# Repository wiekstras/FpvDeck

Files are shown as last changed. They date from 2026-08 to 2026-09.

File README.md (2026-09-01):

<p align="center">
  FpvDeck — radio, video, flight computer
</p>

<p align="center">
  
  
  
</p>

# FpvDeck

FpvDeck is a custom FPV handheld computer and radio built around a RadioMaster
T8L donor controller. It keeps ELRS control independent while adding low-latency
analog video, a large HD color display, modern RGB overlays, local flight data,
capacitive multi-touch, and modular applications in one field-ready device.

The desktop product shell works today without hardware, and a minimal real-video
Prototype 0 now has selected orderable reference hardware and V4L2 software support.
The final RF, video-decoder,
power, battery-measurement, and enclosure designs remain engineering prototypes;
this repository calls that distinction out rather than presenting renders as
finished hardware.

## Preview

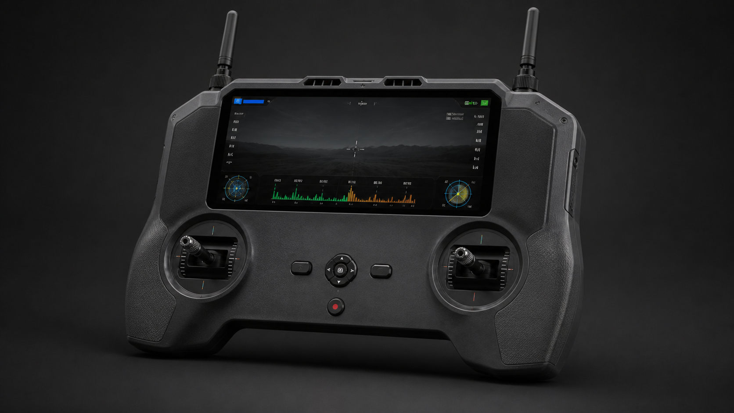
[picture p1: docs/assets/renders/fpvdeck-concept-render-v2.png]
FpvDeck concept with a large integrated display and pinch-grip geometry


> **CONCEPT RENDER — NOT FINAL DESIGN OR CAD.** Dimensions, component fit,
> thermal behavior, antenna placement, and T8L geometry are unverified. The
> larger high-mounted screen and pinch-grip clearance express product direction.

| Desktop product shell | FPV view: source pixels + independent RGB overlay |
| --- | --- |
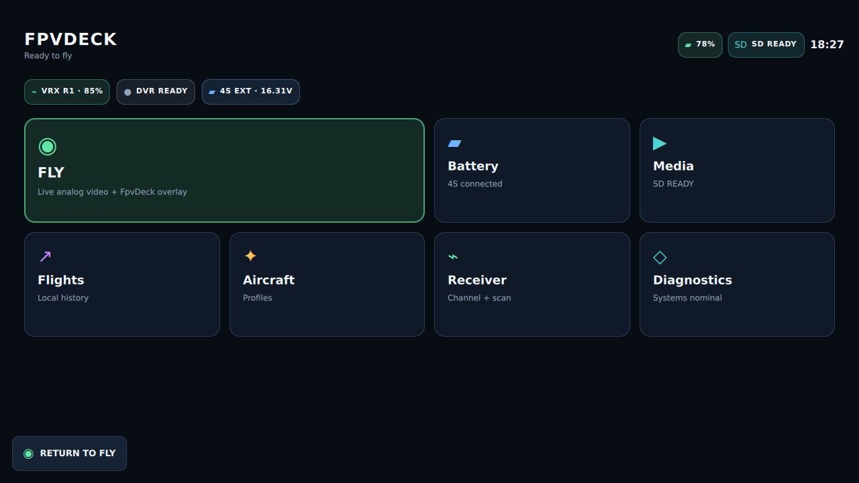
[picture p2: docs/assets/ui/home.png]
FpvDeck home
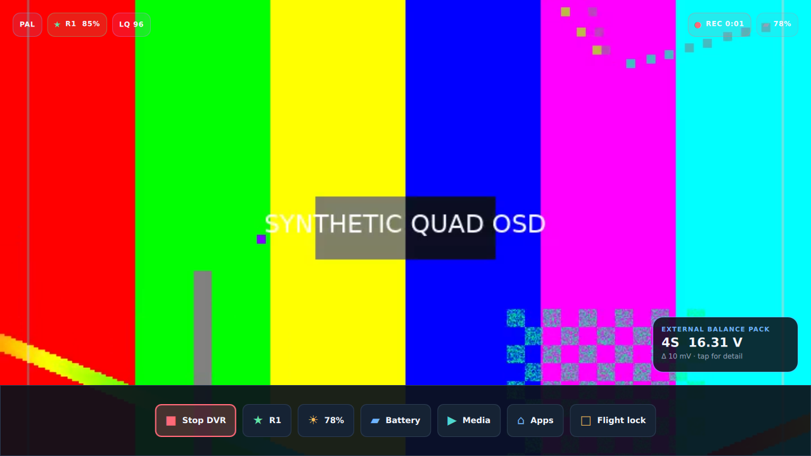
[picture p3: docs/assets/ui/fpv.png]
FpvDeck FPV app
|  |  |
| Balance checker simulation | Diagnostics and backend status |
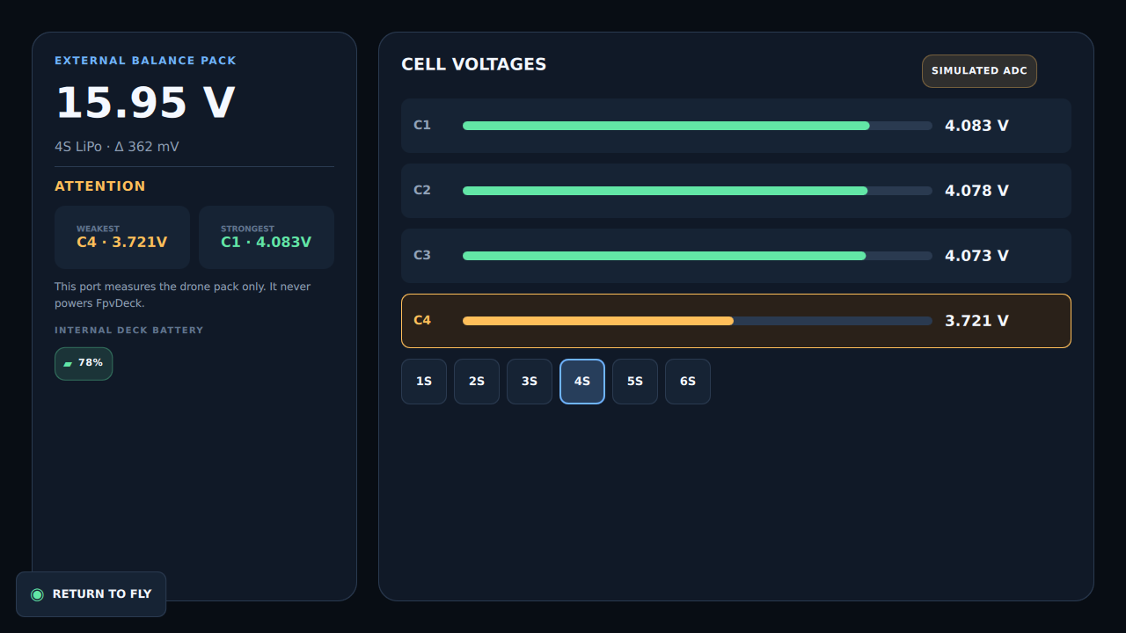
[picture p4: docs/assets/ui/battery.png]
FpvDeck balance checker
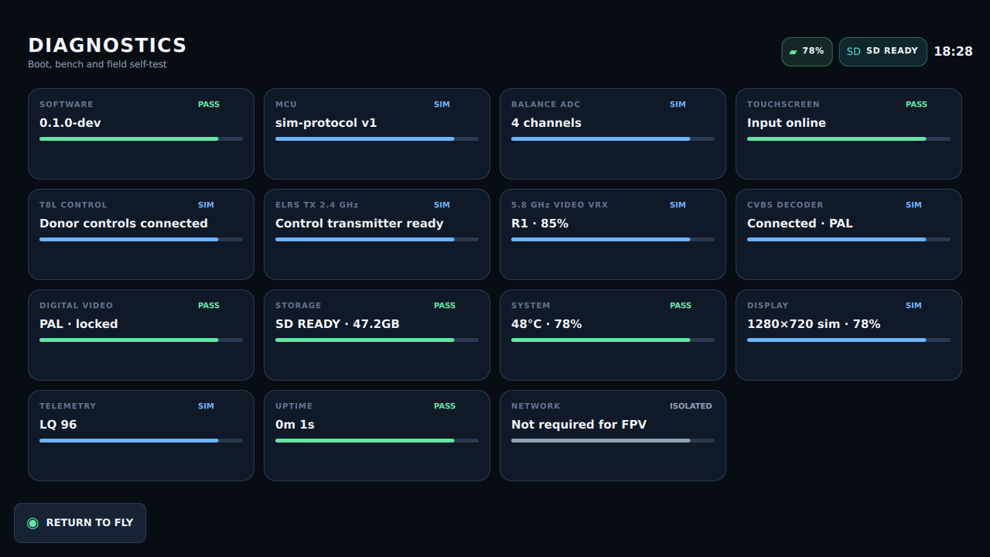
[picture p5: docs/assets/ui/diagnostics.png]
FpvDeck diagnostics
|  |  |

All screenshots are generated by the real application with deterministic test
data. [Media browser](docs/assets/ui/media.png),
[touch playback](docs/assets/ui/media-playback.png),
[receiver controls](docs/assets/ui/receiver.png), and
[flight history](docs/assets/ui/flights.png) are also reproducible.

## Features

- T8L gimbals, switches, ELRS control electronics, and RF path reused where safe
- analog FPV reception with the Betaflight OSD preserved in the received image
- GPU-composited full-color widgets, menus, notifications, and applications
- inexpensive official 5-inch Touch Display 2 for Prototype 0; larger 6.25-inch
  DSI panel remains the pinch-grip-oriented latency-bench direction
- touch-first shell with large targets, FPV auto-hide controls, and flight lock
- pre-overlay DVR architecture and optional composited recording branch
- protected external 1S–6S balance checking; 8S remains under evaluation
- local SQLite flight, battery, aircraft, and recording data
- removable-card media workflow, controller diagnostics, and fault simulation
- real/simulated backend boundary for every hardware-dependent service
- independent real-time MCU for measurement, controls, power, and watchdog duties

## Radio & Video

**Radio control:** the donor RadioMaster T8L supplies its built-in 2.4 GHz ELRS
transmitter, associated ELRS RF path/antenna, Hall gimbals, useful switches and
the controller electronics required to operate them.

**FPV video:** FpvDeck adds a separate 5.8 GHz analog VRX. That receiver converts
5.8 GHz RF to CVBS; a second, distinct video-decoder stage converts CVBS to a
digital stream for the SBC. The T8L and ELRS transmitter do not receive video.

## Architecture

FpvDeck system architecture

The flight-control path never depends on Linux. Analog video flows from the
aircraft through diversity VRX and a field-rate decoder; the Linux compositor
adds FpvDeck graphics without altering the embedded Betaflight OSD. Editable
[overall](docs/assets/diagrams/overall-system.mmd),
[video](docs/assets/diagrams/video-pipeline.mmd),
[power](docs/assets/diagrams/power-architecture.mmd), and
[software](docs/assets/diagrams/software-architecture.mmd) diagram sources live
with the documentation.

## Applications

| Application | Current state |
| --- | --- |
| FPV | ✅ touch controls/flight lock; 🧪 file video, signal faults, DVR, telemetry and battery overlay |
| Balance Checker | 🧪 1S–6S simulation and battery math implemented; 📐 protected ADC frontend in design |
| Media | ✅ touch browser/playback UI; 🧪 removable-card lifecycle and recordings |
| Flights | ✅ SQLite schema, migrations, deterministic history, and persistence |
| Batteries | 🧪 application shell/showcase data; 🚧 persistent inventory workflow pending |
| Aircraft | 🧪 application shell; 🚧 persistent profile workflow pending |
| DVR | ✅ live-capture pre-overlay recorder plumbing; 🧪 file-source state/faults; 🚧 target codec and power-loss validation pending |
| Receiver | ✅ channel/favorite/scan UI; 🧪 RF state and scan results |
| Diagnostics | ✅ detailed UI and simulated faults; 🧪 host self-test CLI; 📐 physical HIL pending |
| Settings | ✅ physical-input-friendly application shell; 🚧 durable settings pending |

## Simulator

FpvDeck is deliberately useful before physical hardware exists. On a supported
Linux development machine, install the packages in [BUILD.md](docs/BUILD.md),
then run:

```sh
./scripts/demo       # deterministic showcase home
./scripts/dev        # normal development session
./scripts/check      # build and run the complete automated test suite
```

The generated PAL/NTSC-style source contains synthetic “quad OSD” pixels. FpvDeck
widgets are rendered above it as a separate layer. Mouse clicks act as touch.
Use arrows/Enter for focus navigation, `M` for the application menu, `R` for DVR,
`B` for the battery widget, `L` for signal loss, `F10` for fault injection, and
`Esc` to return. The real product
will retain physical control paths for critical actions.

Rebuild the committed previews with `./scripts/screenshot-demo`.

## Prototype 0: real Air65 video

The next milestone uses the owned Air65 as a real analog source. The deliberately
pragmatic chain is RC832 Mini → Gembird UVG-002 → Raspberry Pi 5 → official
5-inch capacitive Touch Display 2. It proves RF reception, V4L2 ingestion, touch,
overlay, apps and DVR before spending final-product money or waiting for a custom PCB.

- **[Buy the short reference list tonight](hardware/PROTOTYPE_0_BUY_TONIGHT.md)**
- [Assemble and launch Prototype 0](docs/PROTOTYPE_0_SETUP.md)
- [Exact wiring](hardware/prototype-0/WIRING.md)
- [Air65 bench test](docs/AIR65_TESTING.md)

On Pi hardware, `./scripts/fpvdeck-video-list` enumerates capture formats,
`./scripts/test-video` validates raw V4L2 independently, and
`./scripts/prototype0` launches real capture with safe simulated-service fallback.

## Hardware

| Subsystem | Prototype direction | Status |
| --- | --- | --- |
| T8L / ELRS | preserve donor control/RF path; characterize read-only interfaces | ❓ teardown measurements required |
| Compute | Raspberry Pi CM4 for bench; i.MX 8M Plus production lead | 📐 selected direction, not validated |
| Display | Waveshare 6.25inch DSI LCD (B), SKU 35000; 720×1560, IPS, 5-point touch | 📐 selected for bench, measurements pending |
| Analog VRX | dedicated Skyzone SteadyView X 5.8 GHz RF-to-CVBS module lead | 📐 specs/EU stock verified; purchase waits for full chain gate |
| CVBS decoder | separate ADV728x-M CVBS-to-CSI evaluation path; TW9992 production investigation | 📐 EVM stock and SMA-to-CM4 bridge unresolved |
| Controller | STM32G0B1CBT6 lead over versioned COBS/CRC protocol | ✅ host-tested command core; 📐 target HAL pending |
| Balance ADC | ADS8688A + matched 31 kΩ/10 kΩ dividers | 🧪 error model; 📐 physical validation required |
| Power | donor's two 18650 cells, managed shutdown, modular rails | ❓ series/parallel and charger topology need measurement |
| Test PCB Rev A | MCU, ADC, protected-input intent, probes, module headers | 🚧 placed/unrouted; **not released for fabrication** |
| Prototype 0 | Pi 5 2 GB + 5-inch Touch Display 2 + RC832 Mini + UVG-002 | ✅ selected/orderable; 🚧 physical test awaits parts |

No PCB or battery frontend in this repository is approved for fabrication or pack
connection. Unknown interfaces are labeled **UNKNOWN** or **NEEDS MEASUREMENT**.

## Project status

Legend: ✅ implemented · 🚧 in development · 🧪 simulated · 📐 hardware design ·
❓ research/unconfirmed

- ✅ desktop Qt 6/QML application, service interfaces, SQLite migrations, and CI
- ✅ V4L2 device discovery/backend selection and a complete Prototype 0 order/setup path
- 🧪 video, balance battery, telemetry, touch/input, media/storage, DVR, and faults
- 📐 low-latency bench chain and Test PCB Rev A; board routing/review gates remain
- ❓ T8L internal pinout/mechanics and final display/enclosure geometry

This is pre-release engineering work, not a product ready for flight-critical
reliance. Performance targets in the documents are gates, not measured claims.

## Development

The monorepo keeps firmware, Qt/C++ software, protocols, KiCad projects, research,
and tests together. Start with [CONTRIBUTING.md](CONTRIBUTING.md) and
[DEVELOPMENT.md](docs/DEVELOPMENT.md). Important decisions are recorded in
[ENGINEERING_LOG.md](ENGINEERING_LOG.md), while incomplete work remains in
[TODO.md](TODO.md). The compatibility-gated [EU order list](hardware/ORDER_LIST_EU.md)
and [buy-now list](hardware/BUY_NOW.md) separate safe bench purchases from the
unresolved video chain and unreleased bare PCB.

## Documentation

- [Complete documentation index](docs/README.md)
- [Prototype 0 order list](hardware/PROTOTYPE_0_BUY_TONIGHT.md) · [setup](docs/PROTOTYPE_0_SETUP.md) · [wiring](hardware/prototype-0/WIRING.md)
- [System architecture](docs/ARCHITECTURE.md) · [hardware architecture](docs/HARDWARE_ARCHITECTURE.md)
- [Video pipeline](docs/VIDEO_PIPELINE.md) · [latency budget and measurement](docs/LATENCY.md)
- [T8L integration](docs/T8L_INTEGRATION.md) · [safe reverse engineering](docs/REVERSE_ENGINEERING.md)
- [Power](docs/POWER.md) · [battery measurement](docs/BATTERY_MEASUREMENT.md)
- [Software](docs/SOFTWARE_ARCHITECTURE.md) · [app API](docs/APP_API.md) · [MCU protocol](docs/MCU_PROTOCOL.md)
- [Touch UX](docs/TOUCH_UX.md) · [simulator](docs/SIMULATOR.md) · [testing](docs/TESTING.md)
- [Performance targets and benchmark](docs/PERFORMANCE.md)
- [Test PCB bring-up](docs/TEST_PCB_BRINGUP.md) · [EU order list](hardware/ORDER_LIST_EU.md) · [buy now](hardware/BUY_NOW.md) · [procurement gates](hardware/PROCUREMENT_PLAN.md)
- [Component decisions](hardware/research/COMPONENT_SELECTION.md) · [Test PCB BOM](hardware/bom/TEST_PCB_REV_A.md) · [risk register](docs/RISK_REGISTER.md)

## Roadmap

1. **v0.1 simulator + Prototype 0:** show real Air65 analog video with FpvDeck's
   overlay on the capacitive touchscreen, then complete bounded DVR tests.
2. **v0.2 latency bench:** measure VRX → decoder → compositor → display latency and RF,
   ADC, power, display, and shutdown behavior.
3. **v0.3 controller PCB:** protected measurement, MCU, controls, sequencing,
   connectors, debug, and manufacturing self-test.
4. **v0.4 integrated prototype:** measured compute carrier and enclosure revision.
5. **v1.0:** field-validated, documented, serviceable hardware.

See the maintained [roadmap](docs/ROADMAP.md) and [TODO](TODO.md) for acceptance
criteria rather than release-date promises.

## License

The existing repository license is [MIT](LICENSE). Hardware release licensing
will be clarified before fabrication files are published as production-ready.

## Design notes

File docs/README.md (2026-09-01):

# FpvDeck documentation

FpvDeck has two independent RF paths: the donor T8L supplies 2.4 GHz ELRS radio
control, while FpvDeck adds its own 5.8 GHz analog video receiver. The external
balance port measures an aircraft battery only; it never powers the deck.

## Start here

- [Prototype 0: parts arrived, now build it](PROTOTYPE_0_SETUP.md)
- [Buy Prototype 0 tonight](../hardware/PROTOTYPE_0_BUY_TONIGHT.md)
- [Prototype 0 architecture and wiring](../hardware/prototype-0/README.md)
- [Air65 real-video testing](AIR65_TESTING.md)
- [System architecture](ARCHITECTURE.md)
- [Hardware architecture](HARDWARE_ARCHITECTURE.md)
- [Software architecture](SOFTWARE_ARCHITECTURE.md)
- [Roadmap](ROADMAP.md), [risk register](RISK_REGISTER.md), and
  [repository TODO](../TODO.md)

## Video, display, and latency

- [Video pipeline](VIDEO_PIPELINE.md)
- [Latency budget and measurement](LATENCY.md)
- [Performance targets](PERFORMANCE.md)
- [Touch interaction design](TOUCH_UX.md)

## Donor, power, and measurement

- [T8L integration boundary](T8L_INTEGRATION.md)
- [Safe T8L reverse engineering](REVERSE_ENGINEERING.md)
- [Power architecture](POWER.md)
- [External battery measurement](BATTERY_MEASUREMENT.md)
- [Balance ground-fault analysis](BALANCE_GROUND_FAULT_ANALYSIS.md)

## Software and testing

- [Application/service API](APP_API.md)
- [Data model](DATA_MODEL.md)
- [MCU protocol](MCU_PROTOCOL.md)
- [Simulator](SIMULATOR.md)
- [Build](BUILD.md), [development](DEVELOPMENT.md), and [testing](TESTING.md)

## Hardware prototypes

- [Prototype stages](PROTOTYPES.md)
- [Test PCB bring-up](TEST_PCB_BRINGUP.md)
- [Test PCB Rev A project](../hardware/pcb/test-board-rev-a/README.md)
- [EU order list](../hardware/ORDER_LIST_EU.md) and
  [procurement gates](../hardware/PROCUREMENT_PLAN.md)
- [Component research](../hardware/research/COMPONENT_SELECTION.md)

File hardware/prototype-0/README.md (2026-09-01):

# Prototype 0 — Bench FpvDeck

Prototype 0 is the fastest real hardware vertical slice. It proves the radio,
analog video, Linux capture, RGB compositor, touch UI and recording workflow on
a desk. It is explicitly a **functionality test**, not a latency benchmark.

```text
                  RADIO CONTROL

RadioMaster T8L
      │
      └── 2.4 GHz ELRS ───────────────────────→ Air65

                       VIDEO

Air65 analog camera + Betaflight OSD
      │
      └── onboard 5.8 GHz analog VTX
                       │
                       ▼
                  RC832 Mini VRX
                       │  CVBS (yellow RCA)
                       ▼
                 Gembird UVG-002
                       │  USB / V4L2
                       ▼
                 Raspberry Pi 5
                       │
                FpvDeck software
                   ↙          ↘
              FPV video      RGB UI
                   ↘          ↙
              5-inch Touch Display 2
```

## Reference hardware

- Raspberry Pi 5 2 GB + official 27 W supply + Active Cooler
- Raspberry Pi Touch Display 2, 5 inch, SC1975
- RC832 Mini 56-channel receiver kit from Rotorama
- Gembird UVG-002, UTV007/UTVF007 chipset family
- separate protected 12 V receiver supply

See [Buy Tonight](../PROTOTYPE_0_BUY_TONIGHT.md), [Wiring](WIRING.md), and the
[complete setup guide](../../docs/PROTOTYPE_0_SETUP.md).

## Exit criteria

- T8L remains bound and controls the Air65; props remain removed on the bench.
- The receiver shows the Air65 feed and embedded Betaflight OSD.
- Linux exposes UVG-002 through V4L2 (`usbtv` for UTV007 or `uvcvideo` for
  UTVF007) and reports a usable PAL or NTSC-derived stream.
- FpvDeck renders full-colour overlays over live video without app failure.
- Touch, menus, signal loss/reconnect and a short DVR recording work.
- Capture latency is recorded as a baseline, not accepted as a final target.

## Later stages

| Stage | Purpose |
|---|---|
| Prototype 0 | Functionality: real RF video, touch, apps and recording |
| Prototype 1 | Latency: direct decoder and display-path measurements |
| Prototype 2 | Modular custom controller/balance/power PCB |
| Prototype 3 | Integrated, mechanically validated FpvDeck |

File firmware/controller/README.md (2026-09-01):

# FPVDeck controller firmware

This directory contains the allocation-free, host-tested wire protocol and a
hardware-abstraction-backed Test PCB command dispatcher. It is not yet a flashable
board target because Rev A routing and clock/power configuration are not released.
Clock, GPIO, USB, ADC, watchdog, power, and boot configuration will be generated
only after the exact MCU/package and Rev A schematic are frozen from datasheets.

Firmware responsibilities: independent watchdog, debounced navigation inputs,
ADS70xx/ADS8688 sampling, temperatures/fan, power button and shutdown state
machine, rail-good monitoring, buzzer/LED/haptics, device identity, heartbeat,
and failure-safe outputs. Flight-control gimbal data remains on the T8L board.

The host tests exercise ADC/tap reads, self-test masks, output commands and unknown
command handling without an STM32 HAL. Board-specific STM32Cube startup, USB CDC,
ADS8688A SPI and watchdog code is the next layer once the schematic pin review is
closed; keeping it out now avoids generating unsafe pin assignments from a draft.

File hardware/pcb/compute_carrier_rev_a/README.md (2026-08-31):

# Compute carrier Rev A KiCad project

Project container only. CSI/DSI/USB/CM4 connectivity will be copied from verified
manufacturer design files and reviewed against the selected stackup before any
schematic or PCB is marked fabrication-ready.

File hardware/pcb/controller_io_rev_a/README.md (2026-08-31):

# Controller-I/O Rev A KiCad project

The KiCad project container exists, but schematic/PCB capture is intentionally
blocked on ADC EVM results, T8L measurements, MCU pin budget, power fault analysis,
and verified manufacturer footprints. An empty project is safer than invented
connectivity. See `TODO.md` and `docs/PROTOTYPES.md` for the release gates.

Planned sheets: power entry/sequencing, MCU/debug, protected balance frontend,
controls, thermal/fan/buzzer, modular T8L/VRX/compute interfaces, and test points.

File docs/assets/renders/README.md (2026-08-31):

# FpvDeck renders

`fpvdeck-concept-render-v2.png` is a **CONCEPT RENDER**, not final design, CAD,
or evidence that the illustrated layout fits the T8L. It communicates the current
product direction: a larger high-mounted display, separated gimbals, and clear
pinch-grip finger envelopes. Version 1 is retained as design history.

Final mechanical renders require measured, datum-controlled inputs for:

- T8L external shell, seams, wall thickness, and grip geometry
- gimbal centers, outer envelopes, stick travel, stick height, and fasteners
- PCB outline, component heights, mounting points, and cable exits
- switch/button positions, travel, keepouts, and wiring
- ELRS antenna location, feed routing, and RF keepout
- 18650 compartment, contacts, latch, and insulation
- display active area, glass, PCB, FFC, backlight, and mounting stack
- VRX, decoder, compute module/carrier, cooling, and shielding volumes
- USB-C, removable storage, balance connector, debug, and antenna connectors
- enclosure bosses, wall/impact requirements, seals, and disassembly paths
- center of mass, neck-strap balance, palm support, and thumb/pinch user trials

Generated concepts must never be used as a dimensional reference or PCB-layout
input. See [mechanical requirements](../../MECHANICAL_REQUIREMENTS.md).

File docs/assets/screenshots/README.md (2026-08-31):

# Physical and bench screenshots

Reserved for measured bench setups, HIL fixtures, PCB bring-up, and physical
prototype evidence. Include revision, date, test conditions, and source/license.
Simulator product captures belong in `../ui/`; generated product concepts belong
in `../renders/`.

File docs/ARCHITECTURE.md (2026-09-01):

# System architecture

Overall FpvDeck system

FpvDeck keeps the safety-critical control radio independent of Linux. The T8L
donor remains able to generate and transmit ELRS control even when the compute
side is powered down, booting, overloaded, or crashed.

```text
                         CONTROL PLANE (independent)
 T8L gimbals/switches ──> T8L controller ──> ELRS 2.4 GHz ──> aircraft
                                  │ optional, read-only status/telemetry later
                                  ▼
                         MCU hardware controller
                                  │ COBS + CRC protocol
                                  ▼
 FPV camera -> FC OSD -> 5.8 GHz VTX -- RF --> dedicated 5.8 GHz VRX -> CVBS
                                                    -> CVBS decoder -> CSI-2 -> Linux SoM
                                                                    │
                     ┌──────────────────────────────────────────────┤
                     │ VideoService: bounded live path              │
                     │ Recorder branch: pre-overlay encode          │
                     │ Qt Quick/DRM compositor: color UI overlay     │
                     └──────────────────────────────────────────────┤
                                                                    ▼
                                                               MIPI DSI LCD
```

The received Betaflight OSD is pixels in Layer 1. FPVDeck never tries to recreate
or insert that analog OSD. Layer 2 contains glanceable system widgets; Layer 3
contains transient menus/apps. Secondary service failure must not block Layer 1.

## Prototype architecture

The T8L/ELRS path is control only. FpvDeck's dedicated VRX performs RF-to-CVBS;
the decoder performs CVBS-to-digital conversion; neither function is supplied by
the donor radio.

The simulator is the pre-hardware product showcase. Prototype 0 is the deliberately
simple Pi 5 + 5-inch Touch Display 2 + RC832 Mini + UVG-002 functionality bench;
it exists to show real Air65 video before latency optimization. Prototype 1 is a CM4
latency bench with the selected 720×1560 DSI touch module, ADV7282A-M evaluation
hardware, standalone SteadyView X VRX, STM32G0 development board, and protected
ADC evaluation hardware. Each module remains replaceable, and the analog-video
modules remain procurement-gated until the decoder-to-CM4 bridge is reviewed.

Prototype 2 is a Controller-I/O PCB: MCU, protected battery measurement, controls,
power button/sequencing logic, fans/temperature, debug, and module connectors.
Prototype 3 integrates only interfaces whose layout, thermal, EMC, and latency
behavior has been proven on the bench, including a compute carrier as justified.

## Performance gates

| Metric | Initial target | Release method |
| --- | ---: | --- |
| CVBS connector to visible photons | p95 ≤45 ms; stretch ≤33 ms | LED/photodiode fixture, ≥1,000 transitions |
| Live video continuity under app crash | no missing live frames attributable to app | fault injection + capture counter |
| UI | 60 Hz when live path has headroom | frame timing trace |
| Video | every source field represented at 50/59.94 Hz | V4L2/DRM sequence correlation |
| DVR start acknowledgement | <500 ms | monotonic event log |
| Channel switch/relock | <500 ms target, measured by mode | RF generator/VTX fixture |
| Warm boot to live video | <8 s target | power-cycle fixture; live path may precede full shell |
| Normal shutdown | database/storage clean after 1,000 cycles | automated power controller |
| FPV runtime | ≥1.25 h target; 1.5 h stretch at typical brightness | measured two-cell pack test |

Targets are engineering gates, not current measured results.

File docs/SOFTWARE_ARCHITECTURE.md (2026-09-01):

# Software architecture

FpvDeck software architecture

FPVDeck is a single-purpose Qt 6 application launched directly into a DRM/KMS
session. There is no desktop environment. Systemd owns process lifetime and a
small supervisor restarts noncritical workers independently.

```text
QML apps/widgets
   │ stable QObject APIs, queued signals, immutable snapshots
AppManager ──────────────────────────────────────────────┐
   │                                                     │
Video Battery Telemetry Input DVR Radio Storage Media Interaction System Database
   │                                                     │
real backend / simulated backend / replay backend        │
   └──────────── isolated drivers and worker processes ──┘
```

VideoService and the compositor are the protected core. Network, history,
battery UI, and settings can restart without taking down capture. DVR receives a
tee and cannot exert backpressure. UI effects are disabled under missed-frame or
temperature pressure.

Qt/QML was chosen over Flutter, Electron/web, and a bespoke OpenGL shell. Qt has
mature embedded KMS/Wayland-less deployment, C++/V4L2 integration, a retained
GPU scene graph, physical focus navigation, and SQLite. Electron is rejected for
runtime/boot/memory cost; Flutter's Linux embedded/video interop adds ecosystem
risk; bespoke rendering would spend effort recreating accessibility, text, and
layout infrastructure.

The repository currently implements Battery, Video, Radio/VRX, DVR, Telemetry, Input,
Storage, Media, Interaction, System, and Database services. Hardware-dependent
state has a deterministic simulator path. The QML pages consume these QObject
contracts and do not open serial ports, mount cards, or sample ADCs themselves.
Diagnostics reports T8L/ELRS control, dedicated 5.8 GHz VRX, CVBS decoder and
digital-video health independently. `RadioService` owns receiver channel, RSSI,
favorites and scan state; `VideoService` owns source standard, decoder/capture
lock state and backend selection (`simulated`, `file`, or `v4l2`). The Prototype 0
QCamera session feeds the same VideoOutput used by file playback; its recorder
tee receives camera frames before the QML overlay. This prevents an RF channel change from masquerading as a
decoder API and leaves room for separate real backends.

InteractionService owns transient FPV controls, flight-lock navigation policy,
and touch-debug state. A lock rejection is explicit and testable. StorageService
models the removable-card lifecycle independently from MediaService playback;
this prevents a media view from inventing mount behavior. SystemService owns
deck power/thermal/connectivity state used by Home and Diagnostics.

The current implementation is one process for desktop iteration. The embedded
architecture will move capture/recording and noncritical workers across bounded
IPC boundaries where failure isolation or privilege separation is justified.
That split must preserve the service contracts rather than exposing driver APIs
to QML.

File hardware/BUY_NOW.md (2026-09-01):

# Buy now — EU bench kit

> **Prototype 1 archive — do not use this list for tonight's functional bench.**
> The current short, complete Prototype 0 purchase decision is
> [PROTOTYPE_0_BUY_TONIGHT.md](PROTOTYPE_0_BUY_TONIGHT.md). The CM4/direct-decoder
> items below remain later latency-bench research.

Checked 2026-09-01. Prices and stock are snapshots, not quotations; open every
linked product page and verify exact MPN, VAT destination, stock, and connector
contents at checkout. This list intentionally excludes the analog-video chain
until its decoder-to-CM4 bridge is credible.

## Already provided by the donor — do not buy again

- RadioMaster T8L and its 2.4 GHz ExpressLRS transmitter/RF path;
- two Hall gimbals and usable T8L switches/buttons;
- T8L control electronics;
- dual-18650 compartment/arrangement, pending electrical verification.

The T8L provides **no 5.8 GHz analog VRX, CVBS decoder, HD display, removable
media reader, or external-battery measurement frontend**.

## Purchase-cleared independent bench items

| Qty | Exact item | EU source snapshot | Purpose |
| ---: | --- | --- | --- |
| 1 | Raspberry Pi `CM4104032`, CM4 4 GB/32 GB eMMC/WLAN | [BerryBase, €127.10 incl. VAT](https://www.berrybase.de/en/raspberry-pi-compute-module-4-4gb-ram-32gb-flash-wlan-bt) ([Farnell alternative, €138.23 incl. VAT](https://nl.farnell.com/en-NL/raspberry-pi/cm4104032/rpi-module-4-4gb-ram-32gb-emmc/dp/3563490?gross_price=true)) | Linux/video/UI evaluation |
| 1 | Raspberry Pi Compute Module 4 IO Board | [BerryBase, €35.90 incl. VAT](https://www.berrybase.de/en/raspberry-pi-compute-module-4-io-board) ([Rasppishop alternative, €35.90 incl. VAT](https://www.rasppishop.de/CM4-IO-Board)) | documented CSI/DSI/USB carrier |
| 1 | Waveshare `6.25inch DSI LCD (B)`, SKU 35000 | [OpenELAB Germany, €74.95 incl. VAT](https://openelab.de/products/waveshare-6-25inch-dsi-lcd-b-capacitive-touch-display) ([manufacturer direct, about €52 before import/VAT](https://www.waveshare.com/product/luckfox/6.25inch-dsi-lcd-b.htm)) | selected 720×1560 five-touch bench display |
| 1 | Waveshare `19134` CM4 DSI adapter | [BerryBase listing on CM4IO page, €2.50 incl. VAT](https://www.berrybase.de/en/raspberry-pi-compute-module-4-io-board) | 22-pin CM4IO to display FFC adaptation; verify included cables first |
| 1 | Mean Well `GST36E12-P1J`, 12 V/3 A | [Reichelt, €14.95 incl. VAT](https://www.reichelt.de/de/de/shop/produkt/steckernetzteil_36_w_12_v_3_a-171106) ([Farnell alternative, €18.23 ex VAT](https://de.farnell.com/en-DE/mean-well/gst36e12-p1j/adaptor-ac-dc-12v-3a/dp/2815899)) | isolated CM4IO bench supply; lab supply remains preferred for fault work |
| 1 | ST `NUCLEO-G0B1RE` | [Mouser, €16.80 snapshot](https://www.mouser.es/es/ProductDetail/STMicroelectronics/NUCLEO-G0B1RE?qs=pUKx8fyJudAJjwoMOxyZhg%3D%3D) ([ST product page](https://www.st.com/en/evaluation-tools/nucleo-g0b1re.html)) | firmware/USB/SPI bring-up without Test PCB |
| 1 | ST `STLINK-V3SET` | [Mouser Germany, €39.10 snapshot](https://www.mouser.de/de/ProductDetail/STMicroelectronics/STLINK-V3SET?qs=qSfuJ%252Bfl%2Fd5d4WYsOW6M6w%3D%3D) ([V3MINIE smaller alternative](https://www.mouser.de/de/ProductDetail/STMicroelectronics/STLINK-V3MINIE?qs=MyNHzdoqoQKcLQe5Jawcgw%3D%3D)) | external SWD/debugger; Nucleo's onboard probe covers the first firmware step |
| 1 | Transcend `TS-RDF5K` USB-A SD/microSD reader | [Reichelt, €7.95 incl. VAT](https://www.reichelt.de/de/de/shop/produkt/card_reader_extern_usb_3_2_gen_1_schwarz_rdf5-147618) ([white TS-RDF5W alternative](https://www.reichelt.de/de/de/shop/produkt/card_reader_extern_usb_3_0_weiss_rdf5-147619)) | removable goggle/DVR media on CM4IO USB; not internal eMMC storage |
| 1 | SanDisk `SDSQQNR-128G-GN6IA` High Endurance 128 GB | [MediaMarkt, €33.99 incl. VAT](https://www.mediamarkt.de/de/product/_sandisk-high-endurance-2551316.html) ([current EU offer index](https://geizhals.de/sandisk-high-endurance-r100-w60-microsdxc-128gb-kit-sdsqqnr-128g-gn6ia-a2041130.html)) | repeatable removable-media/DVR endurance testing |

Nominal purchase-cleared subtotal: **€353.24 incl. VAT where shown**, excluding
shipping and assuming the lower-priced debugger/card/display sources above. Add a
10% cable/adapter contingency: **€388.56**. This is not the whole Prototype 1.

## Buy small samples, not a board build

- 2× JST `B7B-XH-A(LF)(SN)` from [Mouser Germany](https://www.mouser.de/ProductDetail/JST-Commercial/B7B-XH-ALFSN?qs=cdbOS8ANM9DLeRSemn13Pg%3D%3D) for exact footprint/fit inspection.
- 1–2× ADS8688AIDBT only if useful for stocking consolidation; the package cannot
  be meaningfully evaluated on a solderless breadboard. [Mouser Europe showed
  €25.08 and stock](https://eu.mouser.com/en/ProductDetail/Texas-Instruments/ADS8688AIDBT?qs=xufs61hA5MZv%2F46DP%252BYoHw%3D%3D).
- mating XH housings/contacts only for a keyed simulator harness; never construct
  a lead capable of backfeeding a real pack.

## Explicitly not purchase-cleared

- SteadyView X 5.8 GHz VRX: product stage is credible, but the complete
  VRX→decoder→CM4 chain has not passed its gate;
- `EVAL-ADV7282AMEBZ`: restricted distributor availability and no reviewed
  SMA-to-CM4IO CSI bridge;
- Test PCB bare boards, stencil, or full component quantities;
- another ELRS transmitter module, extra 18650s, charger/power board, or T8L
  internal harnesses.

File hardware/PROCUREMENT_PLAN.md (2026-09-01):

# Prototype procurement plan

> Prototype 0 now overrides this older Prototype 1 purchasing sequence. Order the
> [short reference chain](PROTOTYPE_0_BUY_TONIGHT.md), prove real Air65 video, and
> leave every direct-decoder/custom-PCB item below paused until evidence is logged.

## Order now

These items unlock independent work even if the custom PCB changes:

- Raspberry Pi CM4 eMMC module and official CM4 IO Board;
- Waveshare 6.25inch DSI LCD (B), exact SKU 35000;
- NUCLEO-G0B1RE, STLINK-V3MINIE and 3.3 V USB-UART;
- JST XH connector samples and non-conductive bench hardware;
- high-endurance removable microSD;
- exact Test PCB semiconductors/passives in small spare quantities if shipping
  consolidation makes sense. These parts remain useful for breadboard/EVM work.

Immediate exit tests: display/touch boots in landscape, CM4 runs simulator,
firmware protocol runs on Nucleo, removable media mounts reliably, and all item
labels match their order records.

## Verify stock and interface before order

- Analog Devices `EVAL-ADV7282AMEBZ` or exact Pi-tested `EVAL-ADV7282MEBZ`.
  Obtain the exact user guide, board revision and seller stock confirmation.
  These boards expose MIPI lanes on SMA; price and design a controlled-impedance
  SMA-to-CM4IO CSI fixture before committing to the EVM purchase.
- ADS8688EVM-PDK. It is valuable but expensive; skip if unavailable or if Rev A
  board release is close.
- Skyzone SteadyView X 5.8 GHz kit. Its RF-to-CVBS stage is documented, but it may
  move from `WAIT` only when the decoder-to-CM4 bridge is reviewed. Current EU
  kits include a patch and an omni antenna; no separate initial antenna order.

## Order after Test PCB passes release review

- Test PCB Rev A bare boards, quantity 5;
- board-specific stencils and assembly tooling;
- exact SWD header/cable after its 1:1 footprint check;
- full quantities from `TEST_PCB_REV_A.csv`;
- a second ADC/MCU as immediate rework stock.

## Order after Test PCB bring-up passes

- components for a revised routed controller/power board;
- candidate 2S charger and 5 V buck-boost EVMs;
- protected cell fixture parts and thermal hardware;
- enclosure prototype materials tied to measured CAD.

## Wait

- final 18650 cells/pack, charging USB-C PD solution and production power PCB;
- custom integrated VRX RF circuitry;
- CM4 production carrier high-speed connectors;
- final enclosure, machined parts and final-length flex cables;
- T8L internal wiring harnesses based on unconfirmed pinouts.

The purpose of `WAIT` is to prevent sunk cost, not to stall bench work. Display,
compute, Nucleo, media and measurement equipment can be tested independently.

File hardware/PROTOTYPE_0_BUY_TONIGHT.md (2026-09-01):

# Prototype 0 — buy tonight

> **PROTOTYPE 0 STATUS: READY TO ORDER**<br>
> Procurement snapshot: **2026-09-01**, delivery country: Netherlands. Re-open
> every product page immediately before checkout because price and stock change.

Already owned:

- ✓ RadioMaster T8L — 2.4 GHz ELRS control donor
- ✓ BetaFPV Air65 analog — real 5.8 GHz video source

Required additional hardware and bring-up tools: **approximately €246.47 including VAT**<br>
Shipping estimate (BerryBase + Kiwi + Rotorama + Informatique): **€23–€35**<br>
Expected total tonight: **approximately €269–€282**<br>
Optional additions: **€3.30**, or **€70.80** if the owned Air65 has neither
a usable battery nor a charger

If a suitable multimeter and fine-wire cutter/stripper are already owned,
subtract **€20.00** from the hardware total. A computer with a microSD writer
and a small flat-blade terminal screwdriver are also required for assembly.

This list buys a functionality prototype, not the final low-latency or mechanical
architecture. The reference chain is:

`Air65 → 5.8 GHz → RC832 Mini → CVBS → UVG-002/V4L2 → Pi 5 → RGB overlay → Touch Display 2`

## Buy tonight

### 1. Compute

**Item:** Raspberry Pi 5, 2 GB<br>
**Exact product:** Raspberry Pi 5 2GB<br>
**Manufacturer:** Raspberry Pi Ltd<br>
**Model / MPN:** SC1642; seller SKU RPI5-2GB<br>
**Quantity:** 1<br>
**Purpose:** Runs capture, Qt/QML compositor, apps and DVR.<br>
**Primary EU seller:** BerryBase, Germany<br>
**DIRECT PRODUCT LINK:** <https://www.berrybase.de/raspberry-pi-5-2gb-ram><br>
**Current price:** €68.90 including German VAT<br>
**Stock status:** 100+ shown; 1–3 working days<br>
**Alternative EU seller:** Kiwi Electronics, Netherlands<br>
**Alternative direct link:** <https://www.kiwi-electronics.com/en/raspberry-pi-boards-363/raspberry-pi-5-2gb-20129><br>
**Alternative status:** exact board, but shown out of stock at this snapshot<br>
**Compatibility:** CONFIRMED with the selected display and USB 2.0 capture.<br>
**Why this exact item:** 2 GB is well above the current ~285 MiB simulator RSS,<br>
while Pi 5 gives useful headroom for software deinterlacing/compositing.<br>
**Required tonight:** YES<br>

### 2. Pi power

**Item:** Official 27 W USB-C supply, EU/white<br>
**Exact product:** Raspberry Pi 27W USB-C Power Supply, white EU<br>
**Manufacturer:** Raspberry Pi Ltd<br>
**Model / MPN:** SC1407<br>
**Quantity:** 1<br>
**Purpose:** Stable 5.1 V/5 A power for Pi, display and capture device.<br>
**Primary EU seller:** Kiwi Electronics, Netherlands<br>
**DIRECT PRODUCT LINK:** <https://www.kiwi-electronics.com/nl/raspberry-pi-27w-usb-c-power-supply-wit-eu-11581><br>
**Current price:** €10.89 excluding NL VAT, approximately €13.18 including VAT<br>
**Stock status:** 250+ shown; same-day dispatch before cutoff<br>
**Alternative EU seller:** BerryBase (seller SKU RPI5NT5AW; confirm EU plug at checkout)<br>
**Alternative direct link:** <https://www.berrybase.de/en/raspberry-pi-27w-usb-c-power-supply-netzteil-weiss><br>
**Compatibility:** CONFIRMED 5.1 V/5 A Pi 5 supply. It does **not** power the VRX.<br>
**Why this exact item:** Avoids Pi undervoltage during USB capture and recording.<br>
**Required tonight:** YES<br>

### 3. Cooling

**Item:** Official Raspberry Pi 5 Active Cooler<br>
**Exact product:** Raspberry Pi Active Cooler<br>
**Manufacturer:** Raspberry Pi Ltd<br>
**Model / MPN:** SC1148<br>
**Quantity:** 1<br>
**Purpose:** Prevents thermal throttling during capture/compositing/DVR.<br>
**Primary EU seller:** BerryBase<br>
**DIRECT PRODUCT LINK:** <https://www.berrybase.de/en/raspberry-pi-active-cooler-luefter-fuer-raspberry-pi-5?c=298><br>
**Current price:** €5.90 including VAT<br>
**Stock status:** 100+ shown; 1–3 working days<br>
**Alternative EU seller:** Kiwi Electronics<br>
**Alternative direct link:** <https://www.kiwi-electronics.com/nl/merk-raspberry-pi/raspberry-pi-active-cooler-11585><br>
**Alternative price/stock:** €4.49 excluding NL VAT; 250+ shown<br>
**Compatibility:** CONFIRMED for Pi 5.<br>
**Why this exact item:** Supported fan control and no enclosure fit uncertainty.<br>
**Required tonight:** YES<br>

### 4. System storage

**Item:** 64 GB microSD card<br>
**Exact product:** SanDisk Ultra microSDXC A1 140 MB/s Class 10 + adapter<br>
**Manufacturer:** Western Digital / SanDisk<br>
**Model / MPN:** SDSQUAB-064G-GN6MA; seller product 619659200541<br>
**Quantity:** 1<br>
**Purpose:** Raspberry Pi OS, FpvDeck and short DVR tests.<br>
**Primary EU seller:** BerryBase<br>
**DIRECT PRODUCT LINK:** <https://www.berrybase.de/sandisk-ultra-microsdhc-a1-140mb-s-class-10-speicherkarte-adapter-64gb><br>
**Current price:** €19.50 including VAT<br>
**Stock status:** 58 shown; 1–3 working days<br>
**Alternative EU seller:** Kiwi Electronics (pre-imaged Raspberry Pi-branded A2 card)<br>
**Alternative direct link:** <https://www.kiwi-electronics.com/nl/64gb-microsd-met-raspberry-pi-os-7377><br>
**Alternative price/stock:** €32.99 excluding NL VAT; 26 shown<br>
**Compatibility:** CONFIRMED boot storage; not claimed as long-term DVR endurance media.<br>
**Why this exact item:** Cheapest credible 64 GB boot volume; replace with High<br>
Endurance media after recording behavior is proven.<br>
**Required tonight:** YES<br>

### 5. Touchscreen

**Item:** 5-inch capacitive DSI touchscreen<br>
**Exact product:** Raspberry Pi Touch Display 2, 5 inch<br>
**Manufacturer:** Raspberry Pi Ltd<br>
**Model / MPN:** SC1975; Kiwi KW-3549<br>
**Quantity:** 1<br>
**Purpose:** Real landscape touch UX at 1280×720 logical orientation.<br>
**Primary EU seller:** Kiwi Electronics, Netherlands<br>
**DIRECT PRODUCT LINK:** <https://www.kiwi-electronics.com/nl/raspberry-pi-touch-display-2-5-inch-20517><br>
**Current price:** €36.49 excluding NL VAT, approximately €44.15 including 21% VAT<br>
**Stock status:** 10 shown; same-day dispatch before cutoff<br>
**Alternative EU seller:** Welectron, Germany<br>
**Alternative direct link:** <https://www.welectron.com/Official-Raspberry-Pi-Touch-Display-2-5-Portrait><br>
**Alternative price/stock:** €43.90 including 19% VAT; 50+ shown<br>
**Compatibility:** CONFIRMED. The box includes the Pi 5 22-to-15-way FFC, GPIO<br>
power lead and mounting screws; DSI carries video and touch.<br>
**Why this exact item:** Cheap for a documented five-point capacitive DSI display,<br>
with no HDMI bridge or separate USB touch cable. It is Prototype 0 hardware, not
the final large outdoor display.<br>
**Required tonight:** YES<br>

### 6. Analog video receiver

**Item:** 5.8 GHz analog FPV receiver kit<br>
**Exact product:** RC832 Mini receiver 4.9–5.8 GHz<br>
**Manufacturer:** UNKNOWN OEM; Rotorama is the identified EU vendor<br>
**Model / MPN:** RC832 Mini, Rotorama product 27309-1<br>
**Quantity:** 1<br>
**Purpose:** Receives Air65 5.8 GHz RF and outputs CVBS.<br>
**Primary EU seller:** Rotorama s.r.o., Czech Republic<br>
**DIRECT PRODUCT LINK:** <https://www.rotorama.com/product/rc832-mini-5ghz><br>
**Current price:** €55.49; checkout determines local VAT<br>
**Stock status:** In Stock; vendor states 2–3 working days within the EU and<br>
€6.49 GLS shipping to Holland<br>
**Alternative EU seller:** Fruugo NL marketplace, RC832S kit<br>
**Alternative direct link:** <https://www.fruugo.nl/fpv-rc832-rc832s-receiver-58g-48ch-600mw-aerial-photography-58ghz-av-receiver-system-with-av-and/p-464528452-976977969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><br>
**Alternative price/stock:** €57.63 + €12.99, in stock; marketplace/longer-chain<br>
fallback only<br>
**Compatibility:** CONFIRMED at signal level: 56 channels include standard A/B/E/F/R,<br>
PAL/NTSC 1.0 Vp-p into 75 Ω, 3.5 mm AV out, 12 V/130 mA, RP-SMA. The Rotorama
kit includes receiver, linear antenna, power cable and video cable.<br>
**Why this exact item:** It is the least-complex documented EU-stock receiver<br>
that arrives with the otherwise easy-to-miss antenna and proprietary AV lead.<br>
**Required tonight:** YES<br>

### 7. Composite USB capture

**Item:** Linux-supported PAL/NTSC composite capture<br>
**Exact product:** Gembird USB Audio/Video Grabber<br>
**Manufacturer:** Gembird Europe B.V.<br>
**Model / MPN:** UVG-002 / EAN 8716309079983<br>
**Quantity:** 1<br>
**Purpose:** Converts receiver CVBS to a V4L2 stream for the Pi.<br>
**Primary EU seller:** Informatique, Netherlands<br>
**DIRECT PRODUCT LINK:** <https://www.informatique.nl/490730/gembird-usb-audio-video-grabber.html><br>
**Current price:** €12.95 including NL VAT; €4.50 shipping shown<br>
**Stock status:** In stock in its warehouse; before-22:00 orders stated to ship today<br>
**Alternative EU seller:** bol.com Netherlands, sold by Kabeldirect.nl<br>
**Alternative direct link:** <https://www.bol.com/nl/nl/p/gembird-uvg-002-usb-videograbber-geschikt-voor-windows/9200000036282031/><br>
**Alternative price/stock:** €19.70 including NL VAT and delivery; in stock,<br>
next-business-day delivery stated at this snapshot<br>
**Compatibility:** CONFIRMED interfaces: yellow RCA composite input, USB-A 2.0,<br>
PAL 720×576/25 and NTSC 720×480/30. **SUPPORTED FAMILY, RECEIPT-GATED UNIT:**
Gembird documents UTV007 or UTVF007 silicon. UTV007 uses Linux's `usbtv` V4L2
driver; deployed UTVF007 units enumerate as UVC `534d:0021` and use `uvcvideo`.
Both routes expose V4L2 on Raspberry Pi, but the received USB ID, driver, format
and weak-signal behavior remain mandatory receipt tests because Gembird does not
guarantee which chipset is in a box. Return the unit if neither documented path
appears—never bind a driver to an unknown ID.<br>
**Why this exact item:** It is a named, returnable Dutch-stock €13 product with a<br>
manufacturer-declared chipset family, not an anonymous capture stick. It meets
Prototype 0's speed/cost goal; capture latency, deinterlacing and UTVF007's known
weak-signal squelch behavior still need measurement.<br>
**Required tonight:** YES<br>

### 8. Receiver power

**Item:** Protected regulated 12 V wall supply<br>
**Exact product:** PCEnergy 12 V DC 1 A plug-in PSU, 5.5×2.1 mm P1J<br>
**Manufacturer:** P+C Schwick / PCEnergy<br>
**Model / MPN:** PCE12-12-1-WM<br>
**Quantity:** 1<br>
**Purpose:** Dedicated supply for the 12 V/130 mA receiver.<br>
**Primary EU seller:** BerryBase<br>
**DIRECT PRODUCT LINK:** <https://www.berrybase.de/en/steckernetzteil-12v-dc-1a-12w-hohlstecker-5-5x2-1mm?c=393><br>
**Current price:** €5.90 including VAT<br>
**Stock status:** 53+ shown; 1–3 working days<br>
**Alternative EU seller:** BerryBase Goobay 64977 exact-output alternative<br>
**Alternative direct link:** <https://www.berrybase.de/schaltnetzteil-12v-dc-1a-1000ma-12w-mit-hohlstecker-5-5-x-2-1-mm><br>
**Alternative price/stock:** €9.50; manufacturer stock, 5–10 days<br>
**Compatibility:** Voltage/current CONFIRMED; exact receiver barrel dimensions<br>
are **NEEDS MEASUREMENT** and the one-page receiver manual omits polarity. Use
item 9 and the receiver's factory red/black power lead. Its wire purpose and
barrel continuity must agree before first power; never trial-fit an unverified
barrel supply into the receiver.<br>
**Why this exact item:** Protected, certified low-voltage supply with ample margin.<br>
**Required tonight:** YES<br>

### 9. Safe power breakout

**Item:** 5.5×2.1 mm female barrel to screw terminals<br>
**Exact product:** Goobay DC coupling, terminal block, 2-pin<br>
**Manufacturer:** Wentronic / Goobay<br>
**Model / MPN:** 76743<br>
**Quantity:** 1<br>
**Purpose:** Exposes the known centre-positive wall supply on marked screw<br>
terminals for the receiver's modified supplied power lead.<br>
**Primary EU seller:** BerryBase<br>
**DIRECT PRODUCT LINK:** <https://www.berrybase.de/en/dc-kupplung-fuer-hohlstecker-5-5x2-1mm-schraubmontage-terminal-block-2-pin><br>
**Current price:** €0.50 including VAT<br>
**Stock status:** 46+ shown; 1–3 working days<br>
**Alternative EU seller:** Kiwi Electronics, Netherlands (`PC-GP2.1-TB`)<br>
**Alternative direct link:** <https://www.kiwi-electronics.com/nl/terminal-block-naar-2-1mm-dc-barrel-jack-female-747><br>
**Alternative price/stock:** €1.29 excluding NL VAT; 24 shown in stock<br>
**Compatibility:** CONFIRMED positive-inside/negative-outside marking; receiver<br>
cable polarity must still be continuity-checked before power.<br>
**Why this exact item:** Makes the unknown receiver jack dimension irrelevant.<br>
**Required tonight:** YES<br>

### 10. Electrical safety meter

**Item:** Digital multimeter with continuity and DC-voltage modes<br>
**Exact product:** UNI-T UT131B palm-size digital multimeter<br>
**Manufacturer:** UNI-Trend Technology<br>
**Model / MPN:** UT131B<br>
**Quantity:** 1<br>
**Purpose:** Maps the supplied RC832 barrel lead and verifies the assembled 12 V<br>
supply polarity before first power.<br>
**Primary EU seller:** BerryBase, Germany<br>
**DIRECT PRODUCT LINK:** <https://www.berrybase.de/en/uni-t-ut131b-digitales-multimeter-palm-size-mit-batteriepruefung><br>
**Current price:** €14.50 including VAT<br>
**Stock status:** Available at the procurement snapshot; recheck at checkout<br>
**Alternative EU seller:** Reichelt, Germany<br>
**Alternative direct link:** <https://www.reichelt.com/nl/nl/shop/product/multimeter_digitaal_2000_counts_palm_size-224311><br>
**Compatibility:** CONFIRMED functions required: continuity and low-voltage DC.<br>
**Why this exact item:** The Mini manual omits polarity; a meter is cheaper than<br>
risking the receiver and remains useful throughout hardware bring-up.<br>
**Required tonight:** YES, unless an equivalent working meter is already owned<br>

### 11. Cable cutter / stripper

**Item:** Small wire cutter and stripper<br>
**Exact product:** PCWork PCW04A 2-in-1 side cutter / wire stripper<br>
**Manufacturer:** P+C Schwick / PCWork<br>
**Model / MPN:** PCW04A / EAN 4260766895340<br>
**Quantity:** 1<br>
**Purpose:** Removes the undocumented red connector from the **supplied RC832<br>
power accessory lead** and strips its two conductors for the terminal block.<br>
**Primary EU seller:** BerryBase, Germany<br>
**DIRECT PRODUCT LINK:** <https://www.berrybase.de/en/pcwork-pcw04a-2in1-side-cutter-wire-stripper><br>
**Current price:** €5.50 including VAT<br>
**Stock status:** Available; 1–3 working days shown at the snapshot<br>
**Alternative EU seller:** Any local electronics/hardware shop<br>
**Alternative direct link:** Not applicable; use an already-owned cutter/stripper<br>
that is suitable for small stranded wire.<br>
**Compatibility:** Seller specifies a 0.8–2.6 mm cable-diameter range. The<br>
received lead is a mandatory fit check; use an already-owned fine-wire stripper
instead if it falls outside the tool's range, and never nick conductor strands.<br>
**Why this exact item:** It shares the BerryBase shipment and avoids buying an<br>
unverified connector. The modification affects only the replaceable receiver
accessory cable—never the receiver or RadioMaster T8L.<br>
**Required tonight:** YES, unless equivalent tools are already owned<br>

## Conditional tool

If the computer used to flash the card has no SD slot, add the Goobay 38656 USB
microSD reader (€3.30, shown available):
<https://www.berrybase.de/en/microsd-card-reader-with-usb-2.0-port-black/>.

## Air65 power pre-check

The Air65 aircraft is already owned, but a bare Air65 does not itself guarantee
that a charged flight battery and charger are on hand. Before checkout, confirm
you have **at least one serviceable BT2.0 1S LiHV pack and a charger explicitly
supporting 4.35 V LiHV**. If not, add:

- **Battery:** BetaFPV LAVA 1S 260 mAh 80C LiHV, BT2.0, five-pack,
  manufacturer order number `BET-LAVA-1S-260MAH-80C`; €24.90 including German
  VAT, more than 10 available at FPV24:
  <https://www.fpv24.com/en/betafpv/betafpv-lipo-akku-lava-bt20-260mah-1s-80c-5-stueck>.
- **Charger:** VIFLY WhoopStor V3, model/order number
  `VFL-WHOOPSTOR-3-WHITE`; €45.90 including German VAT, more than 10 available
  at FPV24:
  <https://www.fpv24.com/en/vifly/vifly-whoopstor-v3-6-port-1s-lihv-lipo-battery-charger-discharger>.
  It accepts BT2.0 and supports 4.35 V LiHV. Its power adapter is **not included**;
  use a suitable existing USB-C PD supply or other input meeting the documented
  9–20 V USB-C / 6–26 V DC input and power requirements.

These are **Required tonight: NO** when your existing Air65 battery/charging
setup is already complete. Never charge LiHV packs in ordinary 4.20 V LiPo mode
unless deliberately accepting an undercharge, and never select LiHV mode for a
non-LiHV pack.

## Checkout split

- **BerryBase:** items 1, 3, 4, 8, 9, 10 and 11; add the conditional card reader
  only if needed.
- **Kiwi Electronics:** items 2 and 5.
- **Rotorama:** item 6; its included antenna, power lead and AV lead are required.
- **Informatique:** item 7.

Do not substitute a generic AV lead, receiver antenna or USB capture device at
checkout. Those substitutions reopen compatibility checks. Recheck stock, price,
plug type and delivery country on every final cart page.

## Intentionally not ordered

- No second ELRS transmitter: the T8L already supplies radio control.
- No premium/final touchscreen, CM4, decoder EVM or custom PCB.
- No diversity VRX yet; first prove the whole application path.
- No balance-check hardware; it stays simulated in Prototype 0.
- No enclosure or integrated T8L power modification.

When these arrive, continue with [Prototype 0 setup](../docs/PROTOTYPE_0_SETUP.md).

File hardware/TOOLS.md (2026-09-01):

# Bench and bring-up tools

This list distinguishes required capabilities from optional premium brands. Use
existing suitable instruments rather than buying duplicates.

## Required before Test PCB power-up

- current-limited 0–15 V laboratory supply with readable voltage/current;
- CAT-rated DMM with millivolt resolution, resistance and diode modes;
- ST-LINK: `STLINK-V3SET` is the robust purchase lead; the Nucleo onboard ST-LINK
  is sufficient for early firmware work;
- 3.3 V USB-UART adapter with selectable I/O voltage;
- ESD mat/wrist strap, magnification, fine soldering/rework tools;
- 1:1 printer/caliper for footprint fit verification;
- inline fuse leads, shrouded 4 mm leads, nonconductive base and standoffs.

## Required before analog-video integration

- 100 MHz or faster oscilloscope with a true 75 Ω termination/feed-through;
- short, known 75 Ω coax and connector adapters;
- continuity tester for the supplied SteadyView 3.5 mm video cable;
- PAL/NTSC VTX or calibrated composite generator;
- high-speed camera initially, then the documented LED/photodiode latency fixture.

## Strongly recommended

- eight-channel 24 MS/s or faster logic analyzer for SPI/UART/I²C timing;
- isolated/differential measurement capability for switching-power and pack work;
- thermal camera or contact thermocouples;
- programmable or multi-channel isolated source for cumulative-tap injection.

An earthed oscilloscope ground must never be clipped to an unreviewed LiPo node.
Initial balance tests use an isolated current-limited simulator—not a real pack.
See [ground-fault analysis](../docs/BALANCE_GROUND_FAULT_ANALYSIS.md).

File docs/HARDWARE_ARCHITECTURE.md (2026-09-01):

# Hardware architecture

## Current selections

| Function | Prototype 1 | Production-oriented lead | Status |
| --- | --- | --- | --- |
| Compute | Raspberry Pi CM4, 4 GB/32 GB eMMC, no wireless preferred | i.MX 8M Plus industrial SoM | Prototype selected; production shortlist |
| CVBS decode | EVAL-ADV7282AMEBZ candidate; older EVAL-ADV7282MEBZ is Pi-tested baseline | Renesas TW9992 | NRND prototype path; exact EVM stock and SMA-to-CSI fixture open |
| VRX | Skyzone SteadyView X standalone ground-station kit | modular dual-VRX bay; integrated RF later | RF-to-CVBS lead; purchase waits for complete chain gate |
| Display | Waveshare 6.25inch DSI LCD (B), SKU 35000 | 5.5–6.25-inch high-brightness DSI panel | Prototype selected; five-touch required; latency/outdoor/pinch-grip gates open |
| Controller MCU | NUCLEO-G0B1RE then STM32G0B1CBT6 | STM32G0B1CB/CE class | Test-board package selected from current ST pinout |
| Battery ADC | ADS8688A EVM/direct Test PCB | ADS8688A unless measurements reject it | Test-board selected with calibrated matched divider |
| Main battery | bench supplies, then protected two-cell 18650 fixture | serviceable two-cell pack matching verified donor topology | Series/parallel topology **UNKNOWN**; charger not frozen |
| Charger | BQ25792 evaluation | BQ25792-class 1–4S buck-boost/NVDC | Lead; not schematic-approved |
| 5 V rail | TPS55288 evaluation | TPS55288-class buck-boost | Lead; load/EMI validation open |

CM4 is preferred over CM5 for Prototype 1 because CM4's documented H.264 encoder
and established ADV728x capture path reduce two critical risks. CM5 remains a CPU
performance benchmark, not the baseline DVR platform.

The 6.25-inch screen is mounted landscape above the gimbal finger envelopes. Its
159.18 mm cover-lens width is confirmed; T8L placement and pinch-grip clearance are
not. A non-powered ergonomic buck is an enclosure gate.

## Physical partitioning

- ELRS antenna and T8L RF circuitry stay in the original low-noise region.
- 5.8 GHz receive antennas belong above/away from the display, CM4, USB, switching
  nodes, and the 2.4 GHz antenna. One directional and one omnidirectional antenna
  is a useful field configuration; connectors must be keyed/labeled for 50 ohm RF.
- The VRX and CVBS input use a shielded/ground-referenced zone with a dedicated,
  filtered rail. CVBS should not cross switch nodes or MIPI pairs.
- CSI/DSI and USB stay over continuous ground and use manufacturer impedance/
  length guidance. Do not route a split in the return plane below them.
- Battery tap protection and ADC live at the balance connector, away from the RF
  and switcher hot loops. Digital isolation is not assumed necessary at 8S, but
  fault current limiting and ground strategy are mandatory.
- Antennas, heatsinks, shield cans, FFC bends, and connector extraction volumes
  are first-class mechanical keepouts.

## Interfaces

The MCU-to-Linux baseline is USB CDC for Prototype 1 because it provides framing
separation, standard host support, and power-domain visibility. A debug UART is
retained. SPI is reserved as a future performance option, not needed for human-
rate controls/sensors. The VRX interface is initially 75-ohm CVBS plus its native
control mechanism; no undocumented module-bay pins are assumed.

Test PCB Rev A keeps DSI, CSI and RF off-board. Display connects directly to the
CM4IO DSI port, ADV728x evaluation hardware to CSI through a reviewed interposer,
and VRX through 75-ohm coax. The decoder EVM's MIPI SMA ports require a dedicated
controlled-impedance bridge fixture; they are not connected through Test PCB Rev A.
J4/J5 express only the intended CVBS handoff: pin 2 ground and pin 3 video; all
other pins are NC. They provide no module power, RSSI, enable, or undocumented
control signals. The board is still unrouted, so this is net intent only.

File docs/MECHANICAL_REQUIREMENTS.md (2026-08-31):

# Mechanical measurement checklist

Do not begin enclosure CAD from public outer dimensions alone. Capture each value
with a photo, datum definition, instrument, and uncertainty.

## Control ergonomics

- **REQUIREMENT:** the enclosure must support both thumb and pinch grip. The
  index-finger envelope around each stick must remain clear through full gimbal
  travel; the display bezel, switches, and center controls must not intrude.
- **REQUIREMENT:** provide stable lower palm support and enough rear finger
  purchase that a pilot can pinch the sticks without holding the radio by the
  stick fingers.
- **REQUIREMENT:** prioritize a larger, high-mounted display over minimizing
  enclosure height. Display size remains provisional until candidate panels and
  T8L geometry are physically measured.
- **NEEDS MEASUREMENT:** validate gimbal spacing, stick height, index-finger
  clearance, grip angle, center of mass, and strap balance with representative
  thumb and pinch pilots before enclosure CAD is frozen.

## Measurement checklist

- T8L shell exterior, seam, grips, trigger/switch travel, lanyard point, screw/boss
  positions, wall thickness samples, and hand clearance.
- Main PCB outline, thickness, component maxima both sides, holes, USB, battery
  contacts, antennas and keepouts, cable exits, and service access.
- Both gimbal envelopes, fasteners, stick axes/travel, plugged connectors, cable
  sweep, trim/control modules, and switch threaded/soldered mounting.
- Battery cell bays, contact compression, polarity keys, door/latch, and insulation.
- Candidate display active/outer/glass/PCB dimensions, FFC exit/bend, mounting,
  optical stack, bezel, glare treatment, and landscape scan orientation.
- VRX, decoder, compute, Controller-I/O, antennas/connectors, heatsink/air volume,
  buttons, speaker/buzzer, USB-C, balance port and dust caps.
- Assembled center of mass, finger reach, neck-strap load, screen sight line, antenna
  clearance, drop impact paths, and service/disassembly sequence.

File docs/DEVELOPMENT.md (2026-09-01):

# Development

FPVDeck is an appliance UI, not a desktop shell. Hardware backends are selected
behind service interfaces; screens consume stable QObject properties and never
open devices directly.

## Video backends

- `simulated`: generated source used when no explicit input is provided.
- `file`: explicit `--video PATH`, used by deterministic tests and demos.
- `v4l2`: explicit `--video-device /dev/videoN`; optional `--video-standard
  PAL|NTSC` keeps diagnostics aligned with the forced capture norm. Qt's Linux
  camera backend owns capture and publishes frames to the existing FPV compositor.

Use `./scripts/fpvdeck-video-list` and `./scripts/test-video` before debugging
the full UI. A missing device produces an explicit `lost` service state rather
than terminating the application. `./scripts/prototype0` provides friendly
auto-detection and simulator fallback for bench work.

## Keyboard input backend

- Arrows: cycle the current screen's large actionable controls; Enter activates
  the focused control. This is a desktop stand-in for the dedicated navigation
  cluster, not a connection to any gimbal or flight switch.
- Escape: close overlay or return to FPV.
- `M`: application menu.
- `R`: DVR start/stop.
- `B`: battery overlay.
- `L`: video signal loss/recovery.
- `F10`: development-only simulator control panel.

Critical flight controls will never be translated into UI navigation. A future
MCU input event includes its control class, and InputService will accept menu
events only from a physically separate navigation allowlist.

## Definition of done

A change is not complete because it compiles. Relevant automated tests must pass,
the simulator path must remain usable, failure behavior must be considered, and
hardware claims must carry a source or a `NEEDS MEASUREMENT` marker.

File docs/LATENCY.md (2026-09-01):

# Latency budget and validation

Latency is a release gate for FpvDeck. Values in this document are either
targets or estimates until a physical chain has been measured. They are not
product claims.

## Prototype 0 functionality path

```text
Air65 -> RC832 Mini CVBS -> Gembird UVG-002 -> V4L2/QCamera
      -> Qt compositor -> Raspberry Pi Touch Display 2
```

This deliberately uses USB capture to obtain real video quickly. USB transfer,
capture buffering, Qt camera buffering, deinterlacing and display scanout may add
multiple fields/frames. No unmeasured number is assigned to those stages. The
bench procedure records FPS, dropped frames, recovery behavior and a first
glass-to-glass distribution. A poor result does not invalidate Prototype 0; it
confirms why Prototype 1 replaces this path.

The received UVG-002 may use either the `usbtv` or UVC/`uvcvideo` path. Those
paths can buffer and handle loss differently, so the USB ID/driver is part of
every recorded latency result.

| Development stage | Purpose | Video path acceptance |
|---|---|---|
| Prototype 0 | Functionality | real PAL/NTSC video + overlay + touch + DVR; latency measured but not gated |
| Prototype 1 | Latency | direct CVBS decoder path must meet the working p95 gate |
| Prototype 2 | Custom hardware | reproduce validated modular behavior on reviewed PCB hardware |
| Prototype 3 | Integrated product | end-to-end field, thermal, RF and reliability validation |

## Selected Prototype 1 latency path

```text
camera -> FC analog OSD -> VTX/RF -> SteadyView X CVBS
       -> ADV7282A-M evaluation hardware (I2P enabled)
       -> one-lane CSI-2 -> V4L2/DMABUF -> Qt scene graph compositor
       -> DRM/KMS -> Waveshare 6.25inch DSI LCD (B)
```

The decoder and display are evaluation choices, not production freezes.
Raspberry Pi documents ADV728x-M support through the Linux `adv7180` driver and
states that the CSI receiver does not support interlaced input. The `-M` CSI
variant with the line-based I2P block is therefore mandatory for this path.
Analog Devices describes I2P as line based; it avoids a full-frame
motion-adaptive deinterlacer but still needs physical latency verification.

The evaluation board is not a cable-ready Pi accessory. ADI routes its CSI clock
and data pairs to SMA connectors for a MIPI analyzer. The CM4 experiment therefore
needs a reviewed controlled-impedance SMA-to-CSI fixture plus I²C/power wiring;
Test PCB Rev A's generic decoder header is not that high-speed fixture.

The live branch must use V4L2 buffers exported as DMABUFs and imported by a
custom Qt Quick scene-graph video item. CPU copies, a `QVideoSink` image-copy
loop, HDMI capture, USB EasyCAP devices, and GStreamer elements with implicit
queues are excluded from the release path unless measurements overturn this
decision. The recorder receives a tee from capture and may drop recording
frames; it must never back-pressure the display branch.

## Working budget

The table deliberately gives ranges because analog cameras, VRX fusion,
decoder lock, scanout phase, and panel electronics vary. `FpvDeck added` starts
at VRX CVBS output and ends at emitted display light.

| Stage | Working estimate | Status / validation need |
| --- | ---: | --- |
| FPV camera exposure/readout | 4–20 ms | aircraft dependent; measure fixture source |
| FC analog OSD insertion | <1 ms target | generally line-domain; verify reference FC |
| VTX + RF propagation | <1 ms target | propagation is negligible; VTX processing varies |
| Diversity/fusion VRX | 0–5 ms target | **NEEDS MEASUREMENT** in diversity and mix modes |
| ADV728x I2P + CSI launch | below one field target | line-based, exact value **NEEDS MEASUREMENT** |
| CSI/V4L2 buffer availability | 16.7–40 ms phase dependent | NTSC/PAL field/frame boundary behavior must be traced |
| DMABUF import / handoff | <2 ms p95 | benchmark on target kernel and CM4 |
| compositor wait + scanout phase | 0–16.7 ms at 60 Hz | cap queued frames and present newest complete field |
| display electronics + pixel response | 8–25 ms provisional | module processing and landscape scan **UNKNOWN** |

Initial engineering targets:

- VRX-CVBS-to-display-photon: **45 ms p95 target**, **33 ms stretch goal**.
- Full camera-glass-to-display-glass: expected roughly **45–110 ms** depending
  on the aircraft camera and asynchronous phase; establish a measured
  distribution before advertising a number.
- Signal recovery to useful image: **<250 ms p95 target** after a stable CVBS
  signal returns.
- UI touch-to-visible-feedback: **<100 ms p95**, without increasing video queue
  depth or frame misses.

PAL fields arrive every 20 ms; NTSC fields arrive approximately every 16.67 ms.
Both standards must be tested. A result obtained with a static test pattern or
one scanout phase is insufficient.

## Queue and scheduling rules

1. Capture uses the smallest stable V4L2 buffer set; start with three buffers
   and test two. A newly completed field replaces stale unpresented content.
2. No unbounded queue is permitted between decoder and display.
3. The Qt render thread performs only texture import and overlay composition.
   Database, thumbnails, network, and file I/O stay off it.
4. Overlay animation is disabled or simplified if it changes video frame-time
   p99 by more than 1 ms or causes missed presentations.
5. DVR encoding has bounded input queues. On overload, recording reports an
   error/drop while live display continues.
6. Linux services may restart independently. T8L/ELRS control never depends on
   Linux, capture, touch, or display.

## Measurement fixture

Use an electronically timed fixture, with a high-speed camera as a useful
cross-check rather than the only clock.

### Preferred method

1. Drive a fast LED in view of the FPV camera from a microcontroller GPIO.
2. Split or buffer the same GPIO edge into logic-analyzer channel A.
3. Affix a reverse-biased photodiode over a high-contrast patch on the FpvDeck
   display and feed its conditioned output to channel B.
4. Alternate black/white source states using a pseudo-random interval so display
   scanning cannot phase-lock to the stimulus.
5. Capture at least 1,000 transitions for PAL and NTSC, with DVR off/on and UI
   animations off/on.
6. Report minimum, median, p95, p99, maximum, standard deviation, and lost or
   duplicated-field count. Retain raw traces and software/kernel versions.

The source LED transition to display photodiode transition measures complete
glass-to-glass behavior. To isolate FpvDeck-added delay, also inject a generated
CVBS pattern whose electrical transition is recorded on channel A. A dual-head
photodiode placed over source and display can be used when electrical access is
impractical.

### High-speed-camera cross-check

Record the source LED and display in the same frame at at least 1,000 fps. Count
frames across many transitions and account for rolling shutter. This method is
good at revealing scan direction, tearing, deinterlacing artifacts, and spatial
latency variation, but its quantization and shutter timing are weaker than the
electronic fixture.

## Test matrix

| Variable | Required cases |
| --- | --- |
| Standard | PAL, NTSC |
| Signal | strong, weak/noisy, loss and recovery, rolling/nonstandard sync |
| VRX | diversity, mix/fusion, each antenna input independently |
| Recording | off, pre-overlay, composited, both requested |
| UI | clean FPV, controls visible, notification/animation load |
| Thermal | cold start, steady-state warm, thermal-warning boundary |
| Display | portrait-native panel mounted landscape; both image rotations |
| Storage | normal, slow card, nearly full, removed during recording |

Landscape scan direction is important: the selected panel is portrait-native.
Measure the top, center, and bottom of the landscape image because the perceived
delay and tearing location can vary by a significant fraction of a 60 Hz frame.

## Instrumentation to implement

- timestamp decoder/CSI buffer completion with `CLOCK_MONOTONIC_RAW`;
- timestamp DMABUF import, scene-graph render start/end, and page-flip events;
- expose queue depth, dropped/stale fields, frame-time p50/p95/p99, and decoder
  lock transitions in Diagnostics;
- store a benchmark manifest containing hardware revision, kernel, device-tree
  overlay, application commit, display, decoder, VRX mode, and video standard;
- add `tools/video-latency-report` once real trace format is established.

## Decision gates

- Do not select a USB or HDMI capture path because it is convenient; accept one
  only if its p95 measured latency and recovery meet the same gate.
- Do not freeze the Waveshare module for enclosure tooling until scan behavior,
  brightness, touch, thermal load, and p95 latency are measured.
- Do not claim dual DVR streams are practical until encoder load and display
  frame-time remain inside limits during power-loss and slow-storage tests.

Primary-source links and exact module candidates are maintained in
[VIDEO_DECODER_COMPARISON.md](../hardware/research/VIDEO_DECODER_COMPARISON.md),
[DISPLAY_COMPARISON.md](../hardware/research/DISPLAY_COMPARISON.md), and
[SBC_COMPARISON.md](../hardware/research/SBC_COMPARISON.md).

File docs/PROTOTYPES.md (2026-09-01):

# Prototype stages and exit criteria

## Pre-hardware simulator

**BOM:** normal Linux/macOS computer, Qt 6, FFmpeg. **Connections:** none.
**Tests:** C++/C units, SQLite migration, QML runtime, simulated fault scenarios.
**Risk:** desktop multimedia behavior does not prove target zero-copy behavior.
**Exit:** all core apps navigate without hardware, overlays remain independent of
video, persistent flight records work, simulator faults are repeatable, CI green.

## Prototype 0 — bench functionality

**BOM:** Raspberry Pi 5 2 GB, official 5-inch Touch Display 2, dedicated
RC832 Mini 5.8 GHz RF-to-CVBS receiver, Gembird UVG-002 CVBS-to-V4L2 capture,
separate approved Pi/VRX wall supplies and the owned T8L/Air65.

**Connections:** supplied DSI/GPIO display cables; receiver-supplied antenna,
power and AV leads; yellow RCA composite to UVG-002; USB-A to Pi. No T8L
teardown or shared power.

**Tests:** real Air65 video/embedded OSD; Qt RGB overlay; touch; PAL/NTSC capture;
loss/recovery; short DVR; diagnostics; T8L-to-Air65 control continuity.

**Risk:** the USB capture path may have poor latency and buffering. That is
acceptable only for this functionality milestone.

**Exit:** live Air65 image with embedded OSD plus independent FpvDeck overlay is
stable on the touchscreen; apps remain responsive through signal loss; capture
format/FPS/drops and baseline latency are recorded.

See [Buy Tonight](../hardware/PROTOTYPE_0_BUY_TONIGHT.md) and
[setup](PROTOTYPE_0_SETUP.md).

## Prototype 1 — latency bench

**BOM:** CM4/IO carrier, selected 6.25-inch DSI touch display, dedicated 5.8 GHz
SteadyView X RF-to-CVBS ground station, separate ADV7282A-M CVBS-to-CSI evaluation
board, STM32G0 devboard, ADC evaluation hardware, isolated bench
supplies, RF dummy/attenuation/test equipment, logic analyzer and scope.

**Connections:** documented module cables only. The decoder EVM's SMA CSI output
needs a reviewed controlled-impedance CM4IO bridge before purchase/use. Separate
current-limited supplies remain in use until grounds/load behavior are validated.
No unknown T8L connection.

**Tests:** PAL/NTSC lock/recovery; photodiode latency; DMABUF queue; DVR stress;
VRX sensitivity/mode latency; DSI scan; conducted noise; ADC precision/faults;
MCU protocol/reconnect; T8L coexistence.

**Exit:** p95 latency path meets gate or a documented redesign is chosen; 8-hour
video/DVR soak; 1,000 signal reconnects; power budget measured; Prototype 1 wiring
and purchase BOM frozen.

## Prototype 2 — custom modular hardware

**BOM:** custom PCB with STM32G0, selected ADC/protected frontend, controls,
temperature/fan, power state logic, USB CDC/debug, modular VRX/T8L/compute headers.

**Tests:** ERC/footprint audit before order; boundary scan where possible; current-
limited bring-up; precision source calibration; arbitrary balance hot-plug faults;
HIL buttons/watchdog/shutdown; ESD pre-check; self-test coverage.

**Exit:** no unsafe fault current, calibration target met over temperature, 1,000
shutdown/brownout cycles, recovery/update method proven, all test points accessible.

## Prototype 3 — integrated FpvDeck

**BOM:** CM4 carrier, CSI/DSI, power, eMMC module, USB-C/data, decoder or decoder
module, debug/test connectors and shielding options. VRX remains modular.

**Tests:** impedance/layout review; rail sequencing; high-speed eye/compliance where
applicable; full latency/thermal/EMC repeat; RF degradation A/B; storage endurance.

**Exit:** 100-hour soak and thermal margin, no material RF loss, reproducible image,
all carrier interfaces pass manufacturing diagnostics.

Integrate only proven circuits, including the compute carrier when measurement
supports it. Complete DFM/DFT, enclosure/drop/ingress/ergonomic tests, compliance
pre-scan, service procedure, supply-chain audit and pilot build.

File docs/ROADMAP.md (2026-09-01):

# Roadmap

## M0 — desktop foundation (usable simulator)

Qt/QML touch shell, synthetic file video, color overlay, FPV controls/flight lock,
battery/media/storage/receiver/diagnostic faults, SQLite flight history, keyboard
inputs, binary protocol framing, and automated build/runtime tests are implemented.
Remaining: richer aircraft/battery CRUD, real file recording, pointer-driven QML
tests, macOS verification, and source reconnect/resolution tests.

## M0.5 — Prototype 0 real-video bench

The Raspberry Pi 5, official 5-inch capacitive display, RC832 Mini and
UVG-002 reference chain is selected and order-documented. V4L2 enumeration,
raw preview, hardware-mode launch, missing-device fallback, diagnostics and a
pre-overlay Qt recorder branch are implemented. Next: receive parts, continuity-
check the receiver power lead, show real Air65 video/OSD, capture frame/drop and
recovery evidence, and measure the deliberately unoptimized latency baseline.

## M1 — measured low-latency bench video

Acquire the selected decoder/VRX/display/CM4 hardware; build the latency fixture;
bring up V4L2; implement bounded DMABUF display; measure all modes; implement
hardware encode/segmented DVR; and freeze the Prototype 1 wiring/BOM.

## M2 — Test PCB / Controller-I/O Rev A

The placed/unrouted Test PCB project, exact-MPN BOM, ADC error model, bring-up
command core, host self-test, and staged procedure exist. Next: resolve protected
pack reference, complete native schematic/ERC and pin/footprint audit, route/DRC,
then release and perform HIL bring-up. The later controller board adds complete
controls, thermals, watchdog, and power sequencing after these circuits pass.

## M3 — compute carrier

CM4 carrier with proven CSI/DSI routing, storage, USB-C/data/debug, power partition,
and mechanical stack. Measure EMC impact on both RF links. Evaluate i.MX 8M Plus
production SoMs using the same decoder/display fixtures.

## M4 — integrated field prototype

Custom enclosure, serviceable pack, sunlight/thermal/rain ingress evaluation,
field flight logging, recovery image, manufacturing self-test, and multi-unit soak.

## M5 — production candidate

Supply-chain/lifecycle audit, compliance pre-scan, DFM/DFT, controlled release
files, reproducible OS/firmware builds, security/update policy, and pilot build.

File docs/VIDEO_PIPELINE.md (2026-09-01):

# Video pipeline

FpvDeck video pipeline

## Prototype 0 functional path

```text
Air65 analog VTX -> RC832 Mini RF-to-CVBS -> yellow RCA
  -> Gembird UVG-002 -> Linux V4L2/QCamera (usbtv or uvcvideo)
  -> Qt Quick VideoOutput + independent RGB QML overlay
  -> Raspberry Pi Touch Display 2
```

This is implemented as a selectable `v4l2` VideoService backend. Qt owns the
camera/capture session; the UI continues to consume the same service state as
file and simulated sources. A `QMediaRecorder` tee can write the pre-overlay
camera stream without routing recording frames back through the live UI. This
path is allowed to be slow and buffered: it is evidence for functionality, not
the release pipeline.

Gembird declares two possible chipsets under one MPN. UTV007 uses `usbtv`;
UTVF007 commonly exposes a UVC stream through `uvcvideo` but may squelch noisy
input. Device ID, driver, formats and loss behavior are receipt/bench gates.

`scripts/fpvdeck-video-list` enumerates exact nodes/formats, `scripts/test-video`
validates V4L2 without the application, and `scripts/prototype0` launches real
capture with an explicit fallback to synthetic video when hardware is absent.

## Prototype 1 latency path

```text
Aircraft camera -> Betaflight analog OSD -> 5.8 GHz analog VTX
  -> 5.8 GHz antenna
  -> dedicated SteadyView X analog VRX (RF receiver; not supplied by T8L)
  -> 1 Vpp / 75 Ω CVBS
  -> correctly terminated/protected analog input
  -> ADV7282A-M decoder evaluation path with low-delay line-based I2P
  -> one-lane CSI-2 YUV422
  -> CM4 Unicam/V4L2 capture
  -> DMABUF-backed live queue (depth 1; newest frame wins)
  -> Qt Quick scene graph / DRM-KMS compositor
  -> DSI scanout
```

These are two distinct hardware stages: SteadyView X demodulates 5.8 GHz RF into
composite video, while ADV7282A-M digitizes composite video. The decoder has no RF
receiver. The donor T8L's separate 2.4 GHz ELRS transmitter carries aircraft
control only.

The current EVM path is not purchase-cleared. `EVAL-ADV7282AMEBZ` exposes MIPI
clock/data on SMA connectors, and a reviewed controlled-impedance SMA-to-CM4IO
bridge is still required. This interface gap is tracked rather than represented
as an ordinary cable.

Raspberry Pi's camera documentation explicitly supports ADV728x-M through the
`adv7180` driver and explicitly does not support interlaced input. Therefore I2P
is not optional on this prototype. The Analog Devices I2P uses line interpolation
rather than field/frame storage; its artifacts are accepted in exchange for low
delay. A frame-based software deinterlacer is forbidden in the live path.

The Prototype 0 Qt camera/V4L2 path intentionally transits USB capture. The
Prototype 1 release candidate must instead use a dedicated low-queue V4L2/DMABUF
backend. It must not transit a USB capture
device, encode/decode round trip, GStreamer queue with unspecified depth, or a
desktop window manager.

## Queue policy

- Capture buffers: minimum driver-supported count proven stable; target 2.
- Application live queue: exactly one pending frame; overwrite stale frames.
- Compositor: direct fullscreen KMS/DRM session with no desktop compositor.
- Recorder: independent bounded queue. Recorder overload drops/flags recording
  frames and never back-pressures live video.
- Faults: hold last valid frame briefly, then show explicit `NO VIDEO`; never let
  a decoder's free-run blue/black output masquerade as a valid RF lock.

## DVR

V1 records pre-overlay YUV through the CM4 H.264 hardware encoder. Five-minute
segments and a journaled metadata transaction limit power-loss damage. Container
choice will be tested between fragmented MP4 and Matroska; normal MP4 requiring a
final `moov` write is not acceptable without fragmentation/recovery.

Composited recording is a later option. It requires an additional offscreen render
or writeback path and must be disabled automatically if it threatens the live
budget. Pre-overlay recording remains the canonical evidence stream.

## PAL/NTSC policy

Autodetect is accepted for general use; a user-forced standard is available for
problem sources. The service publishes detected/forced standard, lock state,
field rate, frame sequence, decoder error counters, and last-good-frame time.
PAL, NTSC-M, weak sync, nonstandard line length, unplug/replug, and standard
change are required bench cases.

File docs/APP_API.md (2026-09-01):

# Application and widget API

Applications receive service interfaces from AppManager; they do not instantiate
drivers. API objects are versioned at the C++ boundary when external plugins are
introduced. QML modules bundled with the system currently compile together.

## BatteryService snapshot

`connected`, `chemistry`, `cellCount`, `cellVoltages`, `packVoltage`, `delta`,
`weakestCell`, `weakestVoltage`, `strongestCell`, `strongestVoltage`, `health`,
`warning`, and event time. A future `batteryId` is nullable and may originate from manual choice,
QR, or NFC. FPV's BatteryWidget reads the same service as the full Battery app.

## VideoService snapshot

`standard`, `lockState`, `sourceFormat`, `frameSequence`, `lastFrameTime`, decoder
health and fault counters. RadioService separately owns the dedicated 5.8 GHz VRX
channel/RSSI/scan state. Neither service represents the T8L 2.4 GHz ELRS control
transmitter. Pixel buffers are never exposed to general QML plugins; only the
trusted video item owns them.

## RadioService snapshot

Represents only the dedicated FpvDeck 5.8 GHz analog VRX and publishes `channel`,
`rssi`, `favorite`, and `scanning`. It does not represent the T8L/ELRS control
link or the CVBS decoder. The simulator exposes channel/favorite/scan behavior
even though the selected SteadyView X host-control protocol remains **UNKNOWN**.

## InteractionService

Owns `controlsVisible`, `flightLocked`, `autoHideMs`, and last touch position.
Navigation is requested through the service; a locked request emits rejection
instead of silently navigating. UI pages do not independently implement flight
lock or auto-hide timers.

## StorageService and MediaService

Storage publishes removable-card presence, health, free space, and immutable
media metadata. Media owns open/play/pause/seek/skip state and aspect metadata.
Playback uses preserve-aspect rendering. A future real Storage backend owns mount
and safe-eject policy; Media never shells out or mounts a device.

## SystemService

Publishes internal deck battery/charging, independent T8L-control/ELRS-TX status,
MCU/ADC health, dedicated 5.8 GHz VRX status, CVBS-decoder status, temperatures,
brightness, uptime, and developer touch-debug state. External balance-pack values
never enter this service; that separation prevents UI or backend code from
confusing the measurement-only port with the internal energy source.

## Overlay provider contract

An app may register declarative widget metadata: stable ID, QML component URL,
minimum/maximum size, default anchor, required service capabilities, update-rate
limit, and safety priority. App widgets cannot create unbounded timers, access
devices, or cover reserved Betaflight OSD safe zones without explicit user action.

## Failure contract

Service values include `quality` (`valid`, `stale`, `unavailable`, `fault`) and a
monotonic timestamp in the real backend contract. Apps must render
stale/unavailable explicitly rather than
retaining a plausible old value. Calls are nonblocking; long operations return a
request ID and completion/error signal.

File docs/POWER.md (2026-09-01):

# Power architecture

FpvDeck power architecture

## Provisional topology

```text
USB-C receptacle + ESD/CC/PD
       -> charger/power path selected after donor cell topology is measured
       -> protected, serviceable two-cell 18650 pack
              ├─ fused/filtered T8L input (only after original topology verified)
              ├─ TPS55288-class 5.1 V high-current buck-boost -> CM4/display/USB
              ├─ quiet filtered VRX/video rails
              └─ always-on low-power MCU rail -> power button/load switches
```

The provisional diagram does not mean these rails exist in the T8L. The donor's
two-18650 topology and safe added-load budget remain unknown. On the modular bench,
CM4IO, the dedicated 5.8 GHz VRX, decoder EVM, and Test PCB use their separately
documented/current-limited supplies. External balance taps are measurement inputs
only and never power any FpvDeck rail.

BQ25792 is an active 1–4 cell, 5 A buck-boost charger with NVDC power path,
integrated FETs/ADC, I²C, 3.6–24 V input, and USB-PD-range OTG. It does not itself
remove the need for correct USB-C policy/protection, pack protection, thermistors,
fusing, cell matching, regulatory work, and safe mechanical cell retention. It
is only a valid lead after confirming whether the T8L's two cells are series or
parallel and whether its existing charging circuit stays in use.

TPS55288 is an active four-switch 2.7–36 V buck-boost with programmable current
limit and spread spectrum. Its 16 A figure is switch/inductor current, not a claim
that any board can deliver 16 A at 5 V. Inductor, MOSFETs, copper, thermal design,
stability, peak battery current, and EMI must be calculated and measured.

## First-pass power budget

| Load | Typical estimate | Peak estimate | Confidence |
| --- | ---: | ---: | --- |
| CM4 + eMMC | 3.5 W | 7 W | platform-dependent estimate |
| 5.5–6.25-inch display/backlight | 3.5 W | 7 W | envelope estimate; **NEEDS MEASUREMENT** |
| SteadyView X | 2.9 W | 3.5 W | 12 V × 240 mA published typical |
| decoder + carrier | 0.4 W | 0.8 W | estimate |
| T8L/ELRS | 0.7 W | 1.5 W | **NEEDS MEASUREMENT** |
| MCU/ADC/storage/misc. | 0.8 W | 2 W | estimate |
| **system before conversion loss** | **10.8 W** | **19.8 W** | not measured |

The required two-cell pack using 3 Ah, 3.6 V cells stores about 21.6 Wh nominal,
regardless of whether the cells are 2S1P or 1S2P. At 11–16 W input, before reserve,
age, cold-weather, and conversion losses, this suggests roughly 1.0–1.7 hours.
The initial runtime gate is therefore ≥1.25 h at typical FPV+DVR load, with a
1.5 h stretch goal. Lower screen brightness, a more efficient VRX rail, and
measured compute tuning matter. Adding cells is not assumed because the product
requirement specifies the T8L's two internal 18650 cells.

The exact pack topology, protection, charger, and power-path IC are **UNKNOWN**
until the donor is measured non-destructively. Bench Prototype 1 uses isolated,
current-limited supplies; it does not connect to or charge the T8L cells.

## Shutdown state machine

Short power press wakes the MCU and enables compute. A normal off request makes
the MCU send `ShutdownRequest`; Linux stops recording, commits SQLite, syncs and
unmounts writable data, then returns `ShutdownReady`. The MCU waits for rail-good/
heartbeat loss and removes the compute load while keeping charger/wake logic alive.

A ≥8 s hold is emergency forced-off. The MCU records the cause and removes power
even without Linux acknowledgement. The next boot runs filesystem/database checks
and presents a recovery notice. Brownout prediction requests an expedited shutdown;
DVR segmentation limits the unrecoverable interval.

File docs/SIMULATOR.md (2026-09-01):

# Simulator

The same FPVDeck executable runs simulated and real backends. Desktop development
currently instantiates simulated battery, dedicated 5.8 GHz Radio/VRX, separate
video/decoder, DVR, input, removable
storage, media playback, deck health, and system state.

`./scripts/demo` opens the deterministic showcase Home state. The Home, FPV,
Balance, Media, Flights, and Diagnostics routes can be selected at startup with
`--demo-state`; supported states are `home`, `fpv`, `fpv-controls`, `fpv-lock`,
`battery`, `media`, `media-playback`, `receiver`, `flights`, and `diagnostics`.
This seeds temporary/repeatable state when requested.
The normal `./scripts/dev` path retains the developer database and opens FPV.

The `F10` panel injects video lock, weak signal, vertical roll, signal loss,
black frames, PAL/NTSC selection, channel changes, balance lead events,
imbalance, under/overvoltage, deck battery drain/charging, storage insertion,
removal/corruption/full, T8L/ELRS/MCU/ADC/VRX/decoder disconnects, and temperature warnings. The
fault strip is deliberately visible only in development mode.

Mouse input is treated as a single touch point. Enable **Show touch points** in
Settings to display a transient pointer marker. Multi-touch and pinch are not
used for critical actions; the product requirement for pinch grip refers to
physical gimbal ergonomics, not a gesture dependency.

Synthetic input video is generated at 720×576 and 50 frames/s. It intentionally
contains white pseudo-OSD text inside the encoded pixels. Colored translucent UI
remains a separate QML layer. This verifies the composition model but does not
claim analog timing fidelity.

Representative repository screenshots are generated from the executable, rather
than drawn mockups:

```sh
./scripts/screenshot-demo
```

The command uses Xvfb so the Qt Multimedia video texture is included, writes eight
1280×720 captures to `docs/assets/ui/`, and uses an in-memory SQLite database.

Future simulation work still required: pointer-driven QML test automation,
decoder resolution-change assertions, real test-file recorder interruption and
recovery, and an analog-noise shader calibrated against captured receiver output.

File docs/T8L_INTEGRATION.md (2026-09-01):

# RadioMaster T8L integration

## Confirmed public facts

RadioMaster's current product page and 2026 manual specify a 165×120×70 mm,
204 g transmitter with X5 Hall gimbals, two 18650 cells, a 6.0–8.4 V operating
range, USB-C charge/update/simulator functions, SX1281-based 2.4 GHz ELRS, and up
to 100 mW RF power. The firmware is a special T8L edition configured by a USB
web UI rather than EdgeTX.

A published teardown identifies an ESP8285 and SX1281 and shows a single main
PCB, plugged gimbal/trim assemblies, some soldered switches, ceramic 2.4 GHz ELRS
antenna, separate PCB Wi-Fi antenna, and an unlabeled connector. This teardown is
useful orientation but not authority for a pinout.

Sources:

- <https://radiomasterrc.com/products/t8l-radio-controller>
- <https://radiomasterrc.com/pages/user-manuals>
- <https://oscarliang.com/radiomaster-t8l/>

## V1 reuse decision

Reuse the complete T8L mainboard, two Hall gimbals, useful controls, associated
2.4 GHz ELRS antenna/RF path, and its two-cell compartment. Existing charge/USB
behavior is reused only where measurement confirms it remains safe with the added
load. Mount the FPV computer as an electrically separate subsystem. Shared power
is allowed only after load, ground, charging, brownout, and conducted-noise tests.

The T8L contains **no FpvDeck analog-video subsystem**. It does not provide the
5.8 GHz VRX, CVBS decoder, compute, touchscreen, removable media, or external
balance checker. ELRS control and 5.8 GHz analog video are independent RF paths.

The Linux/MCU side does not sit in the stick-to-ELRS path. Read-only T8L status may
come first from USB HID/VCP if tests prove RF remains fully active and timing is
unaffected. Telemetry/CRSF tapping is deferred and optional.

## Unknowns

- PCB/gimbal/mount/connector dimensions: **NEEDS MEASUREMENT**.
- Two-cell electrical topology and protection: **NEEDS MEASUREMENT**.
- Unlabeled connector pinout/function: **UNKNOWN; DO NOT CONNECT**.
- Internal rail voltages and current margin: **NEEDS MEASUREMENT**.
- Whether USB simulator/VCP mode leaves RF active: **NEEDS MEASUREMENT**.
- Accessible CRSF UART/telemetry and voltage levels: **UNKNOWN**.
- T8L schematic/board files and RF layout stackup: **UNKNOWN**.

## Antenna/EMC rules

Keep the 2.4 GHz antenna in its original geometry and free-space boundary. Do not
place a display FPC, metal heatsink, battery, shield, or 5.8 GHz antenna inside
its near field without chamber/field comparison. Disable CM4 Wi-Fi by default;
if later enabled, use an external antenna isolated from ELRS and prove link margin.

Keep switcher hot loops, CSI/DSI, USB, and high-edge-rate clocks away from both
2.4 GHz ELRS transmit/control and 5.8 GHz analog receive paths. Filter VRX/decoder
rails, use shield footprints
where measurements justify them, and compare receiver noise floor with each
digital subsystem enabled/disabled.

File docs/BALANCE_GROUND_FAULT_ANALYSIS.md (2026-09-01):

# Balance-input ground fault analysis

## Status and boundary

**OPEN SAFETY GATE — NO REAL LIPO.** This document defines tests needed to decide
whether Test PCB Rev A's pack-negative reference concept is acceptable. It is not
an approval, certification, or substitute for a reviewed native schematic.

External balance taps are measurement inputs only. The external pack must never
power FpvDeck. F2 (`1206L010/60WR`) is a DNP experiment between `BNEG_RAW` and
local ground; TP33 and TP34 expose both sides. A wire or zero-ohm bridge is not an
allowed substitute.

R7 (1.00 kΩ) connects `BNEG_RAW` to the ADC's `BNEG_SENSE` input. It makes the
sense path explicit and limits input current, but it is not enough to approve a
ground fault. ADS8688A input bias through R7 creates a calibration term, so test
limits apply to both TP33/TP34 and the ADC code.

## Intended normal state

With no other external ground, the six divider paths draw a modeled 2.152796 mA
from a 6S pack at 4.2 V/cell. The F2 candidate creates a modeled 3.229 mV offset
at its 1.5 Ω typical initial resistance and 21.528 mV at the published 10 Ω
post-trip/reflow maximum. Physical ADC channel 0 measures B− using a
bipolar range. Production firmware **must** correct cumulative taps by subtracting
measured B−, but that correction is not implemented or hardware-validated yet;
raw and corrected values must both pass sanity checks before release.

## Fault matrix

| State | Hazard to test | Required response | Release evidence |
| --- | --- | --- | --- |
| Board unpowered, pack simulator present | current through unpowered ADC clamps | remain inside every absolute maximum; no phantom powering | measured pin/rail currents and thermal record |
| USB/SBC attached | alternate B− return through host ground | no uncontrolled current or bypass of F2 | isolated current measurement in every cable state |
| Earth-referenced scope attached | probe ground shorts intended protection | fixture must prevent unsafe attachment or test must be isolated | signed bench topology and differential-probe procedure |
| Grounded lab supply attached | supply negative creates a second return | no loop current above calculated normal current | current at F2 and every external cable |
| F2 open | measurements may look plausible with floating reference | pack immediately invalid/stale | UI and raw-code test log |
| F2 high resistance | growing common-mode error | warning before B− input/range limit | swept resistance versus correction/error |
| F2 tripped | hot component and stale data | fail safe; no automatic healthy state while hot | trip/cool-down waveform and temperature |
| Partial J1 insertion | B− or taps connect in arbitrary order | no damaging current; never report healthy pack | every insertion-order capture |
| Intermediate tap open | adjacent cells can alias | explicit open/invalid result | all six missing-tap cases |
| Adjacent taps shorted | cell reads zero while pack remains energized | invalid result; components within ratings | current and temperature record |
| Tap-to-local-ground short | pack energy may bypass divider | fixture-limited test only; protection contains fault | reviewed worst-case calculation before test |
| Reversed fixture | negative ADC input/connector stress | no real-battery test; simulator-limited only | limits and measured clamp current |
| MCU/firmware stalled | stale healthy voltage | watchdog expires and Linux marks service offline | HIL watchdog log |

## Required pre-test calculations

Before F2 is populated, record for each matrix row:

1. complete current path, including cable shields and instrument earth;
2. source voltage, source current limit and available energy;
3. maximum pin voltage/current for J1, R1–R6, RN1–RN6, U1 and F2;
4. expected TP33−TP34 polarity and magnitude;
5. abort current, temperature and time;
6. whether the test can leave F2 at its 10 Ω post-trip/reflow maximum;
7. instrument isolation category and probe placement.

Unknown values block that test; they are not filled with assumptions.

## Initial simulator-only procedure

Use six isolated series sources or an approved resistor ladder, limited to 5 mA
and physically unable to connect to a battery. Start with F2 DNP and verify no
alternate TP33–TP34 path. Populate F2 only for a reviewed test, configure physical
ADC channel 0 bipolar, then ramp cumulative taps while monitoring:

- TP33−TP34 with a differential measurement;
- total simulator current and current through F2;
- ADC channel 0 raw code and corrected tap values;
- F2, divider, ADC and connector temperature;
- all attached-cable states one at a time.

Stop immediately for unexpected current, positive B− sense polarity, unstable
correction, a component more than 10 °C above ambient during the low-energy test,
or any credible measurement after F2 is opened.

## Gate closure criteria

The protected reference gate closes only when the native schematic has passed
ERC and independent review, all exact footprints have been checked, worst-case
calculations cover the full 6S voltage and every grounded interface, simulator
tests pass, and a reviewer explicitly approves a real-pack procedure. Closing
this gate does not release the rest of the PCB; routing, DRC and the remaining
release checklist still apply.

## Primary sources

- [TI ADS8688A datasheet](https://www.ti.com/lit/ds/symlink/ads8688a.pdf)
- [Littelfuse 1206L PPTC datasheet](https://www.littelfuse.com/assetdocs/littelfuse-ptc-1206l-datasheet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)

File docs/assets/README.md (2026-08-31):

# Repository assets

- `branding/` contains editable identity and social-preview SVG sources.
- `diagrams/` contains rendered architecture SVGs beside editable Mermaid source.
- `renders/` contains explicitly labeled product concepts and their accuracy gate.
- `ui/` contains reproducible captures generated by the Qt/QML simulator.
- `screenshots/` is reserved for measured bench, HIL, and physical-prototype evidence.

Do not place generated build output, unlicensed footage, or vendor artwork here.

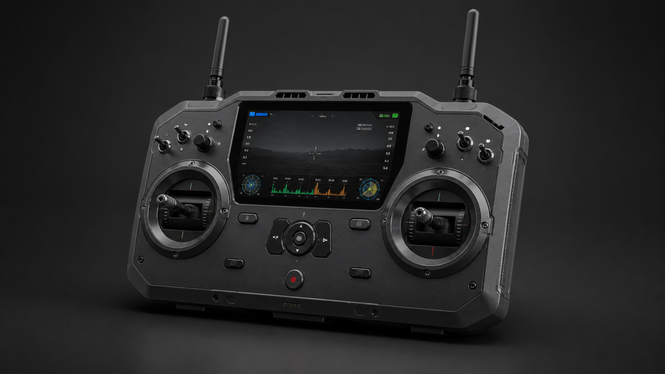
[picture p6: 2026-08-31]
docs/assets/renders/fpvdeck-concept-render-v1.png

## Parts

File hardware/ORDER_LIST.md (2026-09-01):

# First bench prototype order list

This legacy Prototype 1 list is retained for design context. **Do not use it for
tonight's order.** The current functionality bench uses the short
[Prototype 0 buy-tonight list](PROTOTYPE_0_BUY_TONIGHT.md). The compatibility-gated
[EU order list](ORDER_LIST_EU.md) and [buy-now list](BUY_NOW.md) resume only after
Prototype 0 produces real measurements. Recheck stock, VAT, and exact MPN at checkout.

## Already owned

- **1× RadioMaster T8L.** It supplies the independent 2.4 GHz ELRS control radio,
  its RF path, two Hall gimbals, useful controls/controller electronics, and the
  initial two-18650 arrangement subject to verification. It supplies **no analog
  VRX, decoder, display, media reader, or balance checker**.

## Compute — order now

- **1× Raspberry Pi CM4, `CM4104032` (4 GB / 32 GB eMMC)** — about US$85. This is
  the documented Prototype 1 CSI/DSI/H.264 platform. Any authentic CM4 eMMC model
  with at least 2 GB RAM is compatible if this exact RAM variant is unavailable.
- **1× official Raspberry Pi Compute Module 4 IO Board** — about US$45. It exposes
  both 22-pin CSI and DSI ports and avoids a custom high-speed carrier initially.
- **1× regulated CM4IO supply** — use the official barrel-jack requirements or a
  current-limited lab supply; budget US$15–25.
- **1× USB A-to-micro-B data cable** for eMMC flashing and **1× Ethernet cable**.

## Display — order now

- **1× Waveshare `6.25inch DSI LCD (B)`, SKU 35000** — US$59.99 list. It includes
  12 cm DSI cable, two 15-pin FPC cables, a PH2.0 four-wire 5 V lead and screws.
  This is the selected 720×1560, 500 cd/m², optical-bonded five-touch display.
  Do not buy discontinued SKU 28918.

## Video

- **1× Skyzone SteadyView X ground-station kit — WAIT FOR CHAIN GATE.** It provides
  the dedicated 5.8 GHz RF-to-CVBS stage: standalone 1 Vpp/75 Ω CVBS, two SMA
  antenna ports and 6.5–26 V input. The EU kits identified in 2026 include one
  RHCP patch and one omni antenna, so do not separately buy antennas initially.
- **1× Analog Devices `EVAL-ADV7282AMEBZ` — WAIT FOR STOCK + BRIDGE.** Budget
  US$250–350. It evaluates the ADV7282A-M, which ADI says
  is pin/software-compatible with ADV7282-M; Raspberry Pi tested its driver with
  the older `EVAL-ADV7282MEBZ`. Both silicon families are NRND and are prototype
  tools, not production selections. The EVM routes CSI D0± and CLK± to SMA ports,
  not a camera FFC. Obtain UG-1175 and the schematic before buying/building the
  separate controlled-impedance SMA-to-CM4IO fixture. If an exact older
  `EVAL-ADV7282MEBZ` is genuinely available, it is the closest Pi-tested baseline.
- **2× 75 Ω BNC/coax patch leads**, **1× BNC-to-RCA adapter**, and **1× 75 Ω
  feed-through terminator** — budget US$35. Match the actual EVM/VRX connectors.

Do not substitute a USB EasyCAP or HDMI capture device as the latency baseline.

## Controller / balance development — order now

- **1× ST `NUCLEO-G0B1RE`** — about US$25. This lets the protocol, ADC SPI and
  power-state firmware progress while the custom board is under review.
- **1× TI `ADS8688EVM-PDK`** if available and below the US$250 allowance. This is
  useful for validating register configuration and the input-impedance model, but
  it is optional if Test PCB Rev A is released promptly.
- **1× ST `STLINK-V3MINIE`** plus compatible SWD cable — about US$15–25.
- **1× JST `B7B-XH-A(LF)(SN)`** and several mating XH housings/crimp contacts for
  physical fit testing. Never make a male-to-male lead that could backfeed a pack.
- Precision bench source or battery simulator capable of 0–25.5 V at a 5 mA
  current limit. An ordinary bench supply plus resistor ladder is adequate for
  initial cumulative-tap tests; it does not replace independent-cell tests.

The decoder EVM and VRX are not unconditional purchases. The display, CM4, MCU,
and media reader remain useful without them, while the analog-video pair waits
for a reviewed EVM-SMA-to-CM4IO CSI bridge.

## Test PCB

- **Bare PCB: WAIT.** The current KiCad project is real and exportable but remains
  unrouted and release-gated. Do not upload its generated Gerbers to a fab.
- Components may be pre-ordered in small quantities if desired. Recommended spare
  quantities: 2× ADS8688A, 3× STM32G0B1, 10× Vishay matched arrays, 20× each
  precision resistor/filter capacitor, 2× every connector.
- Use the exact [Test PCB BOM](bom/TEST_PCB_REV_A.md), not a screenshot or this
  prose list, for purchasing.

## Power — bench only now

- 0–15 V laboratory supply with adjustable current limit and readable current.
- Inline 0.5 A fuse holder, 22 AWG silicone wire, 4 mm safety leads, and shrouded
  adapters. Budget US$30 excluding the supply.
- Do **not** buy final 18650 cells, charger PCB or T8L power adapters yet. The T8L
  input and final protected pack topology still require measurement and safety
  review.

## Debugging

- Required: multimeter with millivolt resolution, current-limited supply, SWD
  debugger and USB-UART adapter with selectable 3.3 V I/O.
- Strongly recommended: 8-channel logic analyzer at 24 MS/s or better, 100 MHz
  oscilloscope, differential probe for switching-power work, and thermometer or
  thermal camera.
- Latency fixture later: two fast photodiodes, transimpedance/front-end parts,
  high-brightness LED and microcontroller trigger board.

## Mechanical / temporary assembly

- M3 nylon standoffs, non-conductive baseplate, hook-and-loop straps, printed/foam
  display buck, short 75 Ω coax, and FFC strain relief — budget US$25–40.
- Do not attach the large display to the T8L until the pinch-grip finger envelope
  has been checked with a non-powered mock-up.

## Optional

- 128 GB SanDisk High Endurance microSD for removable-media/DVR tests — US$20.
- Saleae Logic 8 or equivalent known-good analyzer.
- TBS Fusion/rapidFIRE as an RF/latency A/B benchmark if already available; neither
  is required to start.

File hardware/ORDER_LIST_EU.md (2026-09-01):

# EU Prototype 1 order list

> **Later-stage list.** For the fastest Air65-to-touchscreen functionality build,
> use the selected [Prototype 0 buy-tonight list](PROTOTYPE_0_BUY_TONIGHT.md).
> Do not combine both lists or purchase a second compute/display stack now.

**Research snapshot:** 2026-09-01. **Architecture:** T8L supplies control/2.4 GHz
ELRS only; FpvDeck adds a separate 5.8 GHz analog VRX and a separate CVBS decoder.
The machine-readable companion is
[`bom/PROTOTYPE_SYSTEM_EU.csv`](bom/PROTOTYPE_SYSTEM_EU.csv).

Status meanings: `BUY NOW` is independently usable and interface-credible;
`BUY SOON` requires a named check that does not invalidate the rest of the kit;
`WAIT` has an unresolved compatibility, safety, lifecycle, or PCB release gate.

## Already owned

| Item | Source | Boundary |
| --- | --- | --- |
| RadioMaster T8L donor | user-owned | 2.4 GHz ELRS TX/RF, gimbals, useful controls, controller electronics, initial two-18650 arrangement pending measurement |

No additional ELRS transmitter is required. None of the video, display, compute,
removable-media, or balance-measurement hardware comes from the T8L.

## Compatibility chain

```text
Aircraft 5.8 GHz analog VTX
  → SteadyView X 5.8 GHz VRX
  → documented 1.0 Vp-p / 75 Ω CVBS output
  → ADV7282A-M decoder candidate
  → one-lane MIPI CSI-2 on EVM SMA connectors
  → UNDESIGNED controlled-impedance SMA-to-CM4IO bridge
  → Raspberry Pi CM4
  → DSI
  → Waveshare 6.25-inch capacitive touchscreen
```

The first two handoffs are documented. The CSI bridge is not. Therefore the VRX
and decoder are `WAIT`, not `BUY NOW`, despite current receiver stock.

## Compute, display, media and development

The purchase-cleared list, source alternatives, VAT notes and live-price snapshot
are maintained in [BUY_NOW.md](BUY_NOW.md). These items total about €353 before
shipping and contingency.

## Dedicated 5.8 GHz analog VRX — WAIT: chain gate

**Lead:** Skyzone SteadyView X 5.8G ground-station kit, quantity 1.

- **CONFIRMED:** standard 5.8 GHz analog reception; two SMA-K 50 Ω antenna ports;
  1.0 Vp-p typical/75 Ω CVBS; 6.5–26 V input; supplied XT60-to-barrel power lead,
  3.5 mm video cable, RHCP patch, and omni antenna.
- **EU primary:** [La Caméra Embarquée, France, €219 before tax shown, in stock](https://www.lacameraembarquee.fr/en/fpv-receivers/19734-skyzone-steadyview-x-58ghz-receiver-with-ips-screen.html).
- **EU alternative:** [Baltic Drones, Lithuania, €250.23 taxes included, in stock](https://balticdrones.eu/products/vrx-skyzone-steadyview-x-4-9-5-8g-ips).
- **Manufacturer reference:** [Skyzone, US$183 plus checkout shipping/tax](https://www.skyzonefpv.com/en-de/products/skyzone-stvx-steadyview-x-receiver).
- **UNKNOWN:** conductor map of the supplied 3.5 mm cable; Linux/SBC channel-control
  protocol; externally accessible calibrated RSSI; fusion latency.
- **Action:** continuity-map the supplied cable and verify terminated CVBS on an
  oscilloscope/display before any custom harness. Use its wheel for channel control
  until a published protocol exists.

The two supplied antennas are sufficient for first testing. Do not buy separate
antennas now; verify connector gender and polarization on receipt before spares.
The receiver's ELRS *backpack* is for VTX/VRX channel synchronization and is not a
replacement or duplicate of the T8L flight-control transmitter.

## CVBS decoder — WAIT: stock + bridge gate

**Candidate:** Analog Devices `EVAL-ADV7282AMEBZ`, quantity 1, allowance €250.

- [ADI evaluation-board page](https://www.analog.com/en/resources/evaluation-hardware-and-software/evaluation-boards-kits/eval-adv7282a-m.html)
  and [UG-1175](https://www.analog.com/media/en/technical-documentation/user-guides/eval-adv7282amebz-ug-1175.pdf)
  confirm the decoder role and EVM interfaces.
- [Mouser Germany](https://www.mouser.de/en/ProductDetail/Analog-Devices/EVAL-ADV7282AMEBZ?qs=1mbolxNpo8dXn4uu0WGlNw%3D%3D)
  reported restricted availability when directly checked; an earlier search cache
  showed €203.05/limited stock, so only the product page at checkout is authoritative.
- The EVM exposes CSI clock/data on SMA, not a Raspberry Pi camera FFC. A reviewed
  100 Ω differential bridge with continuous return, exact lane mapping, and CM4IO
  connector mapping is required. This is not an ordinary cable purchase.
- ADV7282A-M is NRND. It may be a latency prototype tool but is not the frozen
  production decoder. The older `EVAL-ADV7282MEBZ` is the closest Raspberry Pi
  driver-validation baseline if a genuine board can be borrowed.

## Test PCB and balance frontend — WAIT: board release

The exact orderable component set is
[`TEST_PCB_REV_A.csv`](bom/TEST_PCB_REV_A.csv). Its major parts include
STM32G0B1CBT6, ADS8688AIDBT, exact Vishay matched resistor arrays, JST
B7B-XH-A(LF)(SN), protected bench input, regulation, probes and connectors.

Do not order bare boards or the full BOM. The current board is unrouted, lacks a
native reviewed schematic/ERC result, and has an open pack-return safety gate.
`hardware/pcb/test-board-rev-a/READINESS.md` lists the release evidence.

## Power boundary

- **Bench:** Mean Well 12 V supply for CM4IO and a separate current-limited lab
  supply for Test PCB/fault work.
- **VRX:** use the receiver's documented 6.5–26 V input and supplied harness;
  Test PCB J4 does not power it.
- **Decoder:** use only the EVM's documented supply; J5 does not power it.
- **Future deck:** T8L two-18650 source is `NEEDS MEASUREMENT`; no charger,
  series/parallel topology, capacity, or safe added-load budget is assumed.
- **External balance port:** measurement only and never powers FpvDeck.

## Before checkout

1. Re-open every product page and save invoice/MPN/board revision.
2. Confirm CM4IO/display cable contents before ordering the adapter twice.
3. Keep SteadyView X and ADV7282 EVM out of the cart until the CSI bridge review.
4. Do not purchase another ELRS TX, generic EasyCAP, HDMI capture dongle, bare Test
   PCB, final battery/charger, or undocumented RF module.

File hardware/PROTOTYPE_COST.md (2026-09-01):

# Prototype cost model

Snapshot: 2026-09-01, EUR. Prices are unit planning values; VAT treatment is noted
where known and shipping is excluded. The model separates money that unlocks
useful work now from the unresolved analog-video chain.

| Group | Subtotal | Confidence / assumption |
| --- | ---: | --- |
| CM4 + CM4IO | €163.00 | German retail, VAT included |
| 6.25-inch touch + DSI adapter | €77.45 | German retail, VAT included; adapter may already be unnecessary |
| CM4IO 12 V supply | €14.95 | German retail, VAT included |
| Nucleo + external ST-LINK | €55.90 | Nucleo price locale/VAT verify; V3SET snapshot |
| USB removable-media reader + 128 GB endurance card | €41.94 | German retail, VAT included |
| **BUY NOW subtotal** | **€353.24** | before shipping; minor rounding/source drift from live pages expected |
| Cable, headers and bench-fixture contingency | €50 | allowance |
| **Immediate working budget** | **€403.24** | does not include lab instruments |

## Gated additions

| Group | Allowance | Gate |
| --- | ---: | --- |
| SteadyView X ground-station kit, antennas/cables included | €219–250 | complete decoder/CM4 chain credibility; cable continuity test |
| ADV7282A-M evaluation board | €203–300 | real stock, board revision and NRND acceptance |
| controlled-impedance MIPI SMA→CM4IO bridge | €100–250 | schematic, connector mapping, layout and fab quotes |
| 75 Ω coax/adapters/termination | €35–70 | exact receiver cable and EVM connector inventory |
| Test PCB Rev A, five boards + components + stencil | €220–400 | schematic/ERC, safety, routing/DRC, footprint and release gates |
| isolated precision tap simulator/fixture | €100–250 | fixture design and existing lab-equipment inventory |

Full bench architecture allowance is therefore approximately **€1,280–1,920**
including the immediate kit, gated video chain, a released Test PCB build, and
fixtures—but excluding oscilloscope, lab supply, multimeter, shipping and import
charges. This replaces the earlier misleading single total that treated all EVMs
as simultaneously orderable.

The T8L is already owned. The model contains **no extra ELRS transmitter** and no
separate initial VRX antennas because the selected SteadyView X EU kits include a
patch and an omni antenna.

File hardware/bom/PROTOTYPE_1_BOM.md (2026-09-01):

# Prototype 1 planning BOM

This is a legacy design allowance, not the current purchase list. Use
[`PROTOTYPE_SYSTEM_EU.csv`](PROTOTYPE_SYSTEM_EU.csv) and
[`../ORDER_LIST_EU.md`](../ORDER_LIST_EU.md) for compatibility-gated purchasing.

| Qty | Manufacturer | MPN / exact item | Description | Allowance | Datasheet/source | Lifecycle / alternative |
| ---: | --- | --- | --- | ---: | --- | --- |
| 1 | Raspberry Pi | CM4104032 or chosen 4 GB/32 GB eMMC CM4 variant | compute module | €85 | [CM4 brief](https://datasheets.raspberrypi.com/cm4/cm4-product-brief.pdf) | through ≥Jan 2034; exact variant verify |
| 1 | Raspberry Pi | CM4 IO Board | documented bench carrier | €45 | [CM docs](https://www.raspberrypi.com/documentation/computers/compute-module.html) | other proven carriers acceptable |
| 1 | Raspberry Pi | Touch Display 2, 5-inch | low-risk 720×1280 DSI bring-up fallback | €45 | [display docs](https://www.raspberrypi.com/documentation/accessories/touch-display-2.html) | not representative of desired final size |
| 1 | Waveshare | 6.25-inch DSI LCD | 720×1560 bonded larger-display evaluation | price at purchase | [product](https://www.waveshare.com/6.25inch-dsi-lcd.htm) | brightness/scan/latency unknown; evaluate before final panel |
| 1 | Analog Devices | EVAL-ADV7282-MEBZ or verified ADV7280A-M EVM | CVBS-to-CSI bridge evaluation | €250 allowance | [ADV7280A](https://www.analog.com/en/products/ADV7280A.html) | exact stock/connector kit verify |
| 1 | Skyzone | SteadyView X 5.8G ground-station kit | dedicated 5.8 GHz RF-to-CVBS receiver; separate from T8L ELRS | €219–250 EU | [product](https://www.skyzonefpv.com/en-de/products/skyzone-stvx-steadyview-x-receiver) | WAIT for complete decoder/CM4 chain; kit includes antennas |
| 1 | ST | NUCLEO-G0B1RE | MCU development board | €25 | [board family](https://www.st.com/en/evaluation-tools/nucleo-g0b1re.html) | exact current stock verify |
| 1 | Texas Instruments | ADS7066EVM-PDK | ADC candidate A evaluation | €180 allowance | [EVM](https://www.ti.com/product/ADS7066) | ADS8688A candidate B |
| 1 | Texas Instruments | ADS8688EVM-PDK or current ADS8688A EVM | protected-AFE ADC evaluation | €250 allowance | [ADS8688A](https://www.ti.com/product/ADS8688A) | exact A-version EVM compatibility verify |
| 1 | Texas Instruments | BQ25792EVM | charger/power-path evaluation | €220 allowance | [EVM](https://www.ti.com/tool/BQ25792EVM) | do not attach cells before procedure review |
| 1 | Texas Instruments | TPS55288EVM-053 | 5 V rail evaluation | €150 allowance | [EVM](https://www.ti.com/tool/TPS55288EVM-053) | output configuration/thermal design required |
| 1 kit | Skyzone | supplied RHCP patch + omni | initial VRX diversity antennas | included | receiver kit | verify gender/polarization before spares |
| 1 | TBD | protected two-cell pack test fixture | energy source, fused/monitored | €100 | donor series/parallel topology unknown | bench supply first |
| lot | known vendors | documented cables, FFC adapters, 75 Ω coax/termination | interconnect/test | €150 | freeze in wiring doc | no improvised CSI wiring |

Expected module/evaluation spend is roughly €1,700 before instruments. EVM cost is
intentional: it buys known-good references and reduces the risk of debugging an
unproven decoder, precision AFE and power board simultaneously.

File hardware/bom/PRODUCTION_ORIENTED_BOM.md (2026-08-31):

# Production-oriented BOM (pre-schematic)

No reference designators or quantities are frozen because no release schematic
exists. This table records lifecycle leads only.

| Manufacturer | Candidate MPN | Function | Planning price | Status / alternative |
| --- | --- | --- | ---: | --- |
| Renesas | TW9992AT-NA1-GET | PAL/NTSC CSI-2 decoder | €6–12 | active; driver and full datasheet access gate |
| TBD | 5.5–6.25-inch high-brightness DSI panel | integrated outdoor display | TBD | part reopened for size; sample/init/scan/latency/power gate |
| Winstar | WF50DSYA3MNN0 | 5-inch 1100-nit DSI IPS fallback | €35–70 | bright but smaller than desired; retain as comparison |
| ST | STM32G0B1CBT6 class | hardware controller | €3–7 | exact package/flash after pin budget |
| TI | ADS7066RTER | 8-channel 16-bit ADC | €8–15 | frontend candidate; ADS8688A alternative |
| TI | BQ25792RQMR | 1–4S buck-boost charger/NVDC | €8–15 | USB-C policy and thermal validation |
| TI | TPS55288RPMR | main buck-boost | €5–10 | inductor/FET/thermal/EMI design gate |
| NXP/SoM vendor | i.MX 8M Plus industrial SoM TBD | production compute | €90–180 | vendor/lifecycle/BSP evaluation required |
| TDK/Murata/vendor TBD | qualified filters/inductors | power and RF isolation | TBD | select from calculations and stock |

Supplier examples and alternates will be added only when footprints, ratings and
source longevity are verified. Distributor CAD is not accepted as the sole land-
pattern authority; package drawings come from manufacturer datasheets.

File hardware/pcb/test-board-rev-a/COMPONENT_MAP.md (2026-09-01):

# Test PCB Rev A component map

Placed top-side component map

This map is generated from the committed KiCad board. It shows where subsystems
are intended to live; the board remains unrouted and unreleased.

| Block | References | Notes |
| --- | --- | --- |
| Balance connector | J1 | exact JST `B7B-XH-A(LF)(SN)`; external pack is measurement-only |
| Tap protection/dividers | RN1–RN6, R1–R7, C1–C6 | exact matched arrays; B− sense is separate from the DNP return experiment |
| Precision ADC | U1 | ADS8688AIDBT, ADC0 B−, ADC1 deck monitor, ADC2–ADC7 tap 1–6 |
| Hardware controller | U2 | STM32G0B1CBT6 plus SWD/UART/test access |
| Bench power | J2, F1, D1, U3 | board-development input; not a frozen T8L power design |
| Experimental return | F2, TP33, TP34 | DNP; only for current-limited fault experiments |
| Linux interface | J3 | project-defined low-speed SBC communication/control |
| 5.8 GHz VRX handoff | J4 | CVBS-only: 2=GND, 3=CVBS, others NC; receiver powered externally |
| Decoder handoff | J5 | CVBS-only: 2=GND, 3=CVBS, others NC; decoder powered externally |
| Expansion/debug | J6 and test points | bring-up access; verify every mating cable before use |

## Off-board modules

The following are not components supplied by the T8L and are not integrated on
Rev A: the dedicated 5.8 GHz analog VRX, CVBS decoder EVM, CM4/CM4IO, HD
touchscreen, removable-media reader, and their power supplies. The T8L contributes
the independent 2.4 GHz ELRS control radio, its RF path, gimbals/controls, and
potentially its two-cell battery source after measurement.

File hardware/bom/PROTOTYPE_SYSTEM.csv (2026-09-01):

Group | Qty | Manufacturer | Exact item | Why needed | Approx price USD | Source | Status | Compatible alternative
Already owned | 1 | RadioMaster | T8L | Donor gimbals controls and ELRS radio | 0 | User-owned | OWNED | None
Compute | 1 | Raspberry Pi | CM4104032 Compute Module 4 4GB RAM 32GB eMMC | Documented CSI/DSI and H.264 prototype compute | 85 | https://www.raspberrypi.com/products/compute-module-4/ | ORDER NOW | Another eMMC CM4 with >=2GB RAM
Compute | 1 | Raspberry Pi | Compute Module 4 IO Board | Known-good carrier with two CSI and two DSI connectors | 45 | https://www.raspberrypi.com/products/compute-module-4-io-board/ | ORDER NOW | Verified CM4 carrier exposing both MIPI ports
Compute | 1 | Raspberry Pi | 27W USB-C power supply or regulated 12V 2A adapter | Safe CM4IO bench power | 15 | https://www.raspberrypi.com/products/27w-power-supply/ | ORDER NOW | Current-limited bench supply per CM4IO datasheet
Display | 1 | Waveshare | 6.25inch DSI LCD (B) SKU 35000 | Selected 720x1560 500-nit five-touch prototype display | 59.99 | https://www.waveshare.com/6.25inch-dsi-lcd-b.htm | ORDER NOW | Pi Touch Display 2 5-inch fallback
Video | 1 | Analog Devices | EVAL-ADV7282AMEBZ | ADV7282A-M CVBS-to-one-lane-CSI evaluation kit; SMA CSI output | 300 allowance | https://www.analog.com/en/resources/evaluation-hardware-and-software/evaluation-boards-kits/eval-adv7282a-m.html | VERIFY STOCK AND BRIDGE | Exact older Pi-tested EVAL-ADV7282MEBZ if genuinely available
Video | 1 | Skyzone | SteadyView X ground-station kit | Dedicated dual 5.8GHz RF-to-CVBS receiver; separate from T8L ELRS control | 219 | https://www.skyzonefpv.com/en-de/products/skyzone-stvx-steadyview-x-receiver | WAIT FOR DECODER-TO-CM4 CHAIN | TBS Fusion only if available for A/B
Video | 1 | Skyzone | Included RHCP patch and omni antenna pair | Initial VRX diversity reception | 0 | Included in current SteadyView X EU kits | WAIT WITH VRX | Verify SMA gender/polarization on receipt before buying spares
Controller | 1 | STMicroelectronics | NUCLEO-G0B1RE | Bring-up firmware before custom board | 25 | https://www.st.com/en/evaluation-tools/nucleo-g0b1re.html | ORDER NOW | NUCLEO-G0B1 development equivalent
Debug | 1 | STMicroelectronics | STLINK-V3MINIE | SWD debugging for custom MCU | 15 | https://www.st.com/en/development-tools/stlink-v3minie.html | ORDER NOW | On-board Nucleo ST-LINK during early tests
Debug | 1 | Saleae | Logic 8 | Protocol and timing debug | 499 | https://www.saleae.com/products/saleae-logic-8 | OPTIONAL | Known-good 8-channel 24MHz+ analyzer
Storage | 1 | SanDisk | High Endurance 128GB microSD | DVR/removable media test | 20 | https://www.westerndigital.com/products/memory-cards/sandisk-high-endurance-uhs-i-microsd | ORDER NOW | Industrial/high-endurance 64GB+

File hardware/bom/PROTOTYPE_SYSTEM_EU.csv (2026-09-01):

Group | Qty | Manufacturer | Exact model or MPN | Purpose | Primary EU supplier | Primary URL | Alternative EU supplier | Alternative URL | Approx EUR | VAT status | Availability snapshot | Compatibility status | Procurement status | Notes
Already owned | 1 | RadioMaster | T8L | 2.4 GHz ELRS control donor; Hall gimbals; controls; controller electronics; initial dual-18650 arrangement pending verification | User-owned |  | User-owned |  | 0 | Owned | Owned | CONTROL ONLY | OWNED | No analog VRX/decoder/display/media/balance hardware supplied
Compute | 1 | Raspberry Pi | CM4104032 | 4GB/32GB eMMC Linux compute | BerryBase | https://www.berrybase.de/en/raspberry-pi-compute-module-4-4gb-ram-32gb-flash-wlan-bt | Farnell NL | https://nl.farnell.com/en-NL/raspberry-pi/cm4104032/rpi-module-4-4gb-ram-32gb-emmc/dp/3563490?gross_price=true | 127.10 | Included at primary | 10 shown at primary snapshot | CONFIRMED for CM4IO | BUY NOW | WLAN variant acceptable for bench; FPV must not depend on network
Compute | 1 | Raspberry Pi | Compute Module 4 IO Board | Documented CSI/DSI/USB bench carrier | BerryBase | https://www.berrybase.de/en/raspberry-pi-compute-module-4-io-board | Rasppishop | https://www.rasppishop.de/CM4-IO-Board | 35.90 | Included | In stock snapshot | CONFIRMED | BUY NOW | Two CSI and two DSI; decoder bridge still separate
Display | 1 | Waveshare | 6.25inch DSI LCD B SKU 35000 | 720x1560 capacitive five-touch display | OpenELAB GmbH | https://openelab.de/products/waveshare-6-25inch-dsi-lcd-b-capacitive-touch-display | Waveshare direct | https://www.waveshare.com/product/luckfox/6.25inch-dsi-lcd-b.htm | 74.95 | Included at primary | Orderable snapshot | CONFIRMED CM4 examples / latency needs measurement | BUY NOW | Verify contents and landscape/pinch fit
Display | 1 | Waveshare | 19134 CM4 DSI adapter | 22-pin CM4IO DSI adaptation | BerryBase | https://www.berrybase.de/en/raspberry-pi-compute-module-4-io-board | Waveshare direct | https://www.waveshare.com/ | 2.50 | Included at primary | 14 shown on CM4IO page snapshot | VERIFY cable kit contents | BUY NOW | Omit if display kit already includes exact adapter
Power bench | 1 | Mean Well | GST36E12-P1J | 12V 3A isolated CM4IO supply | Reichelt | https://www.reichelt.de/de/de/shop/produkt/steckernetzteil_36_w_12_v_3_a-171106 | Farnell DE | https://de.farnell.com/en-DE/mean-well/gst36e12-p1j/adaptor-ac-dc-12v-3a/dp/2815899 | 14.95 | Included at primary | Stocked snapshot | CONFIRMED for CM4IO barrel input | BUY NOW | Not used for unreviewed balance fault tests
Analog VRX | 1 | Skyzone | SteadyView X 5.8G ground-station kit | 5.8GHz RF to CVBS receiver | La Camera Embarquee | https://www.lacameraembarquee.fr/en/fpv-receivers/19734-skyzone-steadyview-x-58ghz-receiver-with-ips-screen.html | Baltic Drones | https://balticdrones.eu/products/vrx-skyzone-steadyview-x-4-9-5-8g-ips | 219.00 | Primary page says before tax; alternative says tax included | Both in stock snapshot | RF-to-CVBS CONFIRMED; full decoder chain OPEN | WAIT CHAIN GATE | Kit includes patch/omni antennas power cable and video cable
VRX antenna | 1 kit | Skyzone | Included RHCP patch plus omni | Initial two-antenna diversity | Included with VRX | https://www.lacameraembarquee.fr/en/fpv-receivers/19734-skyzone-steadyview-x-58ghz-receiver-with-ips-screen.html | Included with VRX | https://balticdrones.eu/products/vrx-skyzone-steadyview-x-4-9-5-8g-ips | 0 | Included | Included | CONFIRM connector/polarization on receipt | WAIT WITH VRX | Do not order extra antennas initially
Video decoder | 1 | Analog Devices | EVAL-ADV7282AMEBZ | CVBS to one-lane MIPI CSI-2 evaluation | ADI/Mouser EU | https://www.mouser.de/en/ProductDetail/Analog-Devices/EVAL-ADV7282AMEBZ?qs=1mbolxNpo8dXn4uu0WGlNw%3D%3D | Analog Devices | https://www.analog.com/en/resources/evaluation-hardware-and-software/evaluation-boards-kits/eval-adv7282a-m.html | 250 allowance | Verify at checkout | Restricted availability at direct check | SMA-to-CM4IO bridge OPEN / silicon NRND | WAIT STOCK+BRIDGE | Not a 5.8GHz receiver; it only digitizes CVBS
MIPI bridge | 1 | FpvDeck | TBD reviewed SMA-to-CM4IO CSI bridge | Controlled-impedance decoder EVM connection | Not designed |  | Not designed |  | 175 allowance | Unknown | Not available | UNKNOWN / requires design review | WAIT | Do not improvise with loose wires
MCU development | 1 | STMicroelectronics | NUCLEO-G0B1RE | Firmware and ADC SPI bring-up | Mouser EU | https://www.mouser.es/es/ProductDetail/STMicroelectronics/NUCLEO-G0B1RE?qs=pUKx8fyJudAJjwoMOxyZhg%3D%3D | ST distributor selector | https://www.st.com/en/evaluation-tools/nucleo-g0b1re.html | 16.80 | Verify locale | 636 stock snapshot | CONFIRMED | BUY NOW | Onboard ST-LINK supports first bring-up
Debugger | 1 | STMicroelectronics | STLINK-V3SET | External SWD/debug | Mouser DE | https://www.mouser.de/de/ProductDetail/STMicroelectronics/STLINK-V3SET?qs=qSfuJ%252Bfl%2Fd5d4WYsOW6M6w%3D%3D | Mouser DE | https://www.mouser.de/de/ProductDetail/STMicroelectronics/STLINK-V3MINIE?qs=MyNHzdoqoQKcLQe5Jawcgw%3D%3D | 39.10 | Verify checkout | 389 stock snapshot for V3SET | CONFIRMED | BUY NOW | V3MINIE alternative stock snapshot conflicted; recheck
Precision ADC sample | 2 | Texas Instruments | ADS8688AIDBT | Test PCB eight-channel protected precision ADC | Mouser EU | https://eu.mouser.com/en/ProductDetail/Texas-Instruments/ADS8688AIDBT?qs=xufs61hA5MZv%2F46DP%252BYoHw%3D%3D | Texas Instruments | https://www.ti.com/product/ADS8688A | 25.08 each | Verify checkout | 336 stock snapshot | SCHEMATIC/PCB RELEASE OPEN | BUY SAMPLE ONLY | TSSOP-38; not solderless-breadboard friendly
Balance connector sample | 2 | JST | B7B-XH-A LF SN | Exact 7-position protected balance-input connector fit check | Mouser DE | https://www.mouser.de/ProductDetail/JST-Commercial/B7B-XH-ALFSN?qs=cdbOS8ANM9DLeRSemn13Pg%3D%3D | JST distributor search | https://www.jst-mfg.com/ | 0.232 each | Verify checkout | 18101 stock snapshot | FOOTPRINT FIT OPEN | BUY SAMPLE ONLY | Full PCB quantity waits for release
Removable media | 1 | Transcend | TS-RDF5K | USB-A SD/microSD reader for goggle/DVR cards | Reichelt | https://www.reichelt.de/de/de/shop/produkt/card_reader_extern_usb_3_2_gen_1_schwarz_rdf5-147618 | Reichelt | https://www.reichelt.de/de/de/shop/produkt/card_reader_extern_usb_3_0_weiss_rdf5-147619 | 7.95 | Included | In stock 1-2 days snapshot | Linux USB mass-storage credible | BUY NOW | External bench solution; production interface not frozen
Removable media | 1 | SanDisk | SDSQQNR-128G-GN6IA | 128GB high-endurance DVR test card | MediaMarkt | https://www.mediamarkt.de/de/product/_sandisk-high-endurance-2551316.html | Geizhals EU offer index | https://geizhals.de/sandisk-high-endurance-r100-w60-microsdxc-128gb-kit-sdsqqnr-128g-gn6ia-a2041130.html | 33.99 | Included at primary | Available snapshot | CONFIRMED for reader | BUY NOW | Use authentic retailer; removable card is not CM4 eMMC
Test PCB | 5 | FpvDeck | Test PCB Rev A bare boards | Controller/balance/module-interface validation | Not released |  | Not released |  | TBD | Unknown | Not orderable | UNROUTED / NO ERC OR DRC | WAIT | Do not fabricate current committed board

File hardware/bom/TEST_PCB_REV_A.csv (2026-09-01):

Reference | Qty | Manufacturer | Manufacturer Part Number | Description | Package | Value | Tolerance | Rating | Supplier examples | Approx unit price USD | Datasheet | Lifecycle/availability | Assembly notes | Alternative | Status
PCB1 | 1 | TBD | FpvDeck-Test-PCB-Rev-A | Four-layer bare test PCB | 120x90mm FR-4 | 1.6mm |  | 1oz copper | TBD | 15.00 | hardware/pcb/test-board-rev-a/FABRICATION_NOTES.md | WAIT until release gates close | Do not order from current Gerbers |  | WAIT
U1 | 1 | Texas Instruments | ADS8688AIDBT | 8-channel 16-bit 500kSPS protected SAR ADC | TSSOP-38 DBT | ADS8688A |  | 4.75-5.25V AVDD; -40..125C | DigiKey/Mouser/TI | 24.00 | https://www.ti.com/lit/ds/symlink/ads8688a.pdf | Active; verify stock at order | Hand/reflow; pin-1 inspection | ADS8688ATDBT after compatibility review | Required
U2 | 1 | STMicroelectronics | STM32G0B1CBT6 | 64MHz Cortex-M0+ MCU with USB FS | LQFP-48 7x7 P0.5mm | 128KB flash |  | 1.7-3.6V; -40..85C | DigiKey/Mouser/ST | 5.50 | https://www.st.com/resource/en/datasheet/stm32g0b1cb.pdf | Active/in volume production | Flash over SWD before functional test | STM32G0B1CCT6 if firmware image adjusted | Required
U3 | 1 | Texas Instruments | TLV75533PDBVR | 500mA 3.3V low-IQ LDO | SOT-23-5 | 3.3V |  | 5.5V max input | DigiKey/Mouser/TI | 0.75 | https://www.ti.com/lit/ds/symlink/tlv755p.pdf | Active | Observe thermal/load limit | TLV75533PDBVT | Required
J1 | 1 | JST | B7B-XH-A(LF)(SN) | 7-position top-entry balance header | JST XH THT 1x7 P2.50mm | 7 way |  | 250V 3A series rating subject to wire/contact | JST distributors/DigiKey/Mouser | 0.45 | https://www.jst-mfg.com/product/pdf/eng/eXH.pdf | Current; exact suffix may print on label | Verify 1:1 footprint and mating harness orientation | None without PCB review | Required
J2 | 1 | Phoenix Contact | 1715721 | MKDS 1.5/2-5.08 two-position terminal block | THT 1x2 P5.08mm | 5V bench input |  | 16A family rating; board limited below 0.5A | DigiKey/Mouser | 2.20 | https://www.phoenixcontact.com/en-us/products/pcb-terminal-block-mkds-15-2-508-1715721 | Current | Mark polarity on silk | Equivalent 5.08mm terminal only after footprint check | Required
J3 | 1 | Samtec | TSW-110-07-G-D | 20-position 2.54mm vertical SBC header | THT 2x10 P2.54mm | 2x10 |  |  | DigiKey/Mouser/Samtec | 2.50 | https://www.samtec.com/products/tsw | Current | Generic project interface; not T8L pinout | Any footprint-compatible quality header | Required
J4 J5 | 2 | Samtec | TSW-106-07-G-S | 6-position CVBS breakout header | THT 1x6 P2.54mm | 1x6 |  |  | DigiKey/Mouser/Samtec | 1.00 | https://www.samtec.com/products/tsw | Current | Only pin 2 GND and pin 3 CVBS are connected; pins 1/4/5/6 NC; receiver and decoder use separate verified power harnesses | Any footprint-compatible quality header | Required
J6 | 1 | Harwin | M50-3500542 | 10-position 1.27mm vertical SWD header | THT 2x5 P1.27mm | 2x5 |  |  | DigiKey/Mouser | 2.00 | https://www.harwin.com/products/M50-3500542 | Verify current stock and drawing | Footprint verification gate | Tag-Connect cable via adapter | Optional
RN1-RN6 | 6 | Vishay | ACASA1002U1002P1AT | Four isolated matched 10k thin-film resistors | ACAS 0612 8-pad | 10k x4 | 0.1% absolute; 0.05% ratio | 10ppm/K absolute; 5ppm/K ratio; 0.1W/element | DigiKey 8110995/Mouser | 3.11 | https://www.vishay.com/docs/28959/acas0612.pdf | Active; visible authorized stock | Pad pairing continuity check before population | None without error-budget rerun | Required
R1-R7 | 7 | Yageo | RT0603BRD071KL | Thin-film series input resistor | 0603 | 1.00k | 0.1% | 0.1W; 25ppm/C; 75V family | DigiKey/Mouser/LCSC | 0.10 | https://www.yageo.com/upload/media/product/productsearch/datasheet/rchip/PYu-RT_51_RoHS_L_14.pdf | Active | R1-R6 protect cumulative taps; R7 joins BNEG_RAW to BNEG_SENSE and needs calibration | Any 1k 0.1% <=25ppm/C 0603 thin film | Required
C1-C6 | 6 | KEMET | C0603C103J5GACTU | C0G analog input filter capacitor | 0603 | 10nF | 5% | 50V | DigiKey/Mouser | 0.18 | https://content.kemet.com/datasheets/KEM_C1002_C0G_SMD.pdf | Active | Place at ADC-side node | Equivalent C0G/NP0 10nF 50V | Required
C18 C19 | 2 | Murata | GRM31CR71A226KE15L | Reference decoupling capacitor | 1206 | 22uF | 10% | 10V X7R | DigiKey/Mouser | 0.55 | https://search.murata.co.jp/Ceramy/image/img/A01X/G101/ENG/GRM31CR71A226KE15-01.pdf | Active | Place at REFIO/REFCAP; verify DC-bias capacitance | Two parallel qualified 10uF parts after review | Required
C20-C24 | 5 | Murata | GRM21BR71A105KA01L | Supply decoupling capacitor | 0805 | 1uF | 10% | 10V X7R | DigiKey/Mouser | 0.12 | https://search.murata.co.jp/Ceramy/image/img/A01X/G101/ENG/GRM21BR71A105KA01-01.pdf | Active | Place close to relevant supply pins | Equivalent X7R 1uF >=10V | Required
C25 | 1 | Murata | GRM21BR71C104KA01L | MCU high-frequency decoupling capacitor | 0805 | 100nF | 10% | 16V X7R | DigiKey/Mouser | 0.08 | https://search.murata.co.jp/Ceramy/image/img/A01X/G101/ENG/GRM21BR71C104KA01-01.pdf | Active | Place at MCU supply | Equivalent X7R 100nF >=10V | Required
C26 | 1 | Murata | GRM21BR71A475KA73L | MCU bulk decoupling capacitor | 0805 | 4.7uF | 10% | 10V X7R | DigiKey/Mouser | 0.18 | https://search.murata.co.jp/Ceramy/image/img/A01X/G101/ENG/GRM21BR71A475KA73-01.pdf | Active | Place near MCU supply | Equivalent X7R 4.7uF >=10V | Required
F1 | 1 | Bourns | MF-MSMF050-2 | Resettable bench-input fuse | 1206 PTC | 0.5A hold |  | 15V; 1A trip | DigiKey/Mouser | 0.35 | https://www.bourns.com/docs/product-datasheets/mf-msmf.pdf | Active | Current-limit lab supply to 100mA on first power-up | Littelfuse 1206L050 | Required
F2 | 1 | Littelfuse | 1206L010/60WR | Provisional resettable pack-negative reference link | 1206 PPTC | 0.10A hold |  | 60V max; 0.25A trip; 0.5ohm min; 1.5ohm typical; 10ohm R1 max | DigiKey/Mouser/Littelfuse | 0.45 | https://www.littelfuse.com/assetdocs/littelfuse-ptc-1206l-datasheet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 | Current ordering number in manufacturer datasheet | DO NOT POPULATE: topology and exact land pattern are not approved; characterize only with current-limited simulator | None without fault-analysis review | DNP
TP1-TP6 TP11-TP16 TP30-TP34 | 17 | Keystone Electronics | 5001 | Through-hole miniature loop test point | THT loop | Test point |  |  | DigiKey/Mouser | 0.35 | https://www.keyelco.com/product.cfm/product_id/140 | Active | Use color sleeves for raw/ADC/rail/B-negative groups | Equivalent 1.0mm-drill loop test point | Required
H1-H4 | 4 | Keystone Electronics | 8831 | M3 nylon standoff 10mm | M3 hardware | 10mm |  |  | DigiKey/Mouser | 0.60 | https://www.keyelco.com/category.cfm/Standoffs-Spacers/Metric-Nylon-Spacers-Standoffs/id/1407 | Current | Not soldered; include matching screws | Equivalent M3 nylon hardware | Required

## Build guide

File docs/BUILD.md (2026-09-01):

# Build

## Ubuntu 24.04 / Debian-family desktop

Install the host toolchain:

```sh
sudo apt-get update
sudo apt-get install cmake ninja-build g++ ffmpeg v4l-utils \
  gstreamer1.0-libav gstreamer1.0-plugins-good gstreamer1.0-plugins-bad \
  qt6-base-dev qt6-declarative-dev qt6-multimedia-dev qt6-tools-dev-tools \
  qml6-module-qtquick qml6-module-qtquick-controls \
  qml6-module-qtquick-layouts qml6-module-qtquick-window \
  qml6-module-qtmultimedia qml6-module-qttest qml6-module-qtqml \
  qml6-module-qtqml-models qml6-module-qtqml-workerscript \
  qml6-module-qtquick-templates xvfb
```

Build, test, and launch:

```sh
./scripts/check
./scripts/dev
./scripts/demo
```

`scripts/generate-test-video` creates copyright-free PAL-shaped synthetic test
footage locally with FFmpeg. The text drawn into that video represents an OSD
that was already burned in at the aircraft. FPVDeck's colored widgets are QML
elements composited above it.

Set `FPVDECK_DATA_DIR` to relocate the simulator database. Set
`FPVDECK_BUILD_DIR` to relocate the build tree. `fpvdeck --help` lists runtime
arguments.

`./scripts/screenshot-demo` additionally requires `xvfb-run` (provided by the
`xvfb` package above) and regenerates the committed deterministic UI previews.
`./scripts/benchmark-ui` uses the same dependency to collect repeated desktop
first-frame/RSS regression records under `generated/benchmarks/ui/`.

## Raspberry Pi / Prototype 0

On current 64-bit Raspberry Pi OS:

```sh
git clone https://github.com/wiekstras/FpvDeck.git
cd FpvDeck
./scripts/setup-pi
./scripts/fpvdeck-video-list
./scripts/prototype0 --device /dev/video0 --standard PAL
```

`setup-pi` installs only Debian packages and is idempotent. `--dry-run` prints
the package transaction. The real device node and standard must match the output
of `fpvdeck-video-list` and the Air65 configuration.

## macOS

The source architecture is portable, but the macOS dependency/bootstrap script
has not yet been verified. Install Qt 6, CMake, Ninja, and FFmpeg through a
package manager, then configure with the Qt prefix visible to CMake. This is an
open verification task, not a claimed supported path yet.

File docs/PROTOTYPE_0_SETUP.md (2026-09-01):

# Prototype 0 setup

This guide starts after the items in [Buy Tonight](../hardware/PROTOTYPE_0_BUY_TONIGHT.md)
arrive. Read [the exact wiring table](../hardware/prototype-0/WIRING.md) first.

## 1. Prepare the Pi

1. Use Raspberry Pi Imager to write current 64-bit Raspberry Pi OS with Desktop
   to the 64 GB card. Configure a user, Wi-Fi and SSH in Imager if desired.
2. With all power disconnected, fit the official Active Cooler.
3. Connect Touch Display 2 using its supplied Pi 5 22-to-15-way FFC and GPIO
   power cable. Verify GPIO pin 2 is red/+5 V and pin 6 is black/ground.
4. Insert the microSD and connect the official 27 W USB-C supply.
5. Boot, update the OS, and rotate display/touch together to landscape in Raspberry
   Pi Control Centre. Verify tap, drag, swipe, long press and the on-screen keyboard.

## 2. Install FpvDeck

```bash
git clone https://github.com/wiekstras/FpvDeck.git
cd FpvDeck
./scripts/setup-pi
```

The setup is safe to re-run. After it completes:

```bash
./scripts/dev
```

Use the simulator first to verify the build, touch navigation and landscape
orientation before connecting RF/video hardware.

## 3. Connect receiver and capture

1. Keep both wall supplies unplugged.
2. Attach the supplied antenna to RC832 `ANT`.
3. Connect the supplied RC832 AV cable from `AV OUT`; connect its yellow composite
   RCA plug to UVG-002 yellow composite input.
4. Plug UVG-002 into a Pi USB-A port.
5. Build the verified 12 V connection exactly as described in
   [WIRING.md](../hardware/prototype-0/WIRING.md). Measure polarity before power.
6. Apply receiver power. Do not power RC832 from the Pi.

## 4. Verify raw capture

```bash
./scripts/fpvdeck-video-list
v4l2-ctl --device /dev/video0 --list-inputs
./scripts/test-video --device /dev/video0 --input N --standard PAL
```

The node may be `/dev/video1` or another number. Select the node whose description
is USBTV007/`usbtv` or `AV TO USB2.0`/`uvcvideo` (wording depends on the
received Gembird chipset) and whose formats include the video-capture stream. If access is
denied, add the current user to `video`, log out/in, and retry:

```bash
sudo usermod -aG video "$USER"
```

Replace `N` with the input index whose driver-reported name is composite. Do not
copy an index from this guide: input numbering is evidence captured from the
received unit and driver. Omit `--input` only if the composite input is already
selected.

## 5. Tune and test the Air65

1. Remove the props.
2. Determine the configured VTX frequency in Betaflight as described in
   [AIR65_TESTING.md](AIR65_TESTING.md).
3. Set RC832 `FR` (band) and `CH` to the same frequency.
4. Power Air65 with its normal 1S battery.
5. Confirm raw video and Betaflight OSD in `test-video` before involving FpvDeck.

## 6. Launch real hardware mode

```bash
./scripts/prototype0 --device /dev/video0 --input N --standard PAL
```

Prototype 0 mode uses real V4L2 video and real touch while battery, telemetry,
T8L diagnostics and direct VRX control remain simulated. With no capture device,
the command prints a warning and falls back to the synthetic feed so the UI still
starts.
If UVG-002 is unplugged and reconnected at the same device path, FpvDeck watches
Qt's device list and attempts to resume the camera without restarting the shell.

Verify in order:

1. Air65 video moves and its monochrome Betaflight OSD remains visible.
2. FpvDeck's colour overlay is above the feed.
3. Tap video to show/hide controls; allow auto-hide to run.
4. Open apps and use flight lock.
5. Open Diagnostics; `CVBS CAPTURE` should show the UVG-002 capture node and `PASS`.
6. Start and stop DVR, then inspect the output before trusting longer recordings.
7. Disconnect the Air65 battery, confirm UI survival, reconnect and measure recovery.

## 7. Optional boot service

Do not enable auto-start until manual bring-up is reliable. Prototype 0 deliberately
keeps shell access. A systemd unit remains a follow-up after capture node persistence,
clean shutdown and log retrieval are verified on the actual Pi.

## Troubleshooting

- **No `/dev/video*`:** record `lsusb`, run both `modinfo usbtv` and
  `modinfo uvcvideo`, reseat UVG-002 and update Raspberry Pi OS. UTV007 commonly
  uses `usbtv` IDs such as `1b71:3002`; UTVF007 commonly appears as UVC
  `534d:0021`. Do not force either driver onto a different received ID.
- **UTVF007 gives a stable picture but hides RF noise:** this family is known to
  squelch weak/noisy composite input. That is acceptable for Prototype 0
  functionality, but record it as a limitation; it cannot validate final FPV
  weak-signal behavior.
- **Node exists but black:** select composite input and the correct PAL/NTSC norm
  with `v4l2-ctl`; verify yellow RCA, channel frequency and Air65 power.
- **Rolling/monochrome:** wrong standard or marginal RF. Try the correct norm, not
  arbitrary format conversions.
- **Touch rotated:** rotate the display in Raspberry Pi Control Centre so libinput
  applies the matching touch transform.
- **Pi undervoltage:** use the official 27 W supply; RC832 must retain its own 12 V PSU.

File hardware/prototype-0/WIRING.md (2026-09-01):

# Prototype 0 wiring

These instructions apply only to the exact [Prototype 0 reference
hardware](../PROTOTYPE_0_BUY_TONIGHT.md). Disconnect all power before changing
FFC, GPIO or receiver wiring.

## 1. Pi 5 → Touch Display 2

| From | To | Cable |
|---|---|---|
| Pi 5 either `CAM/DISP` connector | Touch Display 2 DSI connector | supplied 22-way-to-15-way FFC |
| Pi GPIO physical pin 2, +5 V | Display `J1` through red conductor | supplied three-wire GPIO power lead |
| Pi GPIO physical pin 6, ground | Display `J1` through black conductor | supplied three-wire GPIO power lead |
| Official 27 W supply USB-C | Pi 5 USB-C power input | captive PSU cable |

For the FFC, the wide 15-way end enters the display with contacts facing away
from the display. The small 22-way end enters the Pi with contacts facing the
Ethernet/USB-A connectors. Follow Raspberry Pi's illustrated instructions; an
incorrect GPIO power connection can damage the display.

## 2. Analog RF and CVBS

| From | To | Cable |
|---|---|---|
| supplied linear RP-SMA antenna | RC832 Mini `ANT` RP-SMA connector | direct; finger-tight only |
| RC832 Mini `AV OUT` 3.5 mm | yellow RCA composite input on Gembird UVG-002 | **supplied RC832 video cable** |
| Gembird UVG-002 USB-A | Pi 5 USB-A 2.0 port | captive USB plug |

The RC832 3.5 mm conductor assignment is not published in the one-page manual.
That is why the selected receiver's supplied cable is mandatory. Do not replace
it with a generic TRRS-to-RCA lead. Connect the antenna before applying receiver
power.

## 3. Receiver power

| From | To | Value |
|---|---|---|
| PCE12-12-1-WM barrel plug | Goobay 76743 female barrel adapter | 12 V DC, max 1 A |
| Adapter `+` terminal | factory-red conductor of the modified supplied receiver lead, after continuity cross-check | +12 V |
| Adapter `−` terminal | factory-black conductor of the modified supplied receiver lead, after continuity cross-check | 0 V |
| Barrel plug on supplied receiver lead | RC832 `DC12V` | receiver-supplied mating plug |

Before connecting the receiver:

1. Leave the wall supply unplugged from mains.
2. On the **loose receiver accessory power lead only**, cut off the undocumented
   red two-pole connector, leaving the maximum useful wire length. Do not cut or
   open the receiver and do not modify the T8L.
3. Strip approximately 6 mm from each conductor. With the lead disconnected from
   everything, use continuity mode to map each exposed conductor to the barrel
   plug centre or sleeve. Record the wire colour and map. The vendor's product
   image shows the supplied factory lead as red/black, but the receiver manual
   does not state jack polarity. Proceed only if red maps to barrel centre and
   black maps to sleeve. If the lead is unmarked, uses other colours, or gives a
   different map, stop and obtain written polarity confirmation from Rotorama.
4. Plug only the wall supply into the 76743 and measure its terminals: `+` to `−`
   must read approximately +12 V DC.
5. Unplug the wall supply. Land the verified factory-red/centre conductor in the
   adapter `+` terminal and the factory-black/sleeve conductor in `−`.
6. Inspect for loose strands and shorts. Reconnect the wall supply and measure
   approximately +12 V centre-to-sleeve at the receiver lead's barrel plug before
   inserting it. Unplug immediately if polarity or voltage is wrong.
7. Unplug mains again. Connect the antenna and AV lead, then insert the receiver's
   supplied barrel plug into `DC12V`.
8. Apply mains power and confirm the receiver display starts normally.

**Never** power the receiver from Pi GPIO. Wire colour is accepted only when the
factory red/black purpose and the continuity map agree; never infer polarity from
colour alone. The Air65 and external RC832 supply do not connect electrically.

## 4. What does not connect

- The T8L has no video cable to FpvDeck. Its link to Air65 is 2.4 GHz ELRS RF.
- The Air65 has no physical cable to the receiver during normal testing.
- Do not connect the T8L 18650 pack to Pi or VRX in Prototype 0.
- Do not connect an external LiPo balance lead; Battery Checker remains simulated.

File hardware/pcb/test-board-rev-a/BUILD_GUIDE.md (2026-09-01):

# Test PCB Rev A build guide

> **DO NOT BUILD THIS REVISION YET.** This guide defines the future staged build
> order and the evidence needed at each stop. `READINESS.md` is authoritative.

## Before ordering

1. Complete the native KiCad schematic and pass ERC.
2. Independently audit every symbol pin and exact footprint against its current
   manufacturer drawing; print the board 1:1 and place physical samples.
3. Close the pack-negative/reference fault analysis. F2 remains DNP.
4. Route planes/tracks, establish the stack-up, run DRC and peer-review the design.
5. Generate fabrication outputs only from a signed release tag.

## Staged assembly

1. Inspect the bare board and measure every rail to ground before population.
2. Fit only bench-input protection, 3.3 V regulation, decoupling, rail LEDs, and
   test points. Power from a current-limited isolated bench supply.
3. Fit the STM32, SWD and UART. Flash bring-up firmware and exercise LEDs,
   buttons, fan output, temperature input, heartbeat and shutdown signals.
4. Fit the ADC and SPI passives. Verify reference and supply pins before commands.
5. Fit one divider channel at a time and inject cumulative voltages using an
   isolated, current-limited simulator. Compare raw code and calibrated voltage.
6. Populate all six channels only after the single-channel error and leakage tests
   pass. Exercise missing/partial taps without a battery connected.
7. Connect J4/J5 only with a continuity-checked shielded adapter. Independently
   power the VRX and decoder according to their own manuals. Never energize an NC
   pin or infer a 3.5 mm plug contact assignment.

## Prohibited during initial bring-up

- no real LiPo on J1;
- no T8L internal power wiring;
- no F2 population;
- no earthed oscilloscope ground on an unreviewed pack node;
- no VRX or decoder power through J4/J5;
- no improvised wire bundle for MIPI CSI-2 or DSI.

Follow the complete [bring-up procedure](../../../docs/TEST_PCB_BRINGUP.md) after
release. Stop immediately on unexpected current, heating, rail voltage, or a
continuity result that disagrees with the schematic/netlist.

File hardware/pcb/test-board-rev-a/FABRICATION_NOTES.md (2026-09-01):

# Fabrication and assembly notes — pre-release

- The project declares four copper layers. A 1.6 mm FR-4, 1 oz outer-copper board
  is the current planning stack. Final dielectric/copper stack is not frozen.
- Minimum planning rules are 0.20 mm clearance and 0.20 mm trace; analog/power
  traces will be widened during routing.
- Assemble MCU, regulator, power protection and headers first. Leave ADC/divider
  section DNP until 5 V/3.3 V and USB/UART are verified.
- J1 must be exact JST `B7B-XH-A(LF)(SN)`. Print the land pattern at 1:1 and place
  the purchased connector before release.
- RN1–RN6 are exact Vishay `ACASA1002U1002P1AT`; do not substitute a bussed array.
- F2 is an experimental `1206L010/60WR` pack-reference link and is DNP. Its
  generic KiCad land pattern must be checked against the Littelfuse drawing, and
  it must not be fitted for initial power-up or real-LiPo use.
- Clean flux around high-impedance analog nodes and inspect at magnification.
- No conformal coat until leakage and calibration stability have been measured.
- Production files require schematic/ERC, PCB DRC, netlist comparison, fab drawing,
  drill review, solder-paste review and an independent release signature.

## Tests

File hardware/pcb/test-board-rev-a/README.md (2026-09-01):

# FpvDeck Test PCB Rev A

This KiCad project is the modular bring-up board for the external balance checker,
real-time MCU, precision ADC, controls, low-speed module interfaces, and shutdown
coordination. It deliberately does **not** route MIPI DSI/CSI or integrate RF.

## Release state

**NOT RELEASED FOR FABRICATION.** The generated `.kicad_pcb` is a real KiCad board
with verified package classes, net intent, probe access, and mechanical placement.
It is not being represented as manufacturing-ready while these gates remain:

1. independently verify `ACASA1002U1002P1AT` pad-to-element pairing against the
   Vishay drawing and continuity-test a sample;
2. freeze and fault-test the protected B− reference path; provisional F2 must
   remain DNP until that review explicitly approves population;
3. complete the native schematic/ERC review;
4. route power, ground, analog and USB; add planes; run DRC;
5. peer-check the ADS8688A and STM32 pad maps against current datasheets;
6. validate every footprint against the exact ordered MPN, then print 1:1.

The component BOM and system order list intentionally place bare-PCB fabrication
in `WAIT` until these gates close. Compute, display, MCU development hardware and
measurement equipment can be ordered independently. The VRX and decoder remain
behind the documented end-to-end compatibility gate.

## Regeneration

KiCad 7 with its Python module is currently used:

```bash
python3 hardware/pcb/test-board-rev-a/generate_board.py
kicad-cli pcb export pdf -o /tmp/test-board.pdf \
  hardware/pcb/test-board-rev-a/test-board-rev-a.kicad_pcb
```

Generated output is source controlled so contributors can inspect the board
without running the generator. Do not hand-edit the generated PCB without also
updating or retiring the generator.

## Partitioning

- left: JST-XH input, precision divider arrays, raw/ADC test points;
- center: ADS8688A and STM32G0B1;
- bottom: current-limited bench 5 V and local 3.3 V;
- right: SBC header plus separate VRX-CVBS and decoder-CVBS breakouts;
- direct CM4-to-display DSI and decoder-to-CM4 CSI stay off-board.

F2 (`1206L010/60WR`) and TP33/TP34 provide a replaceable, probeable experiment
between `BNEG_RAW` and local ground; R7 explicitly connects `BNEG_RAW` to the
separate ADC `BNEG_SENSE` net. F2 is **not an approved protection design**.
The PPTC's normal resistance produces measurable offset, its trip behavior is not
a substitute for a complete ground-fault design, and USB/bench/SBC grounds can
create alternate current paths. Keep it DNP and use only a current-limited,
non-battery simulator until the release gate in `docs/BATTERY_MEASUREMENT.md`
closes.

The controlled experiment matrix is
[`docs/BALANCE_GROUND_FAULT_ANALYSIS.md`](../../../docs/BALANCE_GROUND_FAULT_ANALYSIS.md).

J4 and J5 deliberately connect only pin 2 ground and pin 3 CVBS. All other pins
are NC. The SteadyView X receiver is powered through its documented 6.5–26 V
barrel/XT60 ground-station harness, not Test PCB 5 V. The decoder EVM also keeps
its own documented power/control/MIPI connections. Rev A therefore proves the
analog handoff without inventing either module's internal pinout.

## Board documents and views

- [Layout](LAYOUT.md)
- [Component map](COMPONENT_MAP.md)
- [Build guide](BUILD_GUIDE.md)
- [Release readiness](READINESS.md)
- [Fabrication notes](FABRICATION_NOTES.md)

The committed [top](exports/test-board-rev-a-top.svg),
[bottom](exports/test-board-rev-a-bottom.svg), and
[component-map](exports/test-board-rev-a-component-map.svg) SVGs are inspection
views of the placed, unrouted board. They are not fabrication outputs.

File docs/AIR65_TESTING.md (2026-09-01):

# Air65 analog video test procedure

The owned BetaFPV Air65 is Prototype 0's real analog source. BetaFPV confirms
that the current analog model integrates its camera, analog OSD, 2.4 GHz ELRS
receiver and 5.8 GHz 25–400 mW VTX. Control and video remain separate paths.

## Safety

1. Remove all four propellers before any bench test.
2. Place the Air65 on a non-conductive surface with airflow around its electronics.
3. Use its normal charged 1S BT2.0 flight battery. Do not improvise bench wiring.
4. Keep VTX tests short. Use the lowest usable configured VTX power and allow the
   quad to cool between long stationary sessions.
5. Fit the RC832 antenna before powering the receiver.

## Determine the exact channel

Do not guess the factory channel. With the props removed, connect Betaflight
Configurator and inspect **Video Transmitter**. Record band, channel, frequency
and power. If the UI cannot identify it, save the existing configuration and use
the Betaflight CLI `vtx`/`vtxtable` information without changing unrelated flight
settings. Raceband values are supported by the RC832 Mini, including R1 5658 MHz
through R8 5917 MHz.

## Test sequence

1. Assemble and power the Pi/display, receiver and USB capture with the Air65 off.
2. Set RC832 `FR` and `CH` to the Air65's recorded band/channel.
3. Run `./scripts/fpvdeck-video-list`; confirm the UVG-002 node. Depending on the
   received chipset it may identify as USBTV007/`usbtv` or UVC `AV TO USB2.0`.
4. Inspect `v4l2-ctl --device /dev/videoN --list-inputs`, then run
   `./scripts/test-video --device /dev/videoN --input N --standard PAL` using the
   actual capture node and driver-reported composite input index. If the configured
   camera standard is NTSC, select `--standard NTSC`.
5. Power the prop-less Air65 from its normal 1S pack.
6. Verify raw video and the embedded Betaflight OSD in the independent preview.
7. Run `./scripts/prototype0 --device /dev/videoN --input N --standard PAL`.
8. Verify video, FpvDeck RGB status chips, touch, menu auto-hide and flight lock.
9. Start/stop a short DVR recording and play it back.
10. Unplug only the Air65 battery and confirm FpvDeck remains responsive and shows
    loss/no-video behavior; reconnect and time recovery.
11. For weak-signal behavior, increase separation gradually while staying legal
    and keeping the stationary quad thermally safe. Do not fly for initial tests.

Record the receiver channel, reported capture format/FPS, dropped frames, recovery
time and rough glass-to-glass latency in the engineering log. UVG-002 latency is
a Prototype 0 baseline and is not a final product acceptance value.

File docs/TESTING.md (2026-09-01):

# Testing

Run the local CI-equivalent suite with:

```sh
./scripts/check
```

Current automated coverage includes cumulative balance-tap derivation for 1S–6S,
imbalance/noise and invalid tap cases; Monte Carlo balance-front-end calculations;
MCU protocol CRC/framing/corruption and board-command dispatch; and SQLite
migration plus flight persistence/reopen. Service tests cover touch auto-hide,
flight lock, battery extrema/faults, media seek/playback, storage faults,
deck/MCU/ADC/VRX health, receiver scan/favorites, telemetry loss/corruption,
PAL/NTSC validation, V4L2/file/simulator backend switching, capture loss/reconnect,
recorder-error isolation, and physical-input lockout.

Headless tests launch the complete QML graph in Home, Fly, Fly controls, flight
lock, Battery, Media, touch playback, Receiver, Flights, and Diagnostics states.
The QML suite also starts with an intentionally missing `/dev/video999` to prove
that capture absence does not crash the shell. Python tests cover numeric video-
node ordering and format discovery independently of physical devices.
An additional first-swapped-frame test exercises the schema-versioned benchmark
output and a Python test rejects incomplete/unknown metric records.
The screenshot script runs the same executable with deterministic data. A Python
source audit checks the manufacturer-verified critical ADS8688A and STM32 pad map
without requiring KiCad in CI. It does not replace schematic ERC or design review.
Another source check expands every grouped Test PCB BOM reference and quantity,
then compares the result with all footprints in the committed generated board.

The next layers are synthesized pointer/swipe and golden-diff tests, service
recovery integration tests, generated PAL/NTSC video pipeline assertions, DVR interruption tests,
and hardware-in-the-loop fixtures. Hardware tests must report measurements with
fixture version, firmware version, sample count, median, p95, minimum, maximum,
and environmental notes.

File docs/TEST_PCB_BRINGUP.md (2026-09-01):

# Test PCB Rev A bring-up

This procedure applies only after the PCB is marked released in its README and a
second engineer has checked the fab package. Use a non-conductive bench surface,
eye protection and a current-limited supply. Do not connect a LiPo during initial
bring-up.

The separate [balance ground-fault analysis](BALANCE_GROUND_FAULT_ANALYSIS.md)
controls any F2 population or reference-path experiment.

## Equipment

- current-limited 0–6 V bench supply and calibrated DMM;
- oscilloscope and 10× probe;
- ST-LINK/SWD cable and 3.3 V USB-UART;
- precision 0–25.5 V source or protected cumulative-tap simulator limited to 5 mA;
- thermocouple/thermal camera and ESD-safe tools.

## 1. Visual and records inspection

Confirm board revision, fab traveler, polarity marks, pin-1 marks, solder bridges,
connector keys, unpopulated DNP options and component labels. Verify J1 orientation
against the purchased JST drawing and harness using continuity mode only.

Confirm **F2 is not populated**. TP33 (`BNEG_RAW`) and TP34 (local ground) must
remain open-circuit except for ADC input leakage before an approved simulator
fixture intentionally provides a characterized link. Never bridge F2 with solder
or a zero-ohm resistor.

**Pass:** all exact MPNs and orientations match the released BOM/photos. **Fail:**
quarantine the board; do not “try power” to resolve ambiguity.

## 2. Unpowered resistance checks

Leave U1/U2 unpopulated for the first power-only assembly if hand building. Measure
5V_RAW-to-GND, 5V_FUSED-to-GND and 3V3-to-GND in both meter polarities after
capacitors settle. Record values rather than relying on a universal threshold.

Check each balance raw tap to ground. Expected nominal DC resistance is about
41 kΩ once its divider is assembled; adjacent channels should agree within the
network/measurement tolerance. Verify no continuity between adjacent J1 pins.

**Pass:** no hard short (<10 Ω) on a supply and divider channels are consistent.

## 3. Current-limited power-up

Set 5.0 V and 25 mA current limit with MCU/ADC absent. Connect J2 with polarity
verified at the board. Increase limit only after rail measurements are sensible.

Expected:

| Node | Pass band before calibration |
| --- | ---: |
| TP30 / 5V | 4.75–5.25 V |
| TP31 / 3V3 | 3.20–3.40 V |
| TP32 / GND | <5 mV to supply return |

No component should rise more than 10 °C above ambient unloaded. Fit MCU next,
then ADC, repeating the current-limited sequence each time and recording current.

## 4. Flash and communication

Connect SWD with target power off, reapply power at 100 mA limit, read the STM32
device ID, erase, program and verify. Do not disable SWD or readout until production.
Start watchdog/USB/UART firmware and run:

```bash
python3 tools/fpvdeck_hw_test.py --port /dev/ttyACM0
```

**Pass:** identify response version is correct, heartbeats continue for ten minutes,
CRC/error counters remain zero on a clean cable, and disconnect/reconnect recovers.

## 5. ADC identity and reference

Read ADS8688A default/reset behavior over SPI at conservative clock speed. Verify
REFIO and REFCAP against the datasheet's 4.096 V limits after the specified startup
time. Scope SCLK/CS/SDI/SDO and confirm levels stay within DVDD rails.

**Pass:** repeatable register readback, no ADC alarm, reference stable and no supply
overshoot. A plausible conversion alone is not proof of correct SPI framing.

Verify the logical channel identity before calibration: ADC0 = bipolar B− sense,
ADC1 = deck monitor, and ADC2–ADC7 = cumulative taps 1–6. A channel-order mismatch
is a hard fail; do not compensate by relabeling fixture wires.

## 6. Zero and cumulative voltage injection

With no LiPo present, short protected simulator inputs to balance reference and
record 1,000 samples per channel. Then inject 4.200, 8.400, 12.600, 16.800, 21.000
and 25.200 V cumulatively at a 5 mA current limit. Verify both raw test point and
ADC-node voltage; at 25.5 V the ADC node should be approximately 6.19 V.

Perform two-point calibration, repeat the sweep and calculate derived cells.

**Pass:** no ADC input exceeds 10.24 V; derived-cell error is ≤10 mV at room
temperature with p95 noise ≤5 mV. Store raw logs and calibration CRC.

## 7. Fault and connection tests

Using only the protected simulator, test every missing intermediate tap, adjacent
short, partial insertion order, disconnect, overvoltage up to the documented
fixture limit and ADC/MCU power removal. Verify stale data is never presented as a
healthy pack. Test USB-connected and standalone ground states.

The F2 experiment is a separate, reviewed test phase. Populate only after the
ground-fault matrix authorizes it, limit available energy, measure TP33−TP34,
and configure physical ADC channel 0 bipolar before interpreting B− sense.
Compare measured drop with total divider current; unexpected alternate return
current is an immediate fail and power-off condition.

Do not attempt reverse LiPo connection; test reverse fixture behavior with a
strict current limit and the approved fault-analysis procedure.

## 8. Controls, SD detect and outputs

Exercise every button/header input and verify one and only one event per press.
Insert/remove the SD-detect fixture, toggle LEDs/buzzer/fan, stall or disconnect
the fan, and confirm failure-safe off states after heartbeat loss.

## 9. VRX/decoder module interfaces

Before connecting modules, compare each cable pin-to-pin with the FpvDeck interface
table and the module's own documentation. Verify voltage and ground first. Inject
terminated CVBS and confirm it is not routed through an MCU pin. J4 and J5 have
only pin 2 ground and pin 3 CVBS assigned; all other pins are NC. Neither header
powers a module or claims RSSI/UART/enable. The current board has no routed copper,
so the exported placement cannot yet pass this test. After routing, validate the
breakout interactively with continuity and a terminated source/sink; firmware must
report it as `NOT TESTED` or `INTERACTIVE`, never an automatic VRX-link pass.

## 10. Thermal and endurance

Run ADC scanning, USB traffic, fan switching and simulator input for two hours.
Record rail voltage/current, MCU/ADC/LDO case temperature, ADC reference and error
once per minute. Repeat at intended ambient extremes only in controlled equipment.

**Pass:** no reset, CRC storm, thermal alarm, drift outside accuracy target or
component beyond its derated limit.

## Bring-up record

Record serial number, PCB revision, BOM lot, firmware Git SHA, instrument IDs,
calibration certificate dates, photos, all measurements, failures/rework and final
disposition. A board is not cleared for a real LiPo until the fault matrix and
accuracy sweep are signed off.

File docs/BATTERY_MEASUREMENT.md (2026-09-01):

# Balance-lead battery measurement

## Safety boundary

The external LiPo is a **measurement source only**. It never powers FpvDeck and
is electrically separate from the internal 2×18650 deck supply except for the
temporary measurement reference at the protected balance connector. No tap is
connected to an MCU ADC.

Test PCB Rev A targets keyed 1S–6S JST-XH balance leads. Eight-cell support is a
future requirement, not a Rev A claim.

## Selected Rev A architecture

| Element | Selection | Status |
| --- | --- | --- |
| Connector | JST `B7B-XH-A(LF)(SN)`, 7-way, 2.5 mm, top-entry through-hole | exact vendor drawing/footprint verification required before fabrication release |
| ADC | TI `ADS8688AIDBT`, TSSOP-38, 16-bit, eight-channel, SPI | **SELECTED**; active product, 0–10.24 V range used for taps |
| Divider network | Vishay `ACASA1002U1002P1AT`, four matched 10 kΩ elements, 0.1% absolute, 0.05% ratio, 5 ppm/°C ratio tracking | **SELECTED**; one array per cumulative tap |
| Series resistor | 1.00 kΩ, 0.1%, 25 ppm/°C, ahead of each matched network | exact BOM MPN to be footprint-checked |
| Filter | 10 nF C0G from ADC input to analog ground | selected value; settling/noise to validate |
| Ground protection | DNP Littelfuse `1206L010/60WR` footprint plus separate B− sense channel and paired probe points | **PROVISIONAL EXPERIMENT / OPEN DESIGN GATE**; not approved for a LiPo |

For each cumulative tap, three matched 10 kΩ array elements are placed in series
above the ADC node and one 10 kΩ element below it. A separate 1 kΩ resistor makes
the source-side path nominally 31 kΩ. The ADS8688A is configured for 0–10.24 V.
At a conservative 25.5 V six-cell maximum, the ADC input model predicts 6.192 V,
leaving 4.048 V of input-range headroom. Nominal divider current for the highest
tap is 0.622 mA.

The 31 kΩ series-side path is intentional: TI specifies its powered-off input
overvoltage condition differently above 30 kΩ. This does **not** by itself prove
all hot-plug or power-off cases safe; those remain fault-analysis tests.

## Pack-negative reference experiment

The six dividers require a return to pack negative, but directly joining pack
B− to digital/USB ground can create an uncontrolled fault path through the SBC,
bench supply, decoder, or another grounded instrument. Rev A therefore places:

- F2, a **DNP** `1206L010/60WR` PPTC candidate from `BNEG_RAW` to local ground;
- TP33 on `BNEG_RAW` and TP34 on local ground;
- R7, 1.00 kΩ from `BNEG_RAW` to `BNEG_SENSE`;
- ADC physical channel 0 on `BNEG_SENSE`, measuring B− relative to local ground.

This is test infrastructure, not a completed protection design. Littelfuse rates
the candidate at 0.10 A hold, 0.25 A trip and 60 V maximum. Its datasheet gives
0.5 Ω minimum initial resistance, 1.5 Ω typical initial resistance, and 10 Ω
maximum one hour after trip or reflow. Those values matter even in normal use.

At ideal 4.2 V cell increments, a simple 41 kΩ approximation gives:

```text
(4.2 + 8.4 + 12.6 + 16.8 + 21.0 + 25.2) V / 41 kΩ = 2.151 mA
```

The repository estimator also includes nominal ADS8688A input loading and reports
2.152796 mA, making local ground approximately 3.229 mV above B− at 1.5 Ω and
21.528 mV above B− at 10 Ω. The external `BNEG_RAW` node is consequently
negative relative to ADC ground. R7 and the ADS8688A input-bias network add a
calibratable pin-level error, so neither its sign nor magnitude may be assumed
from the PPTC drop alone. Physical ADC channel 0 must use a suitable bipolar
range. Firmware can measure the calibrated offset, but correction does not make
an unsafe ground path safe. The existing Monte Carlo result excludes this effect.

F2 remains unpopulated until a reviewed fault tree covers at least: USB attached,
earth-referenced oscilloscope, grounded lab supply, SBC and VRX ground paths,
board unpowered, ADC unpowered, partial balance-plug insertion, F2 open/high-R,
and a tap-to-ground short. Only a current-limited isolated simulator may be used
while this gate is open. A simple wire or zero-ohm substitute is prohibited.

## Measurement model

Balance taps are cumulative relative to pack negative. For a 4S pack:

```text
T1 = C1
T2 = C1 + C2
T3 = C1 + C2 + C3
T4 = C1 + C2 + C3 + C4
```

Software derives `C1=T1`, `C2=T2−T1`, and so forth. The implemented pure
function rejects non-monotonic taps, non-finite values, more than eight taps, and
derived cells outside a broad 0.5–5.0 V electrical sanity range. Chemistry
warnings are a separate policy.

## Accuracy budget

Target after per-channel two-point calibration:

- **required:** ±10 mV per derived cell from 0–50 °C;
- **stretch:** p95 ≤5 mV from −20–70 °C;
- quantization is not the dominant error; divider ratio and temperature drift are.

Run the source-controlled estimator with:

```bash
python3 tools/balance_frontend_error.py
```

Current seeded 20,000-case estimate:

| Metric | Estimate |
| --- | ---: |
| Tap absolute error p95 | 2.757 mV |
| Tap absolute error p99 | 4.259 mV |
| Derived-cell error p95 | 3.836 mV |
| Derived-cell error p99 | 6.187 mV |

The Monte Carlo model includes 0.1% initial resistance, 5 ppm/°C divider ratio
tracking, ADS8688A 0.85–1.15 MΩ input impedance and 25 ppm/°C maximum input
impedance drift, 4 ppm/°C maximum gain drift, quantization, offset drift, and
adjacent-channel subtraction. It assumes a 25 °C two-point calibration at 0 and
25.5 V. It does not yet include PCB leakage, humidity, thermoelectric effects,
connector resistance, RC dielectric absorption, reference long-term drift, or
ground-protection drop in its cell-error distribution. It does separately report
the nominal six-tap return current and reference drop at 1.5 Ω and 10 Ω so the
omission cannot be hidden. Therefore these are design estimates, not specifications.

The reviewed fault matrix and experiment stop conditions are maintained in
[BALANCE_GROUND_FAULT_ANALYSIS.md](BALANCE_GROUND_FAULT_ANALYSIS.md).

## Calibration

1. Warm the board for five minutes at room temperature.
2. Short each input at the protected simulator header to the local balance
   reference; record zero codes.
3. Apply a calibrated cumulative reference near 25.2 V through the bench adapter;
   record high codes. Never generate this from a real LiPo during calibration.
4. Store slope/intercept and board serial in MCU flash with CRC and calibration
   timestamp. Keep factory defaults separately recoverable.
5. Validate at 4.200, 8.400, 12.600, 16.800, 21.000 and 25.200 V, then calculate
   adjacent-channel cell error.

## Safe testing without a LiPo

Preferred method: a six-channel isolated battery-cell simulator or six isolated
bench outputs in series, current-limited to 5 mA. A lower-cost resistor ladder may
be driven from a current-limited 0–26 V supply, but it tests cumulative voltage,
not independently variable cells.

The current placed Rev A source does **not** claim a separate simulator connector.
Use a dedicated keyed, current-limited harness into J1, with no battery present,
and probe the raw/ADC test points. A future `BAL_SIM` connector is permitted only
after a backfeed analysis proves that it cannot coexist electrically with a real
pack. No fixture output may connect to a real battery; use conspicuous labels and
no gender arrangement that can be joined to a battery lead by mistake.

## Hot-plug and wiring behavior

- A keyed JST-XH housing reduces, but does not eliminate, partial insertion.
- Firmware does not declare a pack until cumulative taps are monotonic and stable
  for at least 100 ms.
- A missing intermediate tap produces `INVALID TAP ORDER` or `OPEN TAP`; it must
  not be silently interpreted as a lower cell count.
- The last valid measurement is marked stale immediately on disconnect and is
  removed from the FPV overlay after a short UI transition.
- The ground-protection implementation is still a release gate. Rev A has a DNP
  PPTC option and paired test points so ground offset and trip behavior can be
  characterized without pretending that the path is approved.

## Validation matrix

Test 1S–6S, no connector, every missing intermediate tap, adjacent short, reversed
test-fixture wiring, all connect/disconnect sequences, 0–4.35 V/cell, 25.5 V top
tap, ADC unpowered, MCU unpowered, USB attached, 50/60 Hz and converter noise,
ESD to enclosure, −20–70 °C, and calibrated source sweeps. Record raw codes as
well as filtered results. A fault must be reported without producing a plausible
but incorrect pack.

## Primary sources

- [TI ADS8688A product page](https://www.ti.com/product/ADS8688A)
- [TI ADS8688A datasheet](https://www.ti.com/lit/ds/symlink/ads8688a.pdf)
- [Vishay ACAS precision array datasheet](https://www.vishay.com/docs/28959/acas0612.pdf)
- [JST XH series](https://www.jst-mfg.com/product/index.php?series=277)
- [Littelfuse 1206L PPTC datasheet](https://www.littelfuse.com/assetdocs/littelfuse-ptc-1206l-datasheet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)

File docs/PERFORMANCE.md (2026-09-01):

# Performance and benchmark plan

| Workload | Metric | Initial gate | Instrumentation |
| --- | --- | ---: | --- |
| boot | power-good to first valid live frame | <8 s | MCU timestamp + photodiode |
| video | CVBS-in to photons | p95 ≤45 ms | dual photodiode/scope |
| video | capture/display continuity | source-rate, no app-caused stalls | frame sequence + DRM flips |
| overlay | input event to changed pixel | p95 <50 ms | MCU event + photodiode |
| UI | scene render rate | 60 Hz nominal | Qt frame timing |
| DVR | press to active status | <500 ms | monotonic trace |
| DVR | live latency delta while recording | <2 ms p95 delta | paired latency trials |
| VRX | channel request to stable lock | <500 ms target | RF/video fixture |
| services | idle resident memory | <350 MB CM4 target | cgroup/`smaps` |
| thermals | 60 min sun-equivalent steady state | no throttling at design ambient | thermocouples + SoC telemetry |
| power | typical FPV+DVR input | ≤16 W target | calibrated power analyzer |
| runtime | typical brightness, healthy two-cell 18650 pack | ≥1.25 h; 1.5 h stretch | coulomb/energy log |

Benchmarks report versions, build mode, backend, fixture, environment and full
distributions. Desktop simulator numbers are tracked for regressions but never
substituted for target hardware evidence.

## Desktop first-frame benchmark

Run:

```sh
./scripts/benchmark-ui
```

The Release build performs one excluded warm-up and three fresh-process runs of
Home, FPV, FPV controls, Battery, Media, playback, and Diagnostics under a
1280×720 Xvfb display. Each app writes schema-versioned JSON with QML-load time,
first swapped frame, resident memory, dimensions, state, and timeout status to
`generated/benchmarks/ui/`. The summary reports median and p95. Override sample
count with `FPVDECK_BENCHMARK_RUNS`; keep it at least three for comparisons.

This measures process start to first rendered frame on the development computer.
It does not measure touch-to-pixel response, steady-state frame pacing, decoded
video latency, CM4 startup, DRM/KMS, or physical display scanout. Those require
the trace/photodiode methods above. Do not compare results from different hosts,
Qt versions, render backends, or build modes without recording those differences.

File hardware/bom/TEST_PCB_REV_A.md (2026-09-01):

# Test PCB Rev A BOM

The machine-readable source is [TEST_PCB_REV_A.csv](TEST_PCB_REV_A.csv). It lists
every footprint currently generated on the board, exact non-commodity MPNs,
ratings, sources, alternatives, and assembly status.

Run `python3 tools/check_test_pcb_bom.py` after any board or BOM change. CI
expands grouped designators, verifies each declared quantity, and requires an
exact match with all 60 current board footprints. This checks completeness of
references, not component correctness, footprint geometry, stock, or safety.

## Cost snapshot

| Group | Approximate single-board cost |
| --- | ---: |
| ADC + MCU + LDO | US$30.25 |
| Six matched divider arrays | US$18.66 |
| connector-side resistors and filters | US$1.68 |
| reference/supply capacitors | US$2.05 |
| connectors, fuse and test points | US$15–20 |
| bare 4-layer PCB allowance | US$15–40 |
| **estimated assembled parts + PCB** | **US$83–113** |

Shipping, VAT, assembly, spare parts and debug equipment are excluded. Buy at
least two ADCs/MCUs and ten divider arrays if hand assembling.

## Important status distinction

- `Required` means the component belongs on the current electrical architecture.
- `Optional` means the feature can be omitted during initial assembly.
- `DNP` means the footprint is an unapproved experiment and must remain empty
  unless the associated fault-analysis procedure explicitly authorizes it. F2 is
  such a part; including it in the BOM is not approval to join a LiPo to the board.
- `WAIT` means **do not order yet**. The bare PCB remains `WAIT` until the board
  release gates in its README close.

The BOM does not convert an unrouted board into a manufacturing release. Exact
footprint and lifecycle information must be refreshed at purchase.

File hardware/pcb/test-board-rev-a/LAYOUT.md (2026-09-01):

# Test PCB Rev A layout

> **PRE-RELEASE VIEW — NOT FOR FABRICATION.** The board is placed and net-assigned
> but has no routed tracks or planes. The views below communicate architecture;
> they do not prove connectivity, signal integrity, clearance, or manufacturability.

## Inspection views

- [Top copper/silkscreen view](exports/test-board-rev-a-top.svg)
- [Bottom copper/silkscreen view](exports/test-board-rev-a-bottom.svg)
- [Component-map view](exports/test-board-rev-a-component-map.svg)

## Functional zones

| Area | Contents | Purpose |
| --- | --- | --- |
| Left | J1, RN1–RN6, R1–R6, C1–C6, TP1–TP25 | protected external-pack input, cumulative-tap dividers, raw and ADC probing |
| Centre | U1 ADS8688A, U2 STM32G0B1, local decoupling | precision conversion and real-time control |
| Lower | J2 bench input, F1/D1/U3, rail LEDs/test points | current-limited bench power and 3.3 V generation |
| Right | J3 SBC, J4 VRX CVBS, J5 decoder CVBS, J6 expansion/debug | modular low-speed and analog handoff interfaces |

The 5.8 GHz RF receiver, decoder EVM, CM4 IO board, and touchscreen are external
modules. RF, MIPI CSI-2, and MIPI DSI are deliberately absent from Rev A.

## Video handoff intent

```text
5.8 GHz antennas
       │ 50 Ω RF
       ▼
Skyzone SteadyView X (separately powered, documented 6.5–26 V input)
       │ documented 3.5 mm A/V output; cable contact map must be verified
       │ 75 Ω CVBS
       ▼
J4 VRX CVBS ONLY: pin 2 GND, pin 3 VRX_VIDEO, all other pins NC
       │ board net intent only — no routed copper in this revision artifact
       ▼
J5 DECODER CVBS ONLY: pin 2 GND, pin 3 VRX_VIDEO, all other pins NC
       │ short shielded 75 Ω connection; decoder provides its specified termination
       ▼
ADV7282A-M evaluation hardware (separately powered)
       │ MIPI CSI-2 over SMA — reviewed controlled-impedance bridge still required
       ▼
CM4 IO Board → DSI → HD capacitive touchscreen
```

J4/J5 provide neither module power nor channel control. No SteadyView X RSSI,
serial, enable, or internal pinout is assumed. The Test PCB also does not add a
75 Ω terminator; the actual decoder input and cabling must implement the decoder
manufacturer's reference circuit. Until routing, J4 and J5 are placement/net
intent—not a functioning CVBS path.

## Placement rules for routing

- Route `VRX_VIDEO` as a short, ground-referenced 75 Ω path only after the chosen
  stack-up and decoder termination are known. Prefer coax for the modular bench.
- Keep the balance-input section away from switching nodes, USB, MIPI, and RF.
- Give every cumulative tap and ADC input a probeable point without long stubs.
- Keep the ADS8688A analog return continuous and separate from switcher hot loops.
- Preserve access to SWD, UART, rail, pack-return, fan, and shutdown test points.

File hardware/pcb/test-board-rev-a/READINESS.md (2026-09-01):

# Test PCB Rev A release readiness

**State: NOT RELEASED / DO NOT FABRICATE / DO NOT CONNECT A LIPO**

The repository currently contains a deterministic 120 × 90 mm, four-layer,
60-footprint placement with named nets and inspection exports. It contains zero
routed tracks. This is meaningful design progress, not a manufacturing package.

| Gate | State | Required evidence |
| --- | --- | --- |
| Requirements and modular partition | PASS | documented blocks, test access, RF/MIPI kept off-board |
| Exact BOM ↔ footprint coverage | PASS (automated) | `tools/check_test_pcb_bom.py` covers all 60 footprints |
| J4/J5 interface safety | PASS for net intent | only pin 2 GND and pin 3 CVBS; all assumed power/control removed |
| Native schematic and ERC | OPEN | reviewed `.kicad_sch`, zero unexplained ERC findings |
| ADC/MCU pad-map second-person audit | OPEN | signed datasheet/package checklist |
| ACAS array element/pad validation | OPEN | drawing review plus sample continuity evidence |
| Pack-negative fault safety | OPEN / SAFETY | close fault tree and isolated current-limited tests; F2 stays DNP |
| Power/ground/analog routing | OPEN | routed board, planes, impedance/current calculations |
| DRC and netlist comparison | OPEN | clean reports stored with release artifact |
| Exact connector/footprint fit | OPEN | 1:1 print and purchased-component fit log |
| Bring-up firmware on target MCU | OPEN | Nucleo first, then board SWD/CLI/self-test evidence |
| Independent release review | OPEN | signed checklist and tagged fabrication release |

## Video compatibility gate

The standalone SteadyView X specifications establish a credible RF-to-CVBS
stage, but the complete chain is not purchase-cleared. `EVAL-ADV7282AMEBZ` exposes
MIPI CSI-2 on SMA connectors, current distributor availability is restricted, and
the controlled-impedance SMA-to-CM4IO bridge is not designed. Therefore:

- dedicated 5.8 GHz VRX: `WAIT — CHAIN GATE`;
- decoder EVM: `WAIT — STOCK + BRIDGE GATE`;
- bare Test PCB and assembly: `WAIT — PCB RELEASE GATES`.

Compute, CM4IO, touchscreen, MCU development board, and general debugging tools
are independently useful and may be bought under `hardware/BUY_NOW.md`.

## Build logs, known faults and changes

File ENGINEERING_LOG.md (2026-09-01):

# Engineering log

This is the durable chronological record for decisions, evidence, experiments,
and unresolved facts. Status labels are used deliberately:

- **CONFIRMED** — supported by a primary source or a repeatable test.
- **LIKELY** — supported by indirect evidence; verify before depending on it.
- **UNKNOWN** — no defensible evidence yet.
- **NEEDS MEASUREMENT** — must be established on the physical unit or bench.

## 2026-08-31 — Repository bootstrap

- The supplied repository directory was empty and was not a Git repository.
- Temporary product codename: **OpenPocket**. The application platform is
  **FPVDeck**. Other candidates retained for later consideration: FieldView,
  VectorDeck, and PilotGlass.
- Selected Qt 6 + QML for the first desktop application. Qt gives a direct
  embedded-Linux path, a scene graph suited to composited overlays, hardware
  input support, SQLite integration, and a C++ escape hatch for zero-copy video.
- The desktop milestone uses C++ services behind QObject interfaces and QML for
  presentation. Simulation is a backend selection, not a separate application.
- **CONFIRMED:** Raspberry Pi documents ADV728x-M CSI-2 bridge support through
  the `adv7180` V4L2 driver, with no interlaced capture support. An ADV7280/7282
  variant with the low-delay I2P block and the `-M` CSI output is required.
- **CONFIRMED:** Analog Devices states the ADV728x I2P is line based rather than
  frame buffered. This is lower latency but trades away motion-adaptive quality.
- **CONFIRMED:** ADV7280A is marked not recommended for new designs. It is a
  prototype-enabling choice, not yet the production decoder.
- **CONFIRMED:** Renesas TW9992 is active, supports NTSC/PAL, CSI-2 YUV422 or
  RGB565 output, and is specified at 100 mW typical. Mainline/Raspberry Pi driver
  support has not been confirmed and is the primary integration risk.
- **CONFIRMED:** CM4 exposes CSI and DSI, has H.264 1080p30 encode, and has a
  stated production lifetime through at least January 2034. This makes it the
  Prototype 1 compute choice despite newer CM5 CPU performance.
- **CONFIRMED:** NXP i.MX 8M Plus has dual CSI, DSI, a 2D/3D GPU, and H.264/H.265
  encode to 1080p60. It remains the leading production-oriented SoM family,
  subject to decoder compatibility and measured end-to-end latency.
- **CONFIRMED:** RadioMaster's current T8L documentation specifies two 18650
  cells, 6.0–8.4 V input, 100 mW maximum 2.4 GHz ELRS, USB-C charging/update/
  simulator support, and Hall gimbals. Schematics, board dimensions, internal
  connector pinout, CRSF access, and cell topology are **UNKNOWN**.
- **LIKELY:** keeping the donor mainboard intact is the least risky V1 RF plan.
  No T8L signal will be tapped until the reverse-engineering procedure has been
  completed.
- **CONFIRMED:** Skyzone SteadyView X publishes -98 dBm ±1 dB sensitivity,
  dual-antenna mix/diversity modes, 1 Vpp/75 ohm CVBS output, and a ground-station
  kit. It is the Prototype 1 VRX lead because its standalone output is explicit.
  Its fusion latency and weak-signal behavior are **NEEDS MEASUREMENT**.
- **CONFIRMED:** TBS Fusion publishes -96 dBm, 5 V/340 mA, active video fusion,
  and a UART protocol, but the manufacturer currently lists it out of stock due
  to a filter-component shortage. Retain as an A/B benchmark, not the baseline.
- **CONFIRMED:** Winstar WF50DSYA3MNN0 is a 5-inch, 720×1280, 4-lane MIPI DSI,
  IPS panel with 1100 cd/m² typical luminance. It leads the production display
  shortlist, but needs a verified Linux panel initialization sequence and a
  physical latency/sample-availability check.
- Prototype display lead: Raspberry Pi Touch Display 2 (5 inch) or Waveshare
  5-inch DSI (D), both 720×1280 and already supported on Raspberry Pi. Brightness
  and display scanout latency remain **NEEDS MEASUREMENT**.

## Decision gates

1. No manufacturing release may use an unverified footprint, pinout, register
   script, or electrical rating.
2. Decoder, VRX fusion mode, and display choices remain provisional until the
   high-speed-camera/photodiode latency fixture produces distributions, not just
   a single best-case observation.
3. The flight-control path is independent of Linux. Linux failure must not stop
   the T8L/ELRS control link.

## 2026-08-31 — Desktop vertical slice and staged hardware baseline

- Installed the Linux Qt 6/CMake/Ninja/FFmpeg/GStreamer build prerequisites and
  recorded the reproducible package list in `docs/BUILD.md` and CI.
- Implemented a Qt Quick shell with FPV, Battery, Flights, DVR, Aircraft, Settings,
  and development Simulator screens. `scripts/generate-test-video` creates a
  copyright-free 720×576/50 synthetic stream containing pseudo quad-OSD pixels;
  colored FPVDeck widgets are a separate QML scene layer.
- **VERIFIED:** the application builds and plays the generated video under an X11
  virtual display. A captured frame shows both in-video OSD and independent
  translucent receiver/telemetry/system/battery overlays.
- Added simulated Battery, Video/VRX, Telemetry, Input, and DVR services. Faults
  include signal loss/weak/roll/black, PAL/NTSC, telemetry loss/corruption/version,
  1S–6S pack/imbalance/under/over/disconnect/bad taps, and storage-full.
- Added SQLite schema migrations for aircraft, batteries, flights, telemetry,
  recordings and battery observations. WAL, foreign keys and FULL synchronous
  mode are enabled. Migration/reopen persistence is tested.
- Implemented matching allocation-free C firmware and C++ Linux codecs for the
  v1 COBS + CRC-16/CCITT frame. Payload layouts intentionally remain unfrozen.
- Local CI-equivalent result: 6/6 tests pass (battery math, C++ protocol, database,
  services, QML smoke, MCU C protocol).
- Created two empty KiCad project containers. No schematic was fabricated from
  uncertain interfaces; capture is gated on EVM and T8L measurements.
- Prototype 1 component lead set: CM4, Pi-supported DSI panel, ADV728x-M EVM,
  SteadyView X, STM32G0B1 devboard, ADS7066/ADS8688A EVM comparison, BQ25792 and
  TPS55288 evaluation boards. These remain measurement-gated decisions.

## 2026-09-01 — Canonical identity, showcase, and display ergonomics

- **CONFIRMED:** the canonical project/repository name is **FpvDeck** and the Git
  remote is `git@github.com:wiekstras/FpvDeck.git`. The existing local `main`
  history was preserved. `origin` had no branch heads when inspected; no history
  rewrite or force push was performed.
- Replaced the temporary OpenPocket-facing identity with FpvDeck in build metadata,
  application metadata, architecture prose, license attribution, and repository
  presentation. The existing MIT license text was preserved.
- Added deterministic Home, FPV, Balance, Media, Flights, and Diagnostics showcase
  states. `scripts/screenshot-demo` launches the actual Qt/QML application under
  Xvfb with synthetic video and in-memory SQLite, producing the committed 1280×720
  captures. Static Media/Batteries records remain explicitly labeled simulated;
  they are not claimed as completed persistence or storage backends.
- Added editable SVG branding, Mermaid architecture sources, a rendered system
  diagram, repository issue/PR templates, contribution/security guidance, and a
  status-accurate README.
- Product direction changed after ergonomics review: the screen should be larger
  and high-mounted, with both gimbal finger envelopes clear for pinch grip. The
  target range is now 5.5–6.25 inches. The Waveshare 6.25-inch 720×1560 DSI module
  is a larger bench candidate; its brightness, landscape scan direction, power,
  fit, and latency are **UNKNOWN / NEEDS MEASUREMENT**. The supported 5-inch Pi
  panel remains a bring-up fallback, not the desired final size.
- Generated two industrial-design images with the built-in image-generation tool.
  Version 2 enlarges and raises the screen, lowers/separates the gimbals, and adds
  palm support and pinch clearance. Both are labeled **CONCEPT RENDER** and are
  explicitly prohibited as dimensional/PCB inputs in `docs/assets/renders/README.md`.
- **VERIFIED:** the first canonical GitHub Actions run passed, including all 12
  tests and required-document checks. Its Node 20 deprecation annotation prompted
  an upgrade to official `actions/checkout@v6` and `actions/cache@v5`, both using
  the Node 24 action runtime on current GitHub-hosted runners.

## 2026-09-01 — Touchscreen vertical slice and Test PCB Rev A pre-release

- Touch is now a hard product requirement. The simulator was converted to a
  touchscreen-first interaction model with reusable QML components, minimum
  field-friendly targets, FPV tap-to-reveal controls, timed auto-hide, deliberate
  flight lock, a detailed external-battery card, touch media playback, receiver
  scan/favorites, and a development touch indicator. Physical/keyboard paths
  remain available for critical functions.
- Added separate `InteractionService`, `StorageService`, `MediaService`, and
  `SystemService` interfaces. Simulation covers SD removal/corruption/full,
  MCU/ADC/VRX loss, over-temperature, deck drain/charging, touch, media playback,
  and video/receiver faults. Diagnostics exposes those states without coupling
  the UI directly to hardware code.
- **VERIFIED:** the expanded local suite has 18 passing tests, including all
  deterministic application states, service fault/state behavior, the MCU frame
  codec, board-command dispatch, and host hardware-test tool.
- **CONFIRMED:** Waveshare currently documents `6.25inch DSI LCD (B)`, SKU 35000,
  as a 720×1560 IPS module with 500 cd/m² luminance, 178-degree viewing, up to
  60 Hz, five-point capacitive touch, I2C touch, optical bonding, and a
  74.70×159.18 mm cover. It is selected for Prototype 1 because the user requires
  a larger screen and pinch-grip geometry. Module latency, landscape scan,
  sunlight performance, thermal behavior, glove behavior, and actual fit are
  **NEEDS MEASUREMENT**; it is not a production-panel freeze.
- CM4 remains the Prototype 1 compute choice because the selected module has a
  documented CM4 DSI connection, ADV728x-M has a documented Raspberry Pi capture
  path, and CM4 provides an H.264 encoder. This is an evaluation convenience
  decision, not proof that CM4 is the production SoM.
- Selected ADS8688A for Test PCB Rev A: eight protected 16-bit channels and a
  0–10.24 V input range allow all six cumulative balance taps, pack-negative
  sense, and deck monitoring without per-channel op amps. The exact resistor
  network is Vishay `ACASA1002U1002P1AT`; three matched 10 kΩ elements form the
  top leg and one forms the bottom leg, followed by a separate 1 kΩ input
  resistor. All values remain subject to physical calibration and review.
- **VERIFIED BY MODEL, NOT HARDWARE:** a seeded 20,000-sample Monte Carlo across
  -20 to 70 °C after two-point calibration produced 2.76 mV tap p95 and 3.84 mV
  derived-cell p95; p99 was 4.26/6.19 mV. This model includes documented ADC
  gain/offset/input-impedance drift, ratio tracking, quantization, and calibration
  uncertainty. It is not a guaranteed accuracy specification.
- Created Test PCB Rev A as a real KiCad project and generated a 120×90 mm placed,
  net-assigned, **unrouted** board containing exact lead packages, six divider
  arrays, ADS8688A, STM32G0B1CBT6, power protection/regulation, test points, and
  modular SBC/VRX/decoder/debug headers. PDF, Gerber, and drill export succeed.
  The design is explicitly **NOT RELEASED FOR FABRICATION** until a native
  schematic/ERC, ground-reference protection, independent pad-map audit, routing,
  DRC, 1:1 footprint check, and design review are complete.
- A primary-datasheet audit before release found the initial generator had
  misassigned ADS8688A channel 2/4/5 and AVDD pads. Because the board was unrouted
  and explicitly gated, no released hardware was affected. The DBT mapping was
  corrected to channel-positive pads 16/18/21/23/25/27, AVDD pads 9/30, and the
  paired ground pins. CI now parses and verifies the critical ADC and MCU mapping.
- High-speed MIPI/DSI/CSI and RF circuitry stay off Test PCB Rev A. Decoder EVM,
  display, CM4 IO board, and VRX remain replaceable modules, reducing Rev A risk.
- Added a host-tested MCU board-command subset and `tools/fpvdeck_hw_test.py`.
  It can run deterministically with `--simulate` now and will use a POSIX serial
  port when HAL firmware exists. It reports identity, MCU/ADC state, six balance
  channels, storage detect, temperature, and VRX communication.
- Created exact-MPN Test PCB and system BOMs plus procurement staging. The bare
  PCB and unresolved EVM/adaptor connections are in **WAIT**, preventing an
  apparently complete shopping list from becoming an unsafe fabrication order.
- Post-procurement audit corrected the decoder evaluation-board assumption. ADI's
  `EVAL-ADV7282AMEBZ` exposes the CSI clock/data pairs on SMA connectors for a
  MIPI analyzer, not a Pi FFC. Raspberry Pi tested the older, software-compatible
  `EVAL-ADV7282MEBZ`; ADI marks the silicon family NRND. The current A-M kit is now
  a **VERIFY STOCK AND BRIDGE** item, with a separate controlled-impedance
  SMA-to-CM4IO fixture required before purchase/use. Production remains TW9992
  research rather than an ADV728x lifecycle commitment.

## 2026-09-01 — Provisional pack-reference test path

- The placed Rev A design correctly kept `BNEG_RAW` separate from local ground,
  but that also left the six cumulative-tap dividers without a completed battery
  return. A direct copper bond was rejected because USB, grounded test equipment,
  the SBC, and other modules can form alternate fault-current paths.
- Added F2 as a **DNP-only** Littelfuse `1206L010/60WR` candidate between
  `BNEG_RAW` and local ground, plus TP33/TP34 on both sides. The exact part is
  manufacturer-rated 0.10 A hold, 0.25 A trip and 60 V maximum; the manufacturer
  lists 0.5 Ω minimum initial, 1.5 Ω typical initial, and 10 Ω maximum
  resistance after trip/reflow. Its generic KiCad land pattern is still subject
  to exact drawing review.
- Six ideal 4.2 V/cell divider channels draw 2.151 mA total. That produces about
  3.23 mV typical and as much as 21.5 mV at the published post-trip/reflow maximum
  between pack B− and local ground. Physical ADC channel 0 can observe the
  `BNEG_SENSE` offset only when configured for a suitable bipolar range.
- **OPEN / SAFETY GATE:** F2 is not approval for real-LiPo use. Fault-tree review
  and current-limited isolated-simulator tests must cover all externally grounded
  states, partial insertion, powered-off behavior, and alternate return paths.
- Extended `tools/balance_frontend_error.py` with the nominal ADC-loaded return
  calculation. The deterministic result is 2.152796 mA for six 4.2 V cumulative
  taps, 3.229194 mV at 1.5 Ω and 21.527959 mV at 10 Ω. Tests lock these values.
- Added `docs/BALANCE_GROUND_FAULT_ANALYSIS.md` with explicit current-path,
  energy-limit, abort-condition and evidence requirements for unpowered, USB,
  earthed-instrument, partial-insertion, open/high-R F2 and tap-fault states.
  Production B− correction is a requirement, not an implemented claim.

## 2026-09-01 — Reproducible desktop first-frame benchmark

- Added `--benchmark-json` to the real Qt application. It records a versioned
  first-frame record containing QML-load time, first swapped frame, RSS, screen
  geometry, demo state and timeout status, then exits. CI exercises this path.
- Added `scripts/benchmark-ui`, including an excluded cache warm-up, repeated
  fresh processes and median/p95 aggregation. The raw JSON remains generated
  output rather than a source-controlled performance claim.
- **MEASURED ON THIS DEVELOPMENT CONTAINER ONLY:** three-sample Release/Xvfb
  first-frame medians ranged from 655 ms (Media playback) to 892 ms (FPV controls);
  p95 ranged from 704 to 1,034 ms and median RSS was roughly 282–285 MiB. These
  numbers are a regression baseline, not CM4 boot, touch latency, frame pacing,
  video latency, or physical-display evidence.
- The automated suite now has 19 tests, including the benchmark first-frame path
  and schema validation. All passed locally after this change.

## 2026-09-01 — ADC logical-channel correction

- Cross-checking firmware against the audited ADS8688A board map found a
  pre-hardware defect: `TAP_DUMP` iterated ADC0–ADC5 even though ADC0 is B− sense,
  ADC1 is deck monitor, and cumulative taps occupy ADC2–ADC7. The host tool also
  mislabeled its six individual ADC requests as balance channels.
- Added the explicit `fpvdeck_adc_channel_t` map. Firmware now reads ADC2–ADC7
  for `TAP_DUMP`; the Linux tool separately reports signed B− offset and deck
  monitoring, then consumes the ordered six-tap dump. Host and C dispatcher tests
  lock the map. No released hardware was affected.
- Added `tools/check_test_pcb_bom.py`: it expands CSV ranges, rejects duplicate or
  inconsistent quantities, and compares the BOM with every generated KiCad
  footprint without needing KiCad in CI. The then-current BOM covered 59 board
  footprints (with `PCB1` explicitly treated as the one non-footprint line).
- A subsequent net audit found `BNEG_RAW` and the ADC's `BNEG_SENSE` net had no
  component joining them. Added R7, an explicit 1.00 kΩ sense-path resistor,
  regenerated the deterministic board, and expanded the BOM to all 60 footprints.
  The input-bias/calibration term and fault behavior remain release-gated.

## 2026-09-01 — Corrected donor/video boundary and EU procurement gate

- Completed a repository-wide audit of T8L, ELRS, receiver, VRX, 5.8 GHz, CVBS,
  and decoder references. The canonical boundary is now explicit everywhere:
  **T8L = 2.4 GHz ELRS control donor; dedicated FpvDeck VRX = 5.8 GHz RF to
  CVBS; separate decoder = CVBS to digital; SBC = video/apps/overlay; HD panel =
  display/touch; external balance port = measurement only; donor 2×18650 =
  provisional internal source; removable SD = goggle/DVR media.**
- Found and removed an unsafe hardware assumption. Rev A J4 had implied 5 V,
  RSSI and UART for an undocumented commercial VRX, while J5 implied power/I²C/
  reset for a decoder. Both headers now assign only project pins 2=GND and
  3=CVBS; pins 1/4/5/6 are NC. Receiver and decoder keep their own documented
  power/control connections. Automated source tests prohibit the removed nets.
- **CONFIRMED:** Skyzone's current 5.8G SteadyView X documentation specifies
  5.3–6 GHz/48 channels, −98 dBm ±1 dB, two standard SMA-K 50 Ω inputs,
  mix/diversity/single modes, 1.0 Vp-p typical into 75 Ω, 6.5–26 V input, and
  12 V×240 mA normal/180 mA single operation. Its current ground-station kits
  include the XT60/barrel power lead, 3.5 mm video cable, RHCP patch and omni.
  The 3.5 mm conductor map, host control/RSSI API and fusion latency remain
  **UNKNOWN / NEEDS MEASUREMENT**.
- Located two actual EU receiver offers at the research snapshot: La Caméra
  Embarquée (France, €219 shown before tax, in stock) and Baltic Drones
  (Lithuania, €250.23 tax included, in stock). This validates EU availability,
  not end-to-end compatibility.
- The receiver remains `WAIT`, not `BUY NOW`. Although RF→CVBS is credible,
  `EVAL-ADV7282AMEBZ` exposes MIPI CSI-2 on SMA and direct Mouser inspection
  reported restricted availability. No reviewed controlled-impedance
  SMA-to-CM4IO bridge exists. An earlier cached Mouser result conflicted with the
  direct page, so only checkout-time direct stock is accepted.
- Purchase-cleared independent items are CM4104032, CM4IO, Waveshare 6.25-inch
  DSI LCD B SKU 35000, adapter/supply, NUCLEO-G0B1RE, ST-LINK, Transcend RDF5
  removable-media reader, and a 128 GB High Endurance test card. The snapshot
  subtotal is €353.24 before shipping; a 10% small-adapter contingency makes
  €388.56. Full gated bench architecture including video, a released Test PCB
  and fixtures is budgeted at €1,280–1,920, excluding lab instruments.
- Generated and committed top/bottom/component views for the 120×90 mm four-layer
  board, plus layout, component-map, staged-build, and readiness documents. The
  board still has **60 footprints and zero routed tracks**. Exports are inspection
  views, not fabrication outputs; PCB fabrication and real-LiPo connection remain
  prohibited.
- Corrected self-test semantics: Rev A cannot automatically test a VRX link
  because it exposes only a passive CVBS handoff. Protocol bit 5 is now named
  `CVBS_BREAKOUT`; simulated/real tooling reports it `INTERACTIVE` or `NOT TESTED`
  until a continuity/terminated-video fixture supplies evidence.
- Simulator Diagnostics now displays separate T8L control, ELRS TX 2.4 GHz,
  5.8 GHz video VRX, CVBS decoder and digital-video states. Independent T8L,
  ELRS, VRX and decoder fault injection is service-tested. A follow-up software
  boundary audit moved channel, RSSI, favorites and scanning out of `VideoService`
  into a dedicated `RadioService`; video standard/capture state remains separate.
- **VERIFIED:** documentation gates, 60-footprint BOM check, four Test PCB source
  safety tests, firmware/tool self-test behavior, complete C/C++/QML build, and
  all 19 CTest entries passed locally after the correction. The deterministic
  diagnostics showcase was regenerated from the actual application.

## 2026-09-01 — Prototype 0 reference hardware frozen

- Project priority changed from final hardware optimization to the shortest safe
  path to real Air65 video. The desktop simulator is now described as pre-hardware;
  **Prototype 0 is a functionality bench**, Prototype 1 is the direct-decoder
  latency bench, Prototype 2 is modular custom hardware and Prototype 3 is the
  integrated product.
- Selected **Raspberry Pi 5 2 GB** for the bench. Current simulator RSS is roughly
  285 MiB, so 2 GB is sufficient; Pi 5 adds useful decode/compositor margin for a
  small premium over Pi 4 2 GB. This does not change the production SoM decision.
- Selected **Raspberry Pi Touch Display 2 5-inch, MPN SC1975**. Kiwi's Dutch page
  showed €36.49 before VAT and immediate stock. Raspberry Pi documentation
  confirms 720×1280, five-point capacitive DSI touch, supplied Pi 5 22-to-15-way
  FFC, GPIO power lead, Pi GPIO pins 2/6, and Pi 5 support. It is intentionally
  cheap Prototype 0 hardware; the larger pinch-grip display direction remains.
- Selected the Rotorama **RC832 Mini** kit for Prototype 0 only. Vendor/manual
  evidence confirms 56 A/B/E/F/R/L/X channels, RP-SMA, 12 V/130 mA, 3.5 mm AV,
  PAL/NTSC 1.0 Vp-p into 75 Ω, and included receiver/linear antenna/power/video
  leads. Rotorama showed €55.49 in stock and documents EU delivery, including
  €6.49 GLS to Holland. OEM identity, barrel dimension/polarity and AV conductor
  map remain unknown; the build uses supplied leads and requires continuity checks.
- Selected **Gembird UVG-002** after the final Netherlands delivery audit rejected
  USB-Live2 as tonight's primary: its identified offers were either long-lead or
  not demonstrably deliverable to the Netherlands. Informatique showed UVG-002 at
  €12.95 including VAT/in stock; bol showed €19.70 delivered/in stock. Gembird
  specifies composite/S-Video, PAL 720×576/25, NTSC 720×480/30 and UTV007 or
  UTVF007 silicon. A deeper gate found two Linux paths: UTV007 uses `usbtv`;
  UTVF007 commonly enumerates as UVC `534d:0021` and uses `uvcvideo`. The latter
  is reported to squelch weak/noisy input, so it can prove functionality but not
  final FPV weak-signal quality. The exact received ID/formats remain a receipt
  gate; Hauppauge remains the known-identity fallback if neither path appears.
- Added a separate protected 12 V/1 A PCEnergy supply and centre-positive female
  barrel-to-terminal adapter. High-resolution vendor imagery showed that the
  supplied receiver power cable is barrel-to-red-two-pole, not bare wire. A final
  procurement audit rejected relying on RCY/BEC identification: the connector
  family is unpublished and direct Dutch pigtail listings were insufficiently
  verifiable. Prototype 0 instead removes that connector from the **replaceable
  supplied accessory lead**, continuity-maps its barrel, and lands the stripped
  conductors in the marked terminal adapter. Pi and VRX use separate wall
  supplies; receiver and T8L remain untouched.
- `hardware/PROTOTYPE_0_BUY_TONIGHT.md` totals the reference chain at roughly
  €246.47 including VAT plus €23–€35 multi-shop shipping, including a meter and
  cutter/stripper for a complete safe bring-up path. It excludes CM4,
  premium screen, ADV728x EVM, Test PCB, battery frontend, enclosure and duplicate
  ELRS hardware.

## 2026-09-01 — Real capture software path

- `VideoService` now distinguishes `simulated`, `file` and `v4l2` backends and
  publishes device identity/availability without coupling receiver channel state
  back into video. `--video-device /dev/videoN` selects an exact Qt `QCamera`;
  an unavailable device produces a visible lost state instead of application exit.
- The FPV page selects the QCamera capture session or existing MediaPlayer behind
  the same VideoOutput/overlay graph. A QMediaRecorder tee records the live camera
  before QML overlays to timestamped MP4 files. Recorder errors stop/report DVR
  without modifying VideoService; real codec/container behavior awaits Pi hardware.
- Added `fpvdeck-video-list`, `test-video`, `prototype0` and `setup-pi`. Raw video
  validation is deliberately independent of the full application. `prototype0`
  falls back to generated video when no capture device exists, retaining software
  usability before parts arrive.
- Diagnostics now reports the capture backend/device separately, and developer
  touch-trace mode adds video FPS, process CPU/RSS and temperature. Dropped-frame
  and electrical capture-latency values remain `—` until real driver/fixture data
  exists; the UI does not fabricate them.
- Added backend switching/reconnect, missing `/dev/video999`, recorder error and
  numeric V4L2 node/format discovery tests. The CI-equivalent suite increased
  from 19 to 20 CTest entries and passed locally after implementation.
- Device auto-selection now ignores metadata-only `/dev/video*` nodes and prefers
  a formatted node named `usbtv`. Raw bring-up and the launcher accept an
  explicit driver-reported composite input index; no input number is guessed.
- The live Qt camera watches `videoInputsChanged`: removal marks capture lost and
  reconnection at the requested path reconfigures/restarts the same camera object.
- Closed the owned-aircraft procurement ambiguity: if no serviceable BT2.0 1S
  LiHV pack/charger is already present, the buy-tonight document names a verified
  in-stock LAVA 260 mAh five-pack and VIFLY WhoopStor V3 as conditional additions.
  They are not duplicate purchases for an already complete Air65 kit.
- Final electrical-safety audit found that Rotorama's one-page Mini manual omits
  DC-jack polarity even though vendor imagery shows a factory red/black barrel
  lead. Wiring now permits first power only when factory red maps to centre and
  black maps to sleeve by continuity; an unmarked or contradictory received lead
  requires written vendor confirmation. No trial polarity is allowed.
- New DVR sessions now reset elapsed time. A first full test run exposed an
  intermittent missing-device multimedia teardown timeout; detaching QCamera,
  VideoOutput and MediaRecorder from CaptureSession while capture is unavailable
  removed that unnecessary backend path. The complete suite then passed cleanly.
- Re-ran shell syntax, installer dry-run, four Python V4L2 selection tests,
  whitespace and documentation checks, complete C/C++/QML build, all 20 CTest
  entries, and the 60-footprint Test PCB/BOM consistency check successfully.

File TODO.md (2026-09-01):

# Engineering TODO

Items remain here until completed and evidenced by a test, document, or artifact.

## Prototype 0 — real Air65 video on the bench

- [x] Freeze one complete reference chain: Pi 5 2 GB, 5-inch Touch Display 2,
  RC832 Mini kit, Gembird UVG-002, separate approved supplies and storage.
- [x] Publish a short VAT-aware, link-verified Netherlands/EU buy-tonight list,
  exact block diagram, pin/cable wiring and from-parts-arrival setup guide.
- [x] Add Linux V4L2 device/format discovery and independent bounded raw-video
  test/preview tooling.
- [x] Add selectable simulated/file/V4L2 VideoService modes, missing-device-safe
  startup, real QCamera display path and backend/reconnect tests.
- [x] Add a Prototype 0 launch command with real-capture selection and simulated
  fallback, plus an idempotent Raspberry Pi OS dependency installer.
- [x] Add pre-overlay QMediaRecorder capture for the live V4L2 branch and isolate
  recorder errors from the video/application process.
- [x] Add an Air65 prop-off test procedure and explicit ELRS-control/video-RF
  separation.
- [ ] Receive the ordered parts and record serial/revision/USB identity for each.
- [ ] Continuity-map the supplied RC832 power and AV leads; photograph and record
  the actual plug dimensions/polarity before first power.
- [ ] On real Pi hardware, capture `v4l2-ctl --all/--list-formats-ext`, select the
  correct composite input and validate PAL plus NTSC where available.
- [ ] Show the real Air65 feed and embedded Betaflight OSD under the FpvDeck RGB
  overlay; record video FPS, drops, signal-loss/recovery and touch behavior.
- [ ] Verify real pre-overlay DVR start/stop/playback, disk-full handling and that
  recorder load cannot stall the visible feed.
- [ ] Measure the UVG-002 glass-to-glass latency distribution as a Prototype 0
  baseline; do not treat it as final-product acceptance.

## Milestone 1 — desktop vertical slice

- [x] Build and launch FPVDeck on Linux with `./scripts/dev`.
- [x] Implement shell navigation: Home, FPV, Balance, Media, Flights, Batteries,
  Aircraft, DVR, Diagnostics, and Settings.
- [x] Render synthetic moving video with a color overlay that remains interactive.
- [x] Simulate PAL/NTSC, weak signal, loss, rolling, black frames, and reconnect.
- [x] Simulate 1S–6S packs, imbalance, unplug, under/overvoltage, noise, and bad taps.
- [x] Implement SQLite schema, versioned migrations, and initial flight persistence.
- [x] Add keyboard controls and development-only simulator panel.
- [x] Add unit, integration, protocol, database, service, and QML smoke tests.
- [x] Run CI-equivalent build/test locally and fix all failures.
- [x] Add deterministic demo states and reproducible 1280×720 showcase captures.
- [x] Add touchscreen-first navigation, FPV auto-hide controls, flight lock,
  removable-SD/media simulation, receiver scan/favorites, and fault injection.
- [x] Add service tests for touch timing/lockout, storage/media faults, deck state,
  receiver selection, and battery extrema.
- [x] Split simulated 5.8 GHz receiver channel/RSSI/scan state into RadioService;
  VideoService now owns only source/standard/decoder-capture state.
- [ ] Add full battery/aircraft CRUD repositories and editing UI.
- [ ] Add segmented DVR containers, metadata journaling and interruption/power-loss
  recovery tests; Prototype 0 live pre-overlay recording is now implemented.
- [ ] Add pointer-driven QML interaction/golden tests; service behavior and all
  deterministic page states are covered, but current QML tests still launch
  complete graphs rather than synthesizing taps/swipes.
- [ ] Add simulated source disconnect/reconnect and resolution-change assertions.
- [ ] Verify and package the macOS development path.

## Milestone 2 — bench architecture

Final-product optimization is paused until Prototype 0 produces real evidence.

- [x] Establish initial compute/decoder/display/VRX shortlist from primary sources.
- [x] Correct the repository-wide RF boundary: T8L/2.4 GHz ELRS is control only;
  the dedicated 5.8 GHz analog VRX and CVBS decoder are separate added stages.
- [x] Add EU-priced `BUY NOW` and compatibility-gated order lists with primary/
  alternate purchase URLs, VAT/stock snapshots, and a realistic cost range.
- [x] Select the currently shipping Waveshare 6.25inch DSI LCD (B), SKU 35000,
  as the Prototype 1 touchscreen module from documented display/touch support.
- [ ] Measure/fit the 6.25-inch module and compare it against the 5-inch bright
  fallback; the production outdoor panel remains measurement-gated.
- [ ] Price the SMA-to-CM4 CSI fixture, then obtain/borrow `EVAL-ADV7282AMEBZ`
  or the exact older Pi-tested `EVAL-ADV7282MEBZ` only after stock confirmation.
- [ ] Confirm exact CSI cable/adapter wiring from board documentation; do not infer.
- [ ] Design and review the 100 Ω differential SMA-to-CM4IO CSI bridge (exact EVM
  SMA lane/clock mapping, CM4IO connector mapping, stack-up and return path).
- [ ] Only after that bridge gate, buy/borrow SteadyView X and ADV7282A-M EVM;
  continuity-map the supplied 3.5 mm cable before J4 use.
- [ ] Buy or borrow at least one benchmark receiver after exact adapter/pinout review.
- [ ] Measure VRX mode latency, decoder latency, display latency, lock/recovery time.
- [ ] Test PAL and NTSC with weak/nonstandard VTX signals.
- [ ] Verify CM4 hardware encoder can record without adding display-path buffers.
- [ ] Prototype pre-overlay and composited recording concurrently.
- [x] Create a part-numbered bench system BOM, Test PCB BOM, human order list,
  and procurement staging plan.
- [ ] Refresh distributor stock/pricing and ADV728x EVM/interface availability at
  purchase time; do not treat documented approximate prices as live quotations.
- [ ] Produce a verified wiring document with connector part numbers.

## T8L reverse engineering

- [ ] Photograph both PCB sides at high resolution with scale reference.
- [ ] Measure PCB, gimbal, mount, switch, antenna, connector, and battery geometry.
- [ ] Confirm whether the two 18650 cells are series or parallel by measurement.
- [ ] Determine USB behavior: RF active/inactive in HID/VCP/web configuration modes.
- [ ] Identify connector grounds and rails power-off before any powered probing.
- [ ] Determine whether CRSF telemetry is accessible without disturbing RF timing.
- [ ] Characterize T8L current at each RF power and operating mode.
- [ ] Run thumb/pinch user trials and measure gimbal finger envelopes, palm support,
  grip angle, center of mass, neck-strap balance, and screen sight line.

## Repository and project presentation

- [x] Configure canonical `origin` for `git@github.com:wiekstras/FpvDeck.git`
  after inspecting local remotes and branches.
- [x] Add a status-accurate product README, concept disclaimer, editable branding,
  source-controlled diagrams, UI captures, contributor guide, security policy,
  issue forms, and pull-request checklist.
- [x] Preserve the existing MIT license while renaming the contributor identity to
  FpvDeck.
- [ ] Export/upload the source-controlled social preview in GitHub repository settings.
- [ ] Replace concept renders with measured CAD renders after T8L and module geometry
  is captured; retain concept history and labeling.

## Electrical and PCB

- [x] Select ADS8688A for Test PCB Rev A and model the calibrated divider/ADC
  error budget; retain ADS7066 as a lower-power future integration candidate.
- [x] Create a real Test PCB Rev A KiCad PCB/project with verified lead packages,
  explicit nets, probe points, modular headers, and manufacturing gates.
- [x] Remove unverified VRX power/RSSI/UART assumptions from Rev A; J4/J5 now
  express only pin 2 ground and pin 3 CVBS, with all other pins NC.
- [x] Export source-controlled top/bottom/component-map views and add layout,
  component-map, build and readiness documents with visible release gates.
- [x] Add CI verification that the Test PCB BOM quantities/reference ranges match
  every footprint in the committed generated board.
- [ ] Create the native KiCad schematic from the independently checked pin/net
  map; run ERC before routing. The placed/unrouted board is **NOT RELEASED**.
- [ ] Independently verify ACAS 0612 resistor-array pad pairing and every ADC/MCU
  pad mapping against manufacturer package drawings.
- [ ] Resolve protected external-pack negative/reference connection and prove no
  unsafe backfeed path before any LiPo connection. Rev A now has DNP
  `1206L010/60WR` plus TP33/TP34 for a current-limited experiment; this does not
  close the release gate.
- [ ] Route planes/tracks, run DRC, print 1:1 footprints, and complete independent
  design review before generating an orderable fabrication release.
- [ ] Bench-evaluate the ADS8688A frontend and compare measured calibration drift
  with `tools/balance_frontend_error.py`.
- [x] Add normal-state pack-return/PPTC-drop calculations and a controlled
  ground-fault experiment matrix; hardware validation and gate closure remain open.
- [ ] Specify hot-plug/reverse/ESD protection with worst-case fault calculations.
- [ ] Build 1S–8S precision source test jig and calibration procedure.
- [x] Select STM32G0B1 family lead and add host-tested firmware protocol core.
- [ ] Freeze exact STM32G0B1 package/part after I/O and flash budget.
- [ ] Finalize the required two-cell 18650 power budget from measured module
  consumption and confirmed donor series/parallel topology.
- [ ] Select charger, USB-C PD, 5 V converter, quiet RF/analog rails, and load switches.
- [ ] Create Controller-I/O Rev A schematics only from verified datasheets.
- [ ] Run ERC, peer checklist, footprint audit, and bring-up review before fabrication.
- [ ] Route J4→J5 only after stack-up/75 Ω geometry and the actual decoder
  termination are frozen; the current zero-track board cannot pass CVBS.

## Reliability and release

- [ ] Implement watchdog, bounded service restarts, safe shutdown, and brownout tests.
- [x] Add repeated desktop first-frame/RSS benchmark tooling and initial system
  acceptance thresholds. Touch-to-pixel, frame pacing and target-hardware probes
  remain to implement.
- [x] Add a versioned bring-up command subset, host-tested board dispatch layer,
  simulated `fpvdeck-hw-test`, and a staged hardware bring-up procedure.
- [x] Align firmware/host ADC identities with the audited board map: B− on ADC0,
  deck monitor on ADC1, and balance taps on ADC2–ADC7.
- [ ] Bind firmware board HAL callbacks to STM32G0 peripherals and validate the
  commands on NUCLEO-G0B1RE before porting to the Rev A MCU footprint.
- [ ] Run `fpvdeck-hw-test` against physical hardware and add fixture-assisted
  per-channel pass/fail limits.
- [ ] Create reproducible embedded image and A/B update/recovery design.
- [ ] Add KiCad CI checks and firmware cross-build once toolchains are pinned.

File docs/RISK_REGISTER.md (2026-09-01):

# Risk register

| ID | Risk | Severity | Likelihood | Mitigation / exit evidence |
| --- | --- | --- | --- | --- |
| V1 | Digital path exceeds usable FPV latency | Critical | High | photodiode distributions; depth-one DMABUF/KMS path; reject parts/modes over budget |
| V2 | Decoder line-doubling artifacts obscure detail | High | Medium | PAL/NTSC flight-scene A/B; tune filters; compare active alternatives without frame buffering |
| V3 | ADV7280A lifecycle ends prototype path | High | High | isolate decoder board; develop TW9992 driver/carrier; lifetime buy is not default strategy |
| R1 | Digital noise degrades 5.8 GHz VRX | Critical | Medium | module baseline, physical zones, filtered rails, shield option, spectrum/RSSI A/B |
| R2 | Display/Wi-Fi noise degrades 2.4 GHz ELRS | Critical | Medium | Wi-Fi off, preserve antenna geometry, conducted/radiated tests at each subsystem state |
| P1 | T8L power topology/load margin misunderstood | Critical | Medium | non-invasive measurement; independent supplies until verified; no unknown pin drive |
| P2 | Linux power loss corrupts storage | High | Medium | MCU shutdown state machine, segmented DVR, WAL/FULL sync, 1,000-cycle fault test |
| B1 | Balance connector hot-plug/reverse causes damage | Critical | Medium | protected EVM, arbitrary-order test matrix, fault calculations, keyed enclosure |
| S1 | Recorder/app back-pressures live video | Critical | Medium | process/queue isolation, newest-frame policy, forced I/O/CPU fault tests |
| D1 | Selected 6.25-inch module has unacceptable latency/outdoor/landscape behavior | High | Medium | CM4-supported bench module; photodiode, luminance, thermal and scan-direction tests; Winstar production sample later |
| D2 | Touch produces false input or poor field/glove response | High | Medium | large controls, flight lock, physical critical paths, water/RF/glove bench matrix |
| M1 | Added mass/heat makes T8L ergonomics poor | High | Medium | measured CAD envelope, center-of-gravity mockup, two-cell energy budget, thermal dummy |
| C1 | Current VRX modules become unavailable | High | Medium | modular 75 Ω CVBS handoff, separate documented power and only optional verified control; qualify two receivers |
| C2 | ADV7282A-M EVM cannot be safely/cheaply bridged to CM4IO | Critical | High | hold VRX/decoder purchase; review 100 Ω SMA-to-CSI fixture, stock and lane mapping; evaluate alternate active decoder/SoM pair |
| E1 | Pre-release PCB pad/net/footprint error reaches fabrication | Critical | Medium | NOT RELEASED marker, native schematic/ERC, source pin-map test, independent audit, 1:1 print, DRC and signed release checklist |

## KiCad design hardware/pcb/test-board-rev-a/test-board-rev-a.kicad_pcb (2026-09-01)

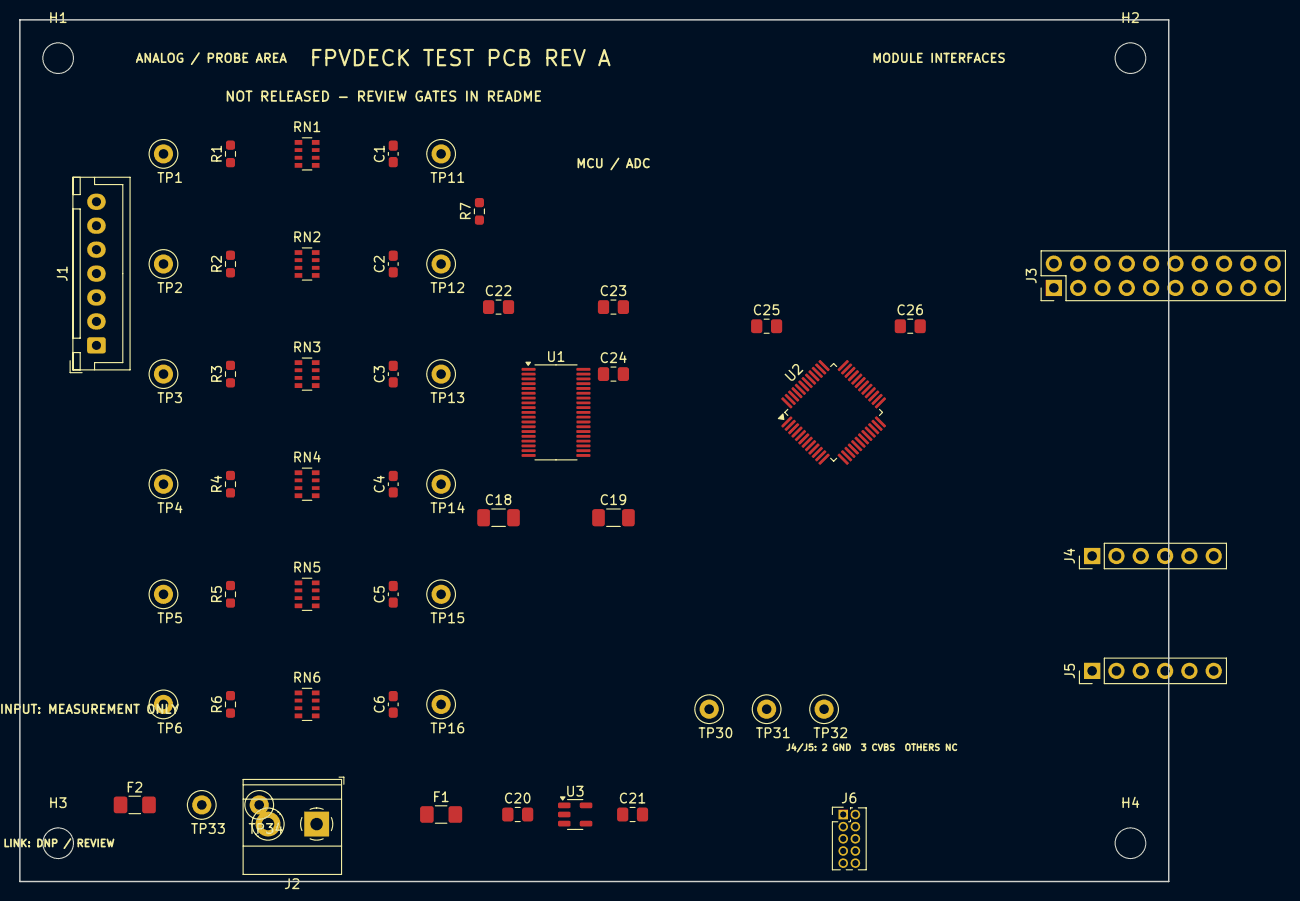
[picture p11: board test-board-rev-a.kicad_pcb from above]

Board: 4 copper layers, 120.0 x 90.0 mm, 60 parts (0 on the bottom side), 52 nets, no tracks yet.

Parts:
C1, C2, C3, C4, C5, C6: 10n C0G 50V; C_0603_1608Metric_Pad1.08x0.95mm_HandSolder
C18, C19: 22u 10V X7R; C_1206_3216Metric_Pad1.33x1.80mm_HandSolder
C20, C21, C22, C23, C24: 1u 10V X7R; C_0805_2012Metric_Pad1.18x1.45mm_HandSolder
C25: 100n 16V X7R; C_0805_2012Metric_Pad1.18x1.45mm_HandSolder
C26: 4.7u 10V X7R; C_0805_2012Metric_Pad1.18x1.45mm_HandSolder
F1: MF-MSMF050-2; Fuse_1206_3216Metric_Pad1.42x1.75mm_HandSolder
F2: 1206L010/60WR DNP; Fuse_1206_3216Metric_Pad1.42x1.75mm_HandSolder
H1, H2, H3, H4: M3; MountingHole_3.2mm_M3
J1: B7B-XH-A(LF)(SN); JST_XH_B7B-XH-A_1x07_P2.50mm_Vertical
J2: 5V BENCH IN; TerminalBlock_Phoenix_MKDS-1,5-2-5.08_1x02_P5.08mm_Horizont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
J3: SBC LINK; PinHeader_2x10_P2.54mm_Vertical
J4: VRX CVBS ONLY; PinHeader_1x06_P2.54mm_Vertical
J5: DECODER CVBS ONLY; PinHeader_1x06_P2.54mm_Vertical
J6: SWD; PinHeader_2x05_P1.27mm_Vertical
R1, R2, R3, R4, R5, R6, R7: 1K00 0.1%; R_0603_1608Metric_Pad0.98x0.95mm_HandSolder
RN1, RN2, RN3, RN4, RN5, RN6: ACASA1002U1002P1AT; R_Array_Convex_4x0603
TP1: TAP1_RAW; TestPoint_Loop_D2.50mm_Drill1.0mm
TP2: TAP2_RAW; TestPoint_Loop_D2.50mm_Drill1.0mm
TP3: TAP3_RAW; TestPoint_Loop_D2.50mm_Drill1.0mm
TP4: TAP4_RAW; TestPoint_Loop_D2.50mm_Drill1.0mm
TP5: TAP5_RAW; TestPoint_Loop_D2.50mm_Drill1.0mm
TP6: TAP6_RAW; TestPoint_Loop_D2.50mm_Drill1.0mm
TP11: TAP1_ADC; TestPoint_Loop_D2.50mm_Drill1.0mm
TP12: TAP2_ADC; TestPoint_Loop_D2.50mm_Drill1.0mm
TP13: TAP3_ADC; TestPoint_Loop_D2.50mm_Drill1.0mm
TP14: TAP4_ADC; TestPoint_Loop_D2.50mm_Drill1.0mm
TP15: TAP5_ADC; TestPoint_Loop_D2.50mm_Drill1.0mm
TP16: TAP6_ADC; TestPoint_Loop_D2.50mm_Drill1.0mm
TP30: 5V; TestPoint_Loop_D2.50mm_Drill1.0mm
TP31: 3V3; TestPoint_Loop_D2.50mm_Drill1.0mm
TP32: GND; TestPoint_Loop_D2.50mm_Drill1.0mm
TP33: BNEG_RAW; TestPoint_Loop_D2.50mm_Drill1.0mm
TP34: LOCAL_GND; TestPoint_Loop_D2.50mm_Drill1.0mm
U1: ADS8688AIDBT; TSSOP-38_4.4x9.7mm_P0.5mm
U2: STM32G0B1CBT6; LQFP-48_7x7mm_P0.5mm
U3: TLV75533PDBVR; SOT-23-5

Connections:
+3V3: C21.1, C24.1, C25.1, C26.1, J3.3, J6.1, TP31.1, U1.34, U2.4, U2.5, U2.6, U3.5
+5V_FUSED: C20.1, C22.1, C23.1, F1.2, J3.1, TP30.1, U1.9, U1.30, U3.1, U3.3
+5V_RAW: F1.1, J2.1
ADC_ALARM: U1.35, U2.21
ADC_CS: U1.38, U2.19
ADC_REFCAP: C19.1, U1.7
ADC_REFIO: C18.1, U1.5
ADC_RESET: U1.2, U2.20
BNEG_RAW: F2.1, J1.1, R7.1, TP33.1
BNEG_SENSE: R7.2, U1.12
GND: C1.2, C2.2, C3.2, C4.2, C5.2, C6.2, C18.2, C19.2, C20.2, C21.2, C22.2, C23.2, C24.2, C25.2, C26.2, F2.2, J2.2, J3.2, J3.4, J4.2, J5.2, J6.3, J6.5, RN1.5, RN2.5, RN3.5, RN4.5, RN5.5, RN6.5, TP32.1, TP34.1, U1.3, U1.4, U1.6, U1.8, U1.11, U1.13, U1.15, U1.17, U1.19, U1.20, U1.22, U1.24, U1.26, U1.28, U1.29, U1.31, U1.32, U1.33, U2.7, U3.2
I2C_SCL: J3.9, U2.47
I2C_SDA: J3.10, U2.48
NRST: J6.10, U2.10
SPI_MISO: U1.36, U2.17
SPI_MOSI: U1.1, U2.18
SPI_SCLK: U1.37, U2.16
SWCLK: J6.4, U2.36
SWDIO: J6.2, U2.35
TAP1_ADC: C1.1, RN1.4, RN1.6, TP11.1, U1.16
TAP1_RAW: J1.2, R1.1, TP1.1
TAP1_SER: R1.2, RN1.1
TAP1_STAGE1: RN1.2, RN1.8
TAP1_STAGE2: RN1.3, RN1.7
TAP2_ADC: C2.1, RN2.4, RN2.6, TP12.1, U1.18
TAP2_RAW: J1.3, R2.1, TP2.1
TAP2_SER: R2.2, RN2.1
TAP2_STAGE1: RN2.2, RN2.8
TAP2_STAGE2: RN2.3, RN2.7
TAP3_ADC: C3.1, RN3.4, RN3.6, TP13.1, U1.21
TAP3_RAW: J1.4, R3.1, TP3.1
TAP3_SER: R3.2, RN3.1
TAP3_STAGE1: RN3.2, RN3.8
TAP3_STAGE2: RN3.3, RN3.7
TAP4_ADC: C4.1, RN4.4, RN4.6, TP14.1, U1.23
TAP4_RAW: J1.5, R4.1, TP4.1
TAP4_SER: R4.2, RN4.1
TAP4_STAGE1: RN4.2, RN4.8
TAP4_STAGE2: RN4.3, RN4.7
TAP5_ADC: C5.1, RN5.4, RN5.6, TP15.1, U1.25
TAP5_RAW: J1.6, R5.1, TP5.1
TAP5_SER: R5.2, RN5.1
TAP5_STAGE1: RN5.2, RN5.8
TAP5_STAGE2: RN5.3, RN5.7
TAP6_ADC: C6.1, RN6.4, RN6.6, TP16.1, U1.27
TAP6_RAW: J1.7, R6.1, TP6.1
TAP6_SER: R6.2, RN6.1
TAP6_STAGE1: RN6.2, RN6.8
TAP6_STAGE2: RN6.3, RN6.7
UART_RX: J3.6, U2.14
UART_TX: J3.5, U2.13
VRX_VIDEO: J4.3, J5.3

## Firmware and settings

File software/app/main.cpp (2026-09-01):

#include "services/BatteryService.h"
#include "services/DatabaseService.h"
#include "services/DvrService.h"
#include "services/InputService.h"
#include "services/InteractionService.h"
#include "services/MediaService.h"
#include "services/RadioService.h"
#include "services/StorageService.h"
#include "services/SystemService.h"
#include "services/TelemetryService.h"
#include "services/VideoService.h"

#include <QCommandLineParser>
#include <QDir>
#include <QElapsedTimer>
#include <QFile>
#include <QGuiApplication>
#include <QJsonDocument>
#include <QJsonObject>
#include <QCamera>
#include <QCameraDevice>
#include <QMediaDevices>
#include <QQmlApplicationEngine>
#include <QQmlContext>
#include <QQuickWindow>
#include <QStandardPaths>
#include <QTimer>

#include <memory>

int main(int argc, char* argv[])
{
    QElapsedTimer startupTimer;
    startupTimer.start();
    QGuiApplication application(argc, argv);
    QCoreApplication::setOrganizationName("FpvDeck");
    QCoreApplication::setApplicationName("FPVDeck");
    QCoreApplication::setApplicationVersion("0.1.0");

    QCommandLineParser parser;
    parser.setApplicationDescription("FPVDeck hardware-independent simulator");
    parser.addHelpOption();
    parser.addVersionOption();
    QCommandLineOption videoOption({"i", "video"}, "Synthetic/test video file", "path");
    QCommandLineOption videoDeviceOption("video-device",
        "Linux V4L2 capture device (for example /dev/video0)", "device");
    QCommandLineOption videoStandardOption("video-standard",
        "Capture video standard shown by diagnostics (PAL or NTSC)", "standard", "PAL");
    QCommandLineOption databaseOption({"d", "database"}, "SQLite database path", "path");
    QCommandLineOption exitOption("exit-after-ms", "Exit automatically (test use)", "milliseconds");
    QCommandLineOption screenshotOption("screenshot", "Save a rendered screenshot", "path");
    QCommandLineOption benchmarkOption("benchmark-json", "Write first-frame benchmark JSON and exit", "path");
    QCommandLineOption demoStateOption("demo-state", "Open a deterministic showcase state", "state", "fpv");
    parser.addOption(videoOption);
    parser.addOption(videoDeviceOption);
    parser.addOption(videoStandardOption);
    parser.addOption(databaseOption);
    parser.addOption(exitOption);
    parser.addOption(screenshotOption);
    parser.addOption(benchmarkOption);
    parser.addOption(demoStateOption);
    parser.process(application);

    const QString dataDirectory = qEnvironmentVariableIsSet("FPVDECK_DATA_DIR")
        ? qEnvironmentVariable("FPVDECK_DATA_DIR")
        : QStandardPaths::writableLocation(QStandardPaths::AppLocalDataLocation);
    QDir().mkpath(dataDirectory);
    const QString databasePath = parser.isSet(databaseOption)
        ? parser.value(databaseOption) : dataDirectory + "/fpvdeck.sqlite3";
    const QString videoPath = parser.isSet(videoOption)
        ? parser.value(videoOption) : QDir::currentPath() + "/generated/fpv-test-pal.mp4";
    const QString recordingDirectory = dataDirectory + "/recordings";
    QDir().mkpath(recordingDirectory);

    BatteryService batteryService;
    DvrService dvrService;
    dvrService.setOutputDirectory(recordingDirectory);
    InputService inputService;
    InteractionService interactionService;
    MediaService mediaService(QUrl::fromLocalFile(videoPath));
    RadioService radioService;
    StorageService storageService;
    SystemService systemService;
    TelemetryService telemetryService;
    VideoService videoService(QUrl::fromLocalFile(videoPath));
    const QString requestedStandard = parser.value(videoStandardOption).trimmed().toUpper();
    if (requestedStandard != "PAL" && requestedStandard != "NTSC") {
        qCritical("Video standard must be PAL or NTSC");
        return 11;
    }
    videoService.setStandard(requestedStandard);
    QCamera prototypeCamera;
    QMediaDevices mediaDevices;
    if (parser.isSet(videoDeviceOption)) {
        const QString requestedDevice = parser.value(videoDeviceOption);
        const auto configureCaptureDevice = [&prototypeCamera, &videoService,
                                                &mediaDevices, requestedDevice] {
            QCameraDevice selectedDevice;
            for (const QCameraDevice& device : mediaDevices.videoInputs()) {
                if (QString::fromUtf8(device.id()) == requestedDevice) {
                    selectedDevice = device;
                    break;
                }
            }
            if (selectedDevice.isNull()) {
                prototypeCamera.stop();
                videoService.useV4l2(requestedDevice,
                    QStringLiteral("Capture device unavailable"), false);
                return;
            }
            if (prototypeCamera.cameraDevice().id() == selectedDevice.id()
                && prototypeCamera.isActive()) {
                videoService.reportCaptureAvailability(true);
                return;
            }
            prototypeCamera.stop();
            prototypeCamera.setCameraDevice(selectedDevice);
            videoService.useV4l2(requestedDevice, selectedDevice.description(), true);
            prototypeCamera.start();
        };
        QObject::connect(&mediaDevices, &QMediaDevices::videoInputsChanged,
            &application, configureCaptureDevice);
        QObject::connect(&prototypeCamera, &QCamera::errorOccurred, &videoService,
            [&videoService](QCamera::Error error, const QString& errorString) {
                if (error == QCamera::NoError) return;
                qWarning("V4L2 capture error: %s", qPrintable(errorString));
                videoService.reportCaptureAvailability(false);
            });
        configureCaptureDevice();
        if (!videoService.captureAvailable())
            qWarning("V4L2 device is unavailable: %s", qPrintable(requestedDevice));
    } else if (!parser.isSet(videoOption)) {
        videoService.useSimulated(QUrl::fromLocalFile(videoPath));
    }
    DatabaseService databaseService(databasePath);
    QString databaseError;
    if (!databaseService.initialize(&databaseError)) {
        qCritical("Database initialization failed: %s", qPrintable(databaseError));
        return 2;
    }
    const QString demoState = parser.value(demoStateOption).trimmed().toLower();
    const QStringList validDemoStates = {
        "home", "fpv", "fpv-controls", "fpv-lock", "battery", "media",
        "media-playback", "receiver", "flights", "diagnostics"
    };
    if (parser.isSet(demoStateOption) && !validDemoStates.contains(demoState)) {
        qCritical("Unknown showcase state: %s", qPrintable(demoState));
        return 7;
    }
    if (parser.isSet(demoStateOption) && !databaseService.seedShowcaseData()) {
        qCritical("Could not seed showcase data");
        return 6;
    }
    if (parser.isSet(demoStateOption) && demoState == "battery") batteryService.setScenario("imbalanced");
    if (parser.isSet(demoStateOption) && demoState.startsWith("fpv")) dvrService.toggleRecording();
    if (parser.isSet(demoStateOption) && demoState == "fpv-controls") interactionService.showControls();
    if (parser.isSet(demoStateOption) && demoState == "fpv-lock") {
        interactionService.setFlightLocked(true);
        interactionService.showControls();
    }
    if (parser.isSet(demoStateOption) && demoState == "media-playback") {
        mediaService.openFile("RIDGE RUN", 381, "4:3");
    }

    QQmlApplicationEngine engine;
    engine.rootContext()->setContextProperty("BatteryService", &batteryService);
    engine.rootContext()->setContextProperty("DvrService", &dvrService);
    engine.rootContext()->setContextProperty("InputService", &inputService);
    engine.rootContext()->setContextProperty("InteractionService", &interactionService);
    engine.rootContext()->setContextProperty("MediaService", &mediaService);
    engine.rootContext()->setContextProperty("RadioService", &radioService);
    engine.rootContext()->setContextProperty("StorageService", &storageService);
    engine.rootContext()->setContextProperty("SystemService", &systemService);
    engine.rootContext()->setContextProperty("TelemetryService", &telemetryService);
    engine.rootContext()->setContextProperty("VideoService", &videoService);
    engine.rootContext()->setContextProperty("PrototypeCamera", &prototypeCamera);
    engine.rootContext()->setContextProperty("DatabaseService", &databaseService);
    engine.rootContext()->setContextProperty("StartupDemoState", demoState);
    engine.rootContext()->setContextProperty("StartupDemoMode", parser.isSet(demoStateOption));
    engine.load(QUrl(QStringLiteral("qrc:/FPVDeck/ui/Main.qml")));
    if (engine.rootObjects().isEmpty()) return 3;
    const qint64 qmlLoadedMs = startupTimer.elapsed();
    if (parser.isSet(benchmarkOption)) {
        auto* window = qobject_cast<QQuickWindow*>(engine.rootObjects().constFirst());
        if (window == nullptr) return 8;
        auto completed = std::make_shared<bool>(false);
        const auto writeBenchmark = [&, completed, window](bool timedOut) {
            if (*completed) return;
            *completed = true;
            qint64 rssKiB = -1;
            QFile statusFile(QStringLiteral("/proc/self/status"));
            if (statusFile.open(QIODevice::ReadOnly | QIODevice::Text)) {
                const auto lines = statusFile.readAll().split('\n');
                for (const QByteArray& line : lines) {
                    if (!line.startsWith("VmRSS:")) continue;
                    const auto fields = line.simplified().split(' ');
                    if (fields.size() >= 2) rssKiB = fields.at(1).toLongLong();
                    break;
                }
            }
            QJsonObject metrics{
                {"schema_version", 1},
                {"demo_state", demoState},
                {"qml_loaded_ms", qmlLoadedMs},
                {"first_frame_ms", startupTimer.elapsed()},
                {"rss_kib", rssKiB},
                {"width", window->width()},
                {"height", window->height()},
                {"timed_out", timedOut},
            };
            QFile output(parser.value(benchmarkOption));
            if (!output.open(QIODevice::WriteOnly | QIODevice::Truncate)) {
                qCritical("Could not write benchmark JSON: %s", qPrintable(output.errorString()));
                application.exit(9);
                return;
            }
            output.write(QJsonDocument(metrics).toJson(QJsonDocument::Indented));
            output.close();
            application.exit(timedOut ? 10 : 0);
        };
        QObject::connect(window, &QQuickWindow::frameSwapped, &application,
            [writeBenchmark] { writeBenchmark(false); }, Qt::SingleShotConnection);
        QTimer::singleShot(5000, &application, [writeBenchmark] { writeBenchmark(true); });
        window->update();
    } else if (parser.isSet(screenshotOption)) {
        QTimer::singleShot(1500, &application, [&application, &engine, &parser] {
            auto* window = qobject_cast<QQuickWindow*>(engine.rootObjects().constFirst());
            if (!window || !window->grabWindow().save(parser.value("screenshot"))) {
                application.exit(4);
                return;
            }
            application.quit();
        });
    } else if (parser.isSet(exitOption)) {
        bool valid = false;
        const int milliseconds = parser.value(exitOption).toInt(&valid);
        if (!valid || milliseconds < 1) return 5;
        QTimer::singleShot(milliseconds, &application, &QCoreApplication::quit);
    }
    return application.exec();
}

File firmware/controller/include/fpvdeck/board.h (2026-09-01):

#ifndef FPVDECK_BOARD_H
#define FPVDECK_BOARD_H

#include "fpvdeck/protocol.h"

#include <stdbool.h>
#include <stdint.h>

#define FPVDECK_MSG_BOARD_REQUEST 0x40u
#define FPVDECK_MSG_BOARD_REPLY 0x41u

typedef enum {
    FPVDECK_ADC_BNEG = 0u,
    FPVDECK_ADC_DECK = 1u,
    FPVDECK_ADC_TAP1 = 2u,
    FPVDECK_ADC_TAP2 = 3u,
    FPVDECK_ADC_TAP3 = 4u,
    FPVDECK_ADC_TAP4 = 5u,
    FPVDECK_ADC_TAP5 = 6u,
    FPVDECK_ADC_TAP6 = 7u
} fpvdeck_adc_channel_t;

typedef enum {
    FPVDECK_BOARD_IDENTIFY = 0x01,
    FPVDECK_BOARD_SELF_TEST = 0x02,
    FPVDECK_BOARD_ADC_RAW = 0x10,
    FPVDECK_BOARD_ADC_MILLIVOLTS = 0x11,
    FPVDECK_BOARD_TAP_DUMP = 0x12,
    FPVDECK_BOARD_TEMPERATURES = 0x20,
    FPVDECK_BOARD_LED_SET = 0x30,
    FPVDECK_BOARD_BUZZER_SET = 0x31,
    FPVDECK_BOARD_FAN_SET = 0x32,
    FPVDECK_BOARD_BUTTONS = 0x40,
    FPVDECK_BOARD_SD_DETECT = 0x41,
    FPVDECK_BOARD_RAILS = 0x42
} fpvdeck_board_command_t;

typedef enum {
    FPVDECK_BOARD_STATUS_OK = 0,
    FPVDECK_BOARD_STATUS_BAD_COMMAND = 1,
    FPVDECK_BOARD_STATUS_BAD_ARGUMENT = 2,
    FPVDECK_BOARD_STATUS_NOT_READY = 3,
    FPVDECK_BOARD_STATUS_HARDWARE_FAULT = 4
} fpvdeck_board_status_t;

enum {
    FPVDECK_SELFTEST_MCU = 1u << 0,
    FPVDECK_SELFTEST_ADC = 1u << 1,
    FPVDECK_SELFTEST_BALANCE = 1u << 2,
    FPVDECK_SELFTEST_SD_DETECT = 1u << 3,
    FPVDECK_SELFTEST_TEMPERATURE = 1u << 4,
    /* Rev A has a passive CVBS-only breakout, not a testable VRX control link. */
    FPVDECK_SELFTEST_CVBS_BREAKOUT = 1u << 5,
    FPVDECK_SELFTEST_BUTTONS = 1u << 6,
    FPVDECK_SELFTEST_POWER = 1u << 7
};

typedef struct {
    void *context;
    bool (*read_adc)(void *context, uint8_t channel, uint32_t *raw, int32_t *millivolts);
    bool (*read_temperatures)(void *context, int16_t *mcu_centi_c, int16_t *external_centi_c);
    bool (*read_rails)(void *context, uint16_t *rail_5v_mv, uint16_t *rail_3v3_mv, uint16_t *deck_mv);
    uint32_t (*read_buttons)(void *context);
    bool (*read_sd_detect)(void *context);
    bool (*set_output)(void *context, fpvdeck_board_command_t command, uint8_t value);
    void (*self_test)(void *context, uint32_t *pass_mask, uint32_t *interactive_mask, uint32_t *fail_mask);
} fpvdeck_board_hal_t;

fpvdeck_board_status_t fpvdeck_board_handle(
    const fpvdeck_board_hal_t *hal,
    const fpvdeck_frame_t *request,
    fpvdeck_frame_t *reply);

#endif

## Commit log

2026-09-01 feat: add touch simulator and bench-test foundation
    [test-board-rev-a.kicad_pcb]
2026-09-01 docs(hw): select touch display and stage bench procurement
    [PROTOTYPE_SYSTEM.csv, TEST_PCB_REV_A.csv]
2026-09-01 docs(video): correct decoder EVM procurement path
    [PROTOTYPE_SYSTEM.csv]
2026-09-01 feat(hw): add protected pack reference test option
    [TEST_PCB_REV_A.csv, test-board-rev-a.kicad_pcb]
2026-09-01 perf(ui): add reproducible first-frame benchmark
2026-09-01 fix(firmware): align ADC channels with test board
    [board.h]
2026-09-01 test(hw): verify test board BOM coverage
2026-09-01 fix(hw): connect pack-negative sense path
    [TEST_PCB_REV_A.csv, test-board-rev-a.kicad_pcb]
2026-09-01 fix(architecture): separate control radio and analog video
    [TEST_PCB_REV_A.csv, test-board-rev-a.kicad_pcb]
2026-09-01 docs(procurement): add gated EU bench order package
    [PROTOTYPE_SYSTEM.csv, PROTOTYPE_SYSTEM_EU.csv]
2026-09-01 feat(prototype0): add real Air65 bench path
2026-10-26 feat: reset FpvDeck as ESP32-P4 FPV field tool
2026-10-26 feat(ui): add hardware-button navigation and honest empty states
2026-10-27 feat(firmware): stream live battery and receiver measurements
2026-10-27 feat(monitor): add touch and button channel controls
2026-10-27 fix(hw): add verified decoder power networks
2026-10-27 feat(cad): add prototype enclosure and HAT placement model
2026-10-27 feat(ui): modernize interface for ESP32-P4
2026-10-28 fix(hw): correct LMV331 diversity pin mapping
2026-10-28 feat(hw): move antennas to left and top-right edges
2026-10-28 fix(hw): place both diversity antennas on top edge
